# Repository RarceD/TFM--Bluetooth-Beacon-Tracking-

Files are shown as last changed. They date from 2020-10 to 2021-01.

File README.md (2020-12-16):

# Introduction #
BLE tracking system based on ESP32 uC and nrf52832 iBeacon. The main idea is to stablish a net of beacons which
comunicate with the ESP32 masters via Bluetooth Low Energy on Beacon Mode.

Every beacon wake up every 1200ms and send their uuid, mayor, minor, battery and rssi. The most important parameter is the rssi because with that we can calculate the distance between masters and I can positionate them on a map.

The visualize tool is made with Python and Pygame, all the masters send data to a free to use broker and the console is listenning incoming messages in order to calculate the distance and situate them on the static map.
## Hardware ##
### ESP32 master and  nrf52832 ###
I have develop a simple esp32 board that can be powered via 220@VAC and every minute it listen to the slaves and calculate the distance between beacons.
| Board Specifications  |  ESP32 WROVER |  nrf52832 |
| :---:|:---:| :---: |
| Flash | 448kB | 256 kB | 
| RAM | 520kB | 32 kB | 
| Consumption on sleep  | 10uA | 1.9 μA at 3 V | 

### Images beacon ###
In the following image we can see the pcb of the esp32 beacon device and the master esp32 pcb:

<p align="center">
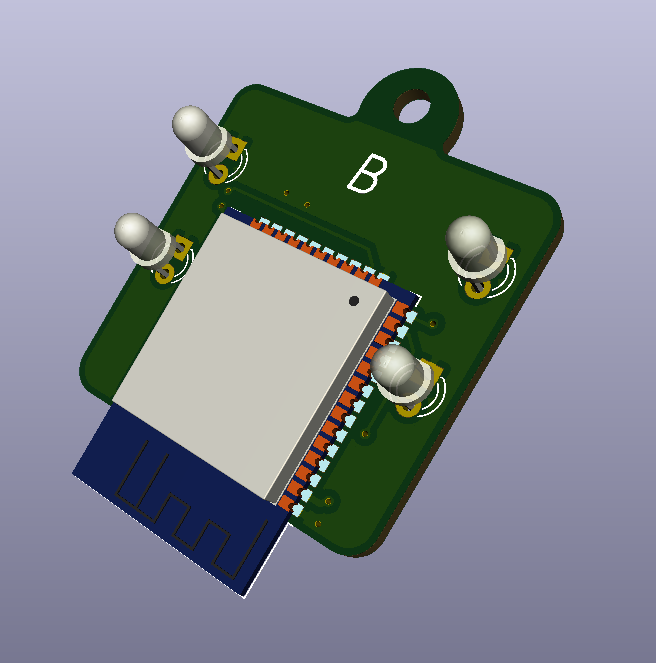
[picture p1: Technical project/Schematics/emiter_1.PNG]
    
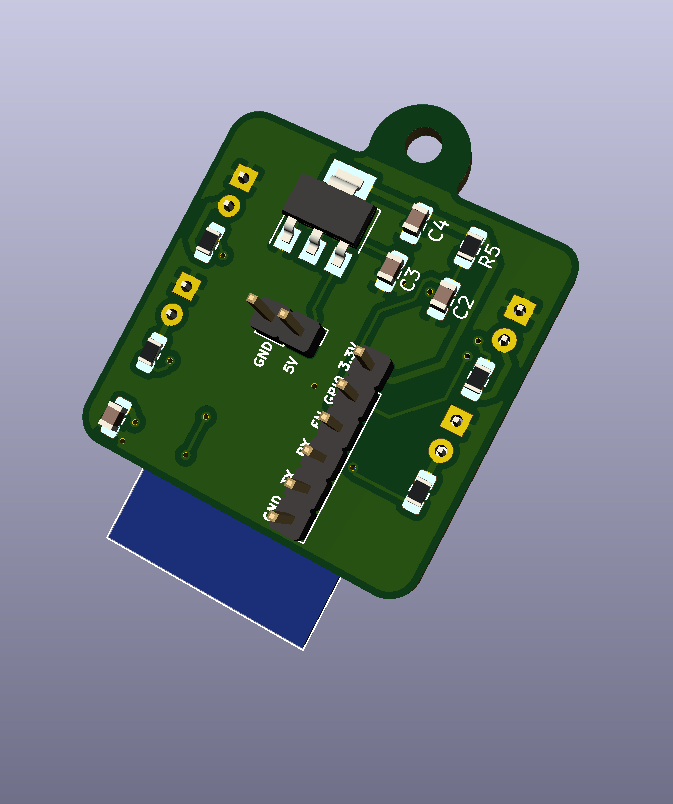
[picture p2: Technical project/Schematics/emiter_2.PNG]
    
</p>

The real boards:

<p align="center">
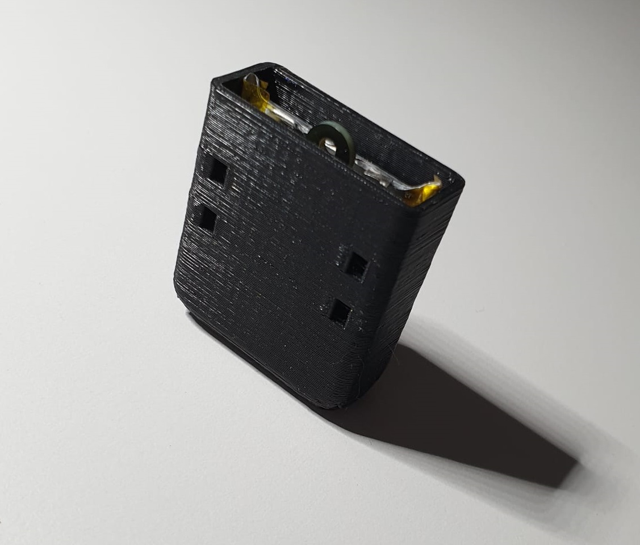
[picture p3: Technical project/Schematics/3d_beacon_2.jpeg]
    
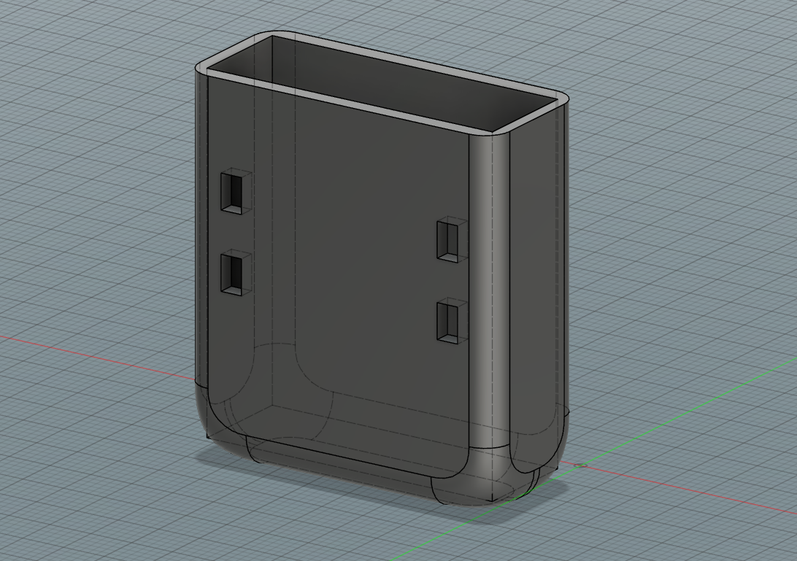
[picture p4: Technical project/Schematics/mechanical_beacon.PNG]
    
</p>

### Images master listener ###
Kicad files also included:

<p align="center">
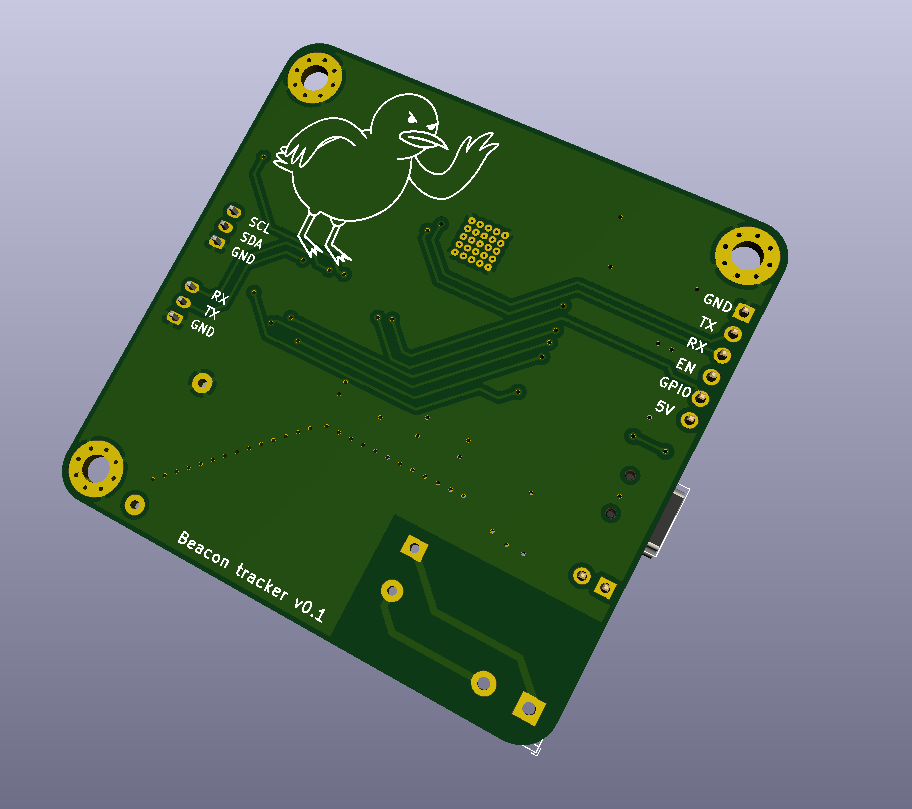
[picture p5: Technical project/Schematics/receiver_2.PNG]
    
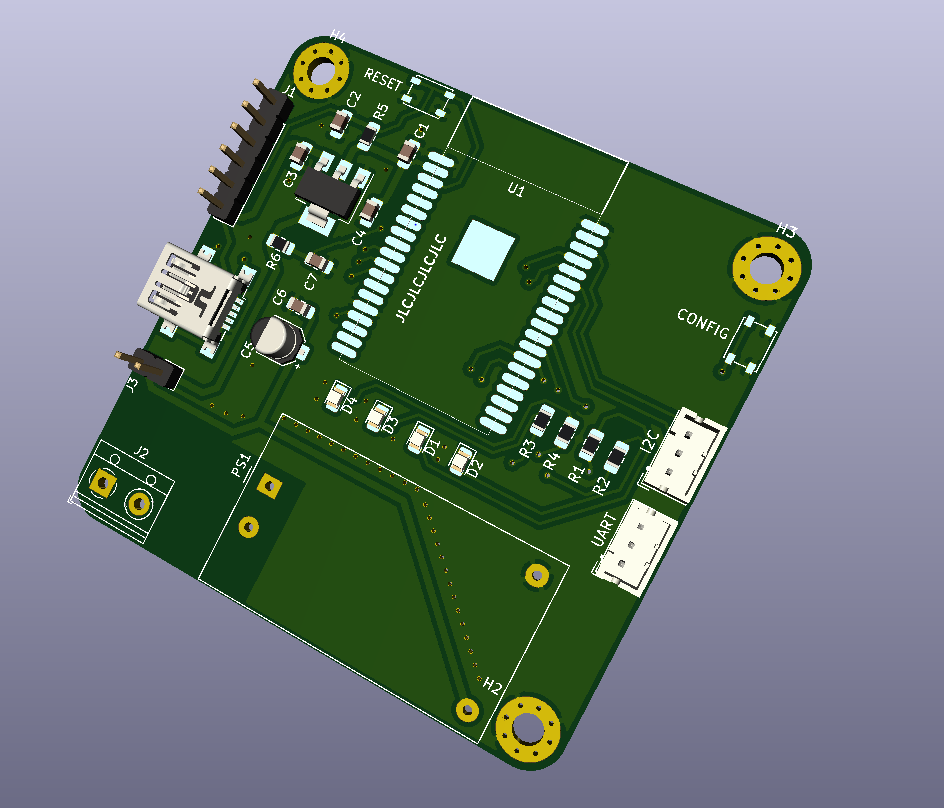
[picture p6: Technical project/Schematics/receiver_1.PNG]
    
</p>

The real boards:
<p align="center">
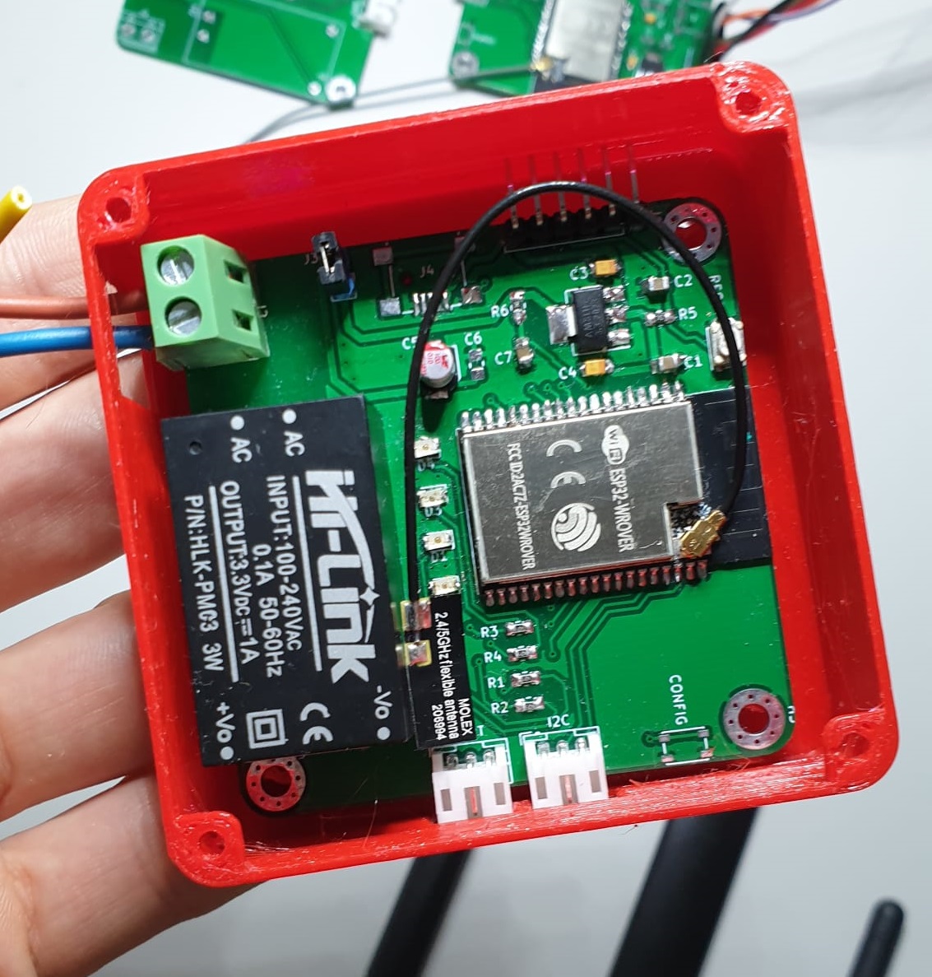
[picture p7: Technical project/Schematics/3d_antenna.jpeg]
    
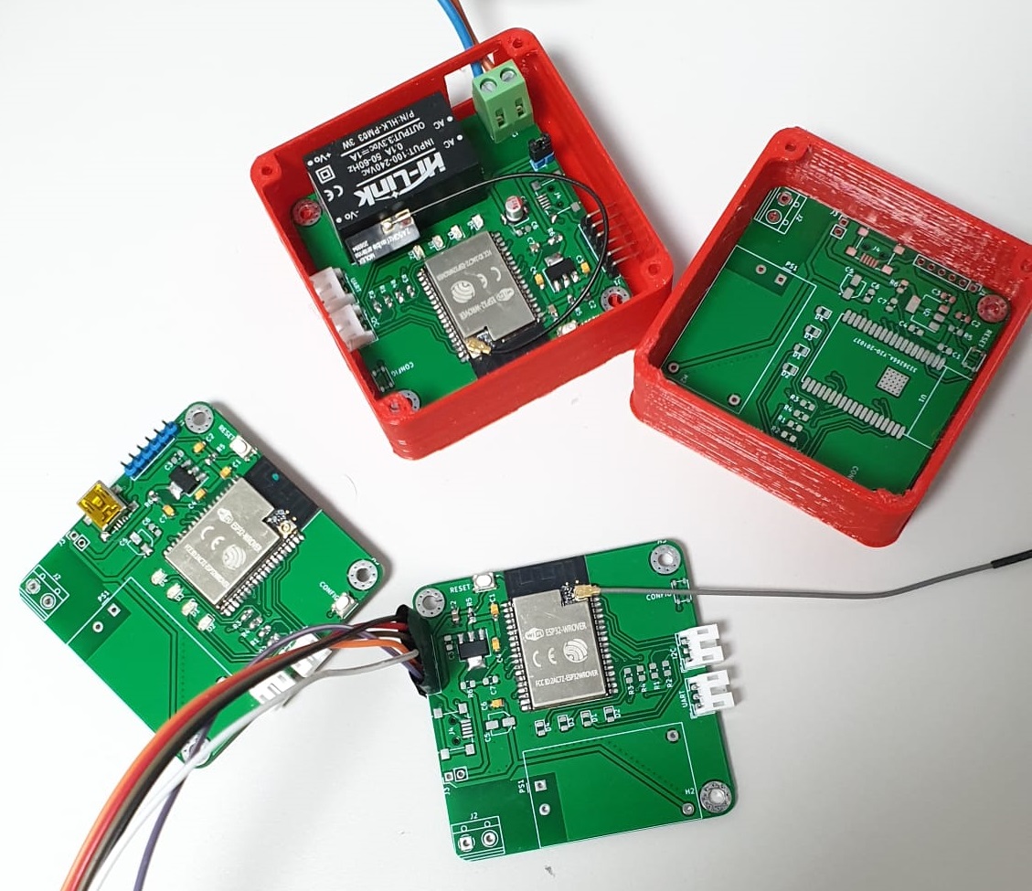
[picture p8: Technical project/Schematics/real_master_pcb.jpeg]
    
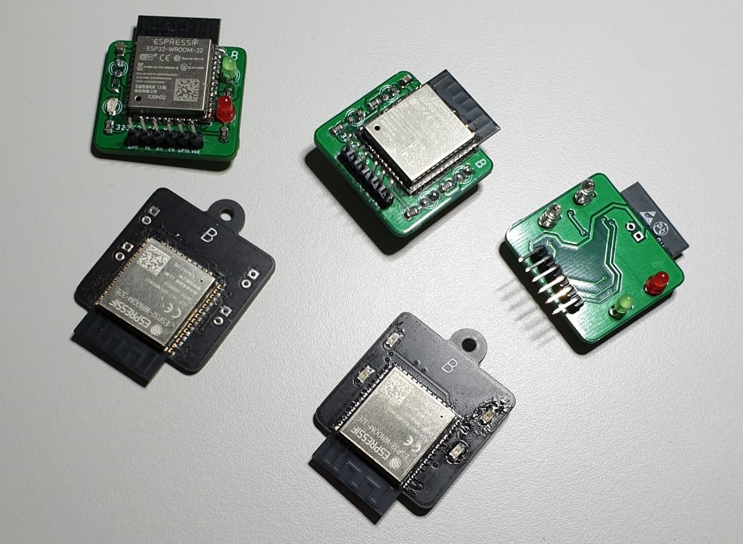
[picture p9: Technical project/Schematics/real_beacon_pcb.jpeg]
    
</p>

## Software ##
### Trilateration ###
If two elements on a net are listened by two masters the algorithm will calculate the middle distance of both of them acording to the strengh of the signal received. Appling trilateration we can obtein the position between three masters and only one beacon sending data. I don't cosider more than 3 masters detected the same beacon.

<p align="center">
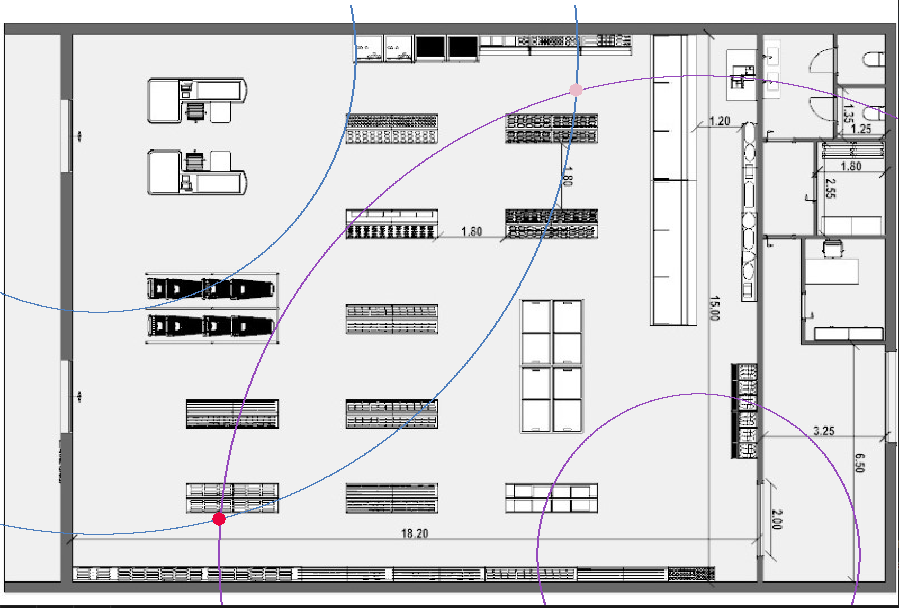
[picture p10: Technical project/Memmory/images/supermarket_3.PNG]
    
</p>

## 3D Printing ##
The electronics need a case in order not to be touch by no people, thats why I have design a simple model in Freecad:

<p align="center">
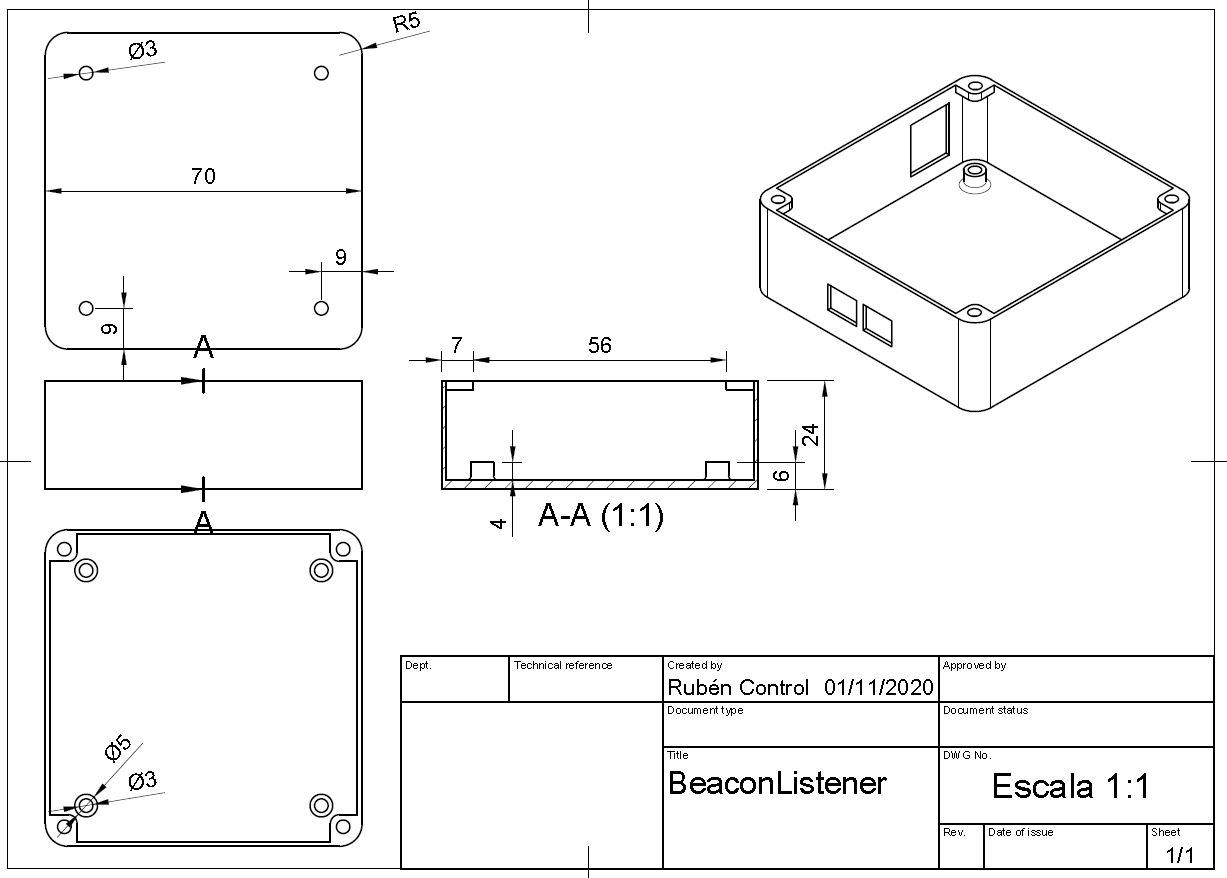
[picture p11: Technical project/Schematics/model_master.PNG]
    
</p>

## Visualizer ##
For making the fastest prototype of the visualization tool I have program a pygame console that is connected to mqtt and always listening to the master messages.
I'm using free mqtt broker: 
```python 
 broker_address = "broker.mqttdashboard.com"
```
It has fall out just one time in more than 3 months, it seems right.

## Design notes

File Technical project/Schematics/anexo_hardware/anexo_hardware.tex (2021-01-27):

\documentclass[paper=a4, fontsize=11pt,twoside]{scrartcl}	% KOMA

\usepackage[a4paper,pdftex]{geometry}	% A4paper margins
\setlength{\oddsidemargin}{5mm}			% Remove 'twosided' indentation
\setlength{\evensidemargin}{5mm}

% \usepackage[english]{babel}
\usepackage[protrusion=true,expansion=true]{microtype}	
\usepackage{amsmath,amsfonts,amsthm,amssymb}
\usepackage{graphicx}
\usepackage[spanish]{babel}
\usepackage[hidelinks]{hyperref}
\usepackage{graphicx}
\usepackage{xcolor}
\usepackage{fancyhdr}
\usepackage{hyperref}
\newcommand{\HRule}[1]{\rule{\linewidth}{#1}} 	% Horizontal rule
\usepackage{float}

\makeatletter							% Title
\def\printtitle{%						
    {\centering \@title\par}}
\makeatother									

\makeatletter							% Author
\def\printauthor{%					
    {\centering \large \@author}}				
\makeatother							

\title{	\normalsize \textsc{ANEXO 1: DISEÑO DE HARDWARE} 	% Subtitle
		 	\\[2.0cm]								% 2cm spacing
			\HRule{0.5pt} \\						% Upper rule
			\LARGE \textbf{\uppercase{Sistemas de posicionamiento de objetos mediante la tecnología Bluetooth Low Energy, modo Beacon}}	% Title
			\HRule{2pt} \\ [0.5cm]		% Lower rule + 0.5cm spacing
			\normalsize \today			% Todays date
		}
\author{
		Rubén Arce Domingo\\	
		Máster en automatización y robótica\\	
        industrial\\
        akimbo170@gmail.com \\
        % \texttt{akimbo170@gmail.com} \\
}
\begin{document}
\thispagestyle{empty}		% Remove page numbering on this page
\printtitle					% Print the title data as defined above
  	\vfill
\printauthor				% Print the author data as defined above
\newpage

% \title{Anexo desarrollo de hardware}

% \author{Rubén Arce}
% \date{\today}
% \maketitle
\cleardoublepage
\tableofcontents
\listoffigures
\cleardoublepage
\pagestyle{fancy}
\fancyfoot[R]{Rubén Arce}
\fancyfoot[L]{BLE Tracking - 2021}

\section{Introducción}
    Los diseños eléctricos y el trazado de las pistas del circuito se han llevado a cabo con Kicad en 
    su versión 5.1.6. Se ha empleado este programa debido a que, en primer lugar es de software libre y
    completamente gratuito y, en segundo lugar, debido a que puede funcionar en Linux. Además de que es capaz de llevar a cabo 
    cualquier diseño profesional sin problema de licencias o versiones incompatibles.

    Por otro lado, todas las PCBs se han fabricado en dos capas con un espesor estándar de 1,6mm y con acabado superficial
    HASH plomo estaño en los primeros prototipos. En la versión final se empleará el acabado ENIG, o de oro 
    electrolítico, para mejorar las especificaciones y durabilidad de la misma.

    Por último mencionar que se han empleado tanto componentes SMD como through hole y se ha priorizado el precio en la selección de los mismos.
\section{Emisor Beacon}
    \subsection{Aspectos a considerar}
        Las premisas para seleccionar el mejor microcontrolador han sido las siguientes: 
        \begin{enumerate}
            \item Bajo consumo.
            \item Tamaño reducido.
            \item Bluetooth y posibilidad de wifi en caso de eliminar el dispositivo emisor.
            \item Precio muy competitivo.
        \end{enumerate}
    \subsection{Circuito eléctrico}
        \subsubsection{Microcontrolador} 
            En el caso del microcontrolador, se ha optado por un ESP32 de la empresa Espressif (\url{https://www.espressif.com/})
            debido en gran medida a que dispone de wifi y bluetooth, así como de unas excelentes herramientas
            de desarrollo de software. 
        \subsubsection{Alimentación} 
            Para llevar a cabo la alimentación del microcontrolador y, teniendo en cuenta que se han de garantizar los 3,3V en la entrada
            del micro, se ha optado por una batería de Ion-Litio de 1400mAh que además tiene un tamaño reducido. El rango de tensión de la
            tarjeta va de 12V a 3,6V en el caso de que se opte por otro método de alimentación.
    \subsection{PCB de control}
        \paragraph{}
        Una vez tenidas en cuenta estas especificaciones, en el esquema eléctrico se ha llevado a cabo el ruteo de la tarjeta.
        Vemos que se ha elaborado el trazado de pistas con planos de masa para prevenir interferencias electromagnéticas
        y conseguir que no afecte demasiado a la electrónica. En las diguras 1 y 2 podemos ver imágenes de los renderizados y circuitos 
        eléctricos.
        \begin{center}
            \begin{figure}[H]
                \centering
                
                
                \caption{Renderizado de PCB del Beacon.}
                \label{fig:mesh8}
            \end{figure}    
        \end{center}
        \begin{center}
            \begin{figure}[H]
                \centering
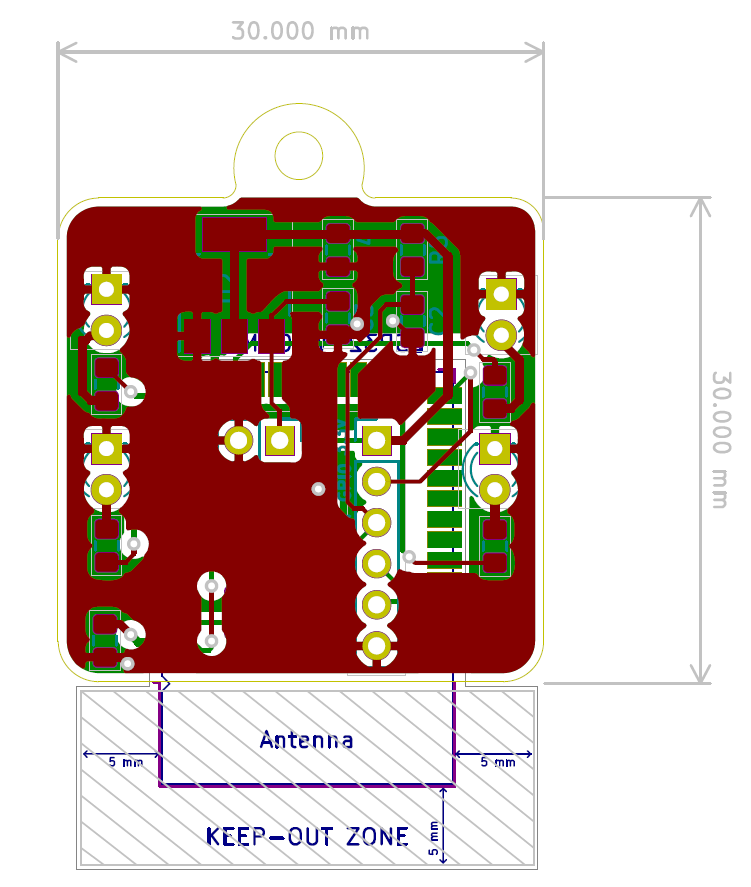
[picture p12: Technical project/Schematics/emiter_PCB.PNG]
                
                \caption{PCB del Beacon obtenida con Kicad.}
                \label{fig:mesh9}
            \end{figure}    
        \end{center}
        Se ha dejado la zona de la antena despejada para mejor la ganancia de la misma y en consecuencia el alcance, en el caso 
        del Beacon se usarán las antenas que integra el microcontrolador.
    \subsection{Imágenes reales}
        \paragraph{}
        Tras llevar a cabo la fabricación de las tarjetas prototipo podemos ver los resultados en la figura 3.
        \begin{center}
            \begin{figure}[ht]
                \centering
                
                \caption{PCB real fabricada y soldada}
                \label{fig:mesh3}
            \end{figure}    
        \end{center}       
\section{Receptor Beacon o gateway}
    \subsection{Aspectos a considerar}
        \begin{enumerate}
            \item Velocidad de procesamiento: El número máximo de equipos a localizar puede ser superior a 500, es por ello 
            por lo que quedan descartados los microcontrodores de 8 bits y cristales de menos de 16MHz.
            \item Wifi/bluetooth: Ha de escuchar a los Beacons y subir los datos a internet, es por ello por lo que se hace 
            indispesable que cuente con hardware que permita las dos acciones.
        \end{enumerate}

    \subsection{Circuito eléctrico}
        \subsubsection{Microcontrolador} 
            Teniendo en cuenta estas condiciones previas y contando con procesadores ESP32 del diseño anterior, se ha optado por compartir 
            el procesador para ambos equipos. Con esto conseguimos que el software y librerías sean compatibles al 100\% y se ahorre tiempo
            de desarrollo.
        \subsubsection{Alimentación} 
            En este caso puesto que la tarjeta se encontrará estática en un lugar cercano a un enchufe se brindan las siguientes opciones
            de alimentación:
            \begin{enumerate}
                \item 220 VAC.
                \item 12 VDC.
                \item 5 VDC, en el caso de que se disponga de un ordenador cerca se podría conectar por USB.
            \end{enumerate}
            En la figura 4 podemos ver el circuito responsable, mediante un jumper. Se facilita el cambio de alimentación para las distintas necesidades 
            de los clientes.
            \begin{center}
                \begin{figure}[h]
                    \centering
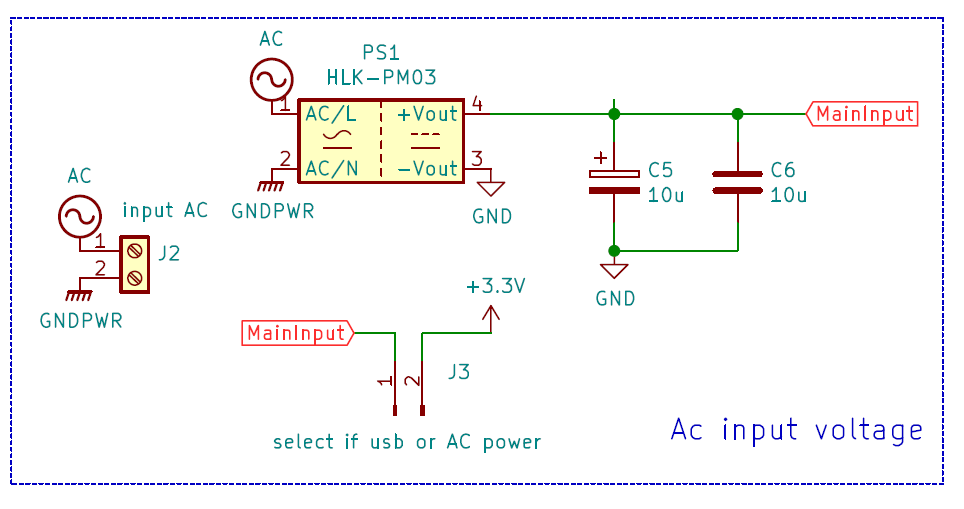
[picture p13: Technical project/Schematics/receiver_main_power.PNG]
                    
                    \caption{Fuentes de alimentación de la PCB master.}
                    \label{fig:mesh4}
                \end{figure}    
            \end{center}    
    \subsection{PCB de control}
        Se ha optado por llevar a cabo el trazado de pistas de alimentación por la cara top y las de señal por la bottom, vemos que hay dos 
        conectores en los extremos de la tarjeta, uno con una UART para comunicarse con otros sistemas de la planta y otro conector para sensores
        i2c, pensado para la lectura de humedad y temperatura, así como para el envío de estos datos a la web de control. En la figura 5 se aprecia 
        con mayor detalle la PCB del master en un renderizado obtenido con Kicad.

        En el apartado de planos se puede ver con mayor detalle el esquema eléctrico y dimensiones de la tarjeta. 
        \begin{center}
            \begin{figure}[ht]
                \centering
                
                
                \caption{Renderizado de PCB del master o gateway.}
                \label{fig:mesh5}
            \end{figure}    
        \end{center}
        \begin{center}
            \begin{figure}[ht]
                \centering
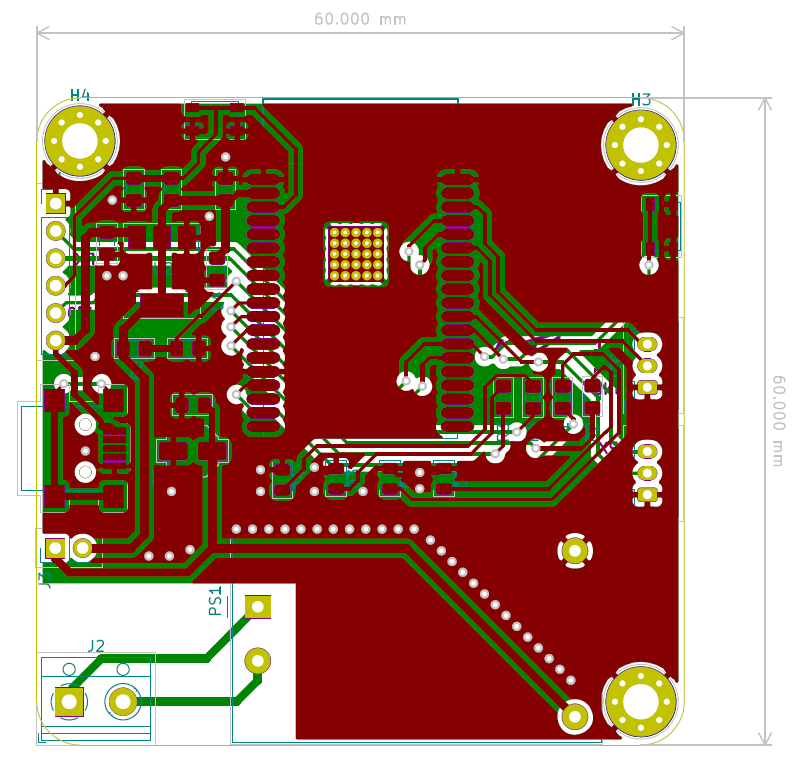
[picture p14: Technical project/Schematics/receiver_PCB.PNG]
                
                \caption{Renderizado de PCB del master o gateway.}
                \label{fig:mesh6}
            \end{figure}    
        \end{center}
    \subsection{Imágenes reales}
        Por último y tras fabricar las tarjetas e imprimir las cajas que lo contienen se obtiene el resultado de las figuras 6 y 7.
        \begin{center}
            \begin{figure}[ht]
                \centering
                
                
                \caption{Imágenes reales de la PCB gateway.}
                \label{fig:mesh7}
            \end{figure}    
        \end{center}

    \subsection{Conclusiones}
        Una vez recibidas las PCBs se fueron ensamblando a mano sin mayor incidente que la confusión en la 
        posición de un led que, por supuesto, tras cargar el firmware en la tarjeta, no se iluminó.
        Solucionado el incidente, la versión 1 de las tarjetas fue, por suerte, la definitiva.
\end{document}

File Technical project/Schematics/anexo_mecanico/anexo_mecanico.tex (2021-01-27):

\documentclass[paper=a4, fontsize=11pt,twoside]{scrartcl}	
\usepackage[a4paper,pdftex]{geometry}	
\setlength{\oddsidemargin}{5mm}			
\setlength{\evensidemargin}{5mm}
\usepackage[protrusion=true,expansion=true]{microtype}	
\usepackage{amsmath,amsfonts,amsthm,amssymb}
\usepackage{graphicx}
\usepackage[spanish]{babel}
\usepackage[hidelinks]{hyperref}
\usepackage{hyperref}
\usepackage{graphicx}
\usepackage{xcolor}
\usepackage{fancyhdr}
\newcommand{\HRule}[1]{\rule{\linewidth}{#1}} 	% Horizontal rule
\usepackage{float}

\makeatletter							% Title
\def\printtitle{%						
    {\centering \@title\par}}
\makeatother									

\makeatletter							% Author
\def\printauthor{%					
    {\centering \large \@author}}				
\makeatother							

\title{	\normalsize \textsc{ANEXO 2: DISEÑO DE MECÁNICO} 	% Subtitle
		 	\\[2.0cm]								% 2cm spacing
			\HRule{0.5pt} \\						% Upper rule
			\LARGE \textbf{\uppercase{Sistemas de posicionamiento de objetos mediante la tecnología Bluetooth Low Energy, modo Beacon}}	% Title
			\HRule{2pt} \\ [0.5cm]		% Lower rule + 0.5cm spacing
			\normalsize \today			% Todays date
		}
\author{
		Rubén Arce Domingo\\	
		Máster en automatización y robótica\\	
		industrial\\
		akimbo170@gmail.com\\
        % \texttt{akimbo170@gmail.com} \\
}
\begin{document}
\thispagestyle{empty}		% Remove page numbering on this page
\printtitle					% Print the title data as defined above
  	\vfill
\printauthor				% Print the author data as defined above
\newpage
\cleardoublepage
\tableofcontents
\listoffigures
\cleardoublepage
\pagestyle{fancy}
\fancyfoot[R]{Rubén Arce}
\fancyfoot[L]{BLE Tracking - 2021}
\section{Introducción}
    Para llevar a cabo el diseño mecánico de estas piezas concretas se ha decidido emplear Freecad, un
    programa de software libre que permite hacer modelos sencillos de forma gratuita.
    Se ha empleado la versión 12.0, corriendo el mismo en una Raspberry pi 4 de 4Gb de RAM. Este es el único
    programa de diseño 3D que corre en Linux y además consume pocos recursos.
    \paragraph{}
    Los primeros prototipos se han llevado a cabo con una impresora 3D Anet A8 con el firmware de Marling
    2.0 y con material PLA de 1,75mm, la velocidad de impresión ha sido de 40 mm/s.
    \paragraph{}
    El programa slicer utilizado ha sido Cura en su versión v4.4. Para los prototipos se ha empleado un relleno del 5\% y una distancia
    entre capas de 0,3mm. Para la versión del cliente se ha optado por un relleno del 40\% y una distancia entre capas de 0,12mm.
\section{Emisor Beacon}
    \subsection{Aspectos a considerar en el diseño}
        Antes de afrontar el apartado de diseño se han reunido las condiciones indispensables para 
        conseguir un modelo acorde a las necesidades del cliente.
        \begin{enumerate}
            \item Estéticamente atractivo.
            \item Pequeñas dimensiones.
            \item Cómodo para llevar colgado del cuello.
            \item Facilidad para desmontar y recargar las baterías o pilas.
            \item Limitaciones en el tamaño de máximo 220x220x250 mm debido al volumen de impresión.
        \end{enumerate}
    \subsection{Planos y dimensiones}
        Una vez llevado a cabo el diseño se han obtenido los planos y se ha procedido a la impresión 3D de los mismos. En la figura 1 
        se pueden ver las dimensiones del Beacon.
        \begin{center}
            \begin{figure}[h]
                \centering
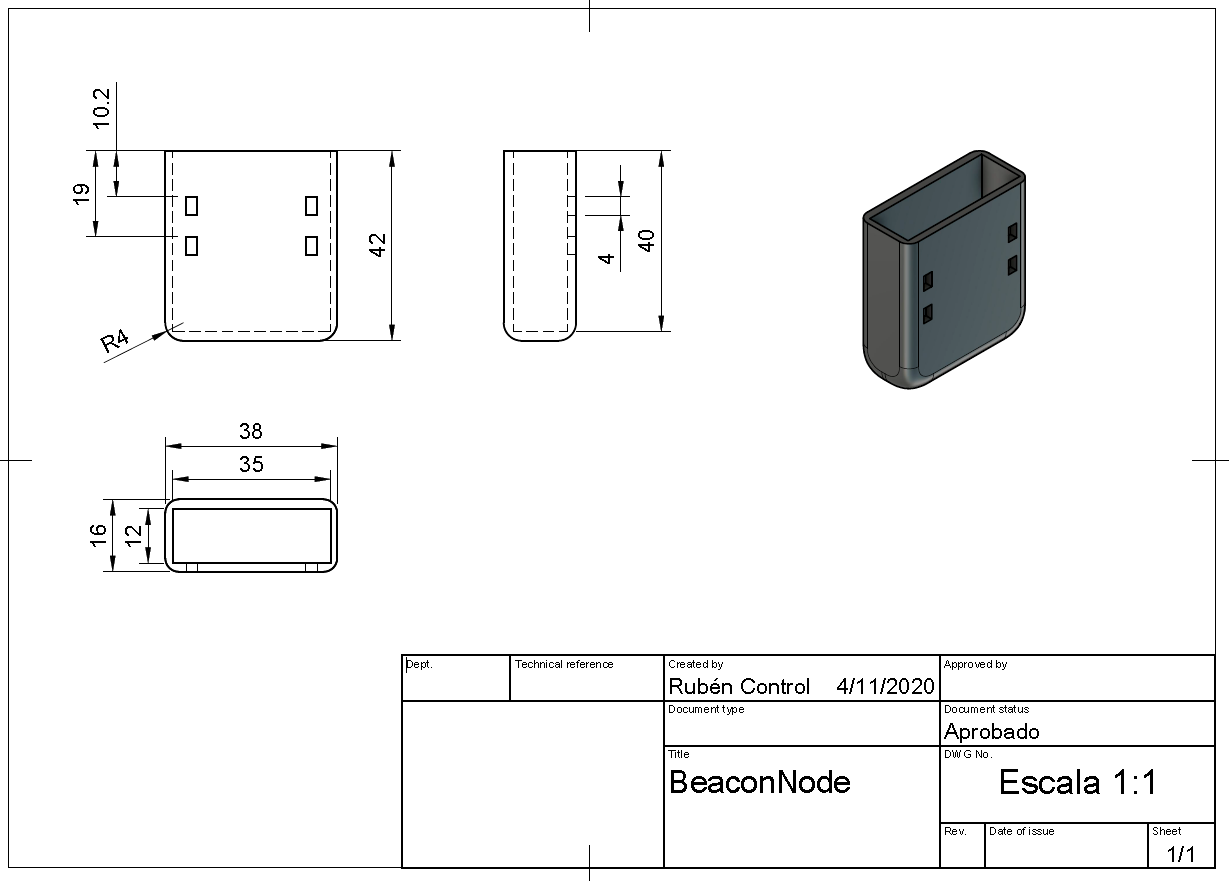
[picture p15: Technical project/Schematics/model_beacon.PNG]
                
                \caption{Plano y dimensiones del Beacon}
                \label{fig:mesh1}
            \end{figure}
        \end{center}
    \subsection{Imágenes de renderizado}
        Obtenemos el ensablaje desde el software CAD y en la figura 2 se muestra el renderizado del equipo.
        \begin{center}
            \begin{figure}[t]
                \centering
                
                \caption{Renderizado de la PCB}
                \label{fig:mesh1}
            \end{figure}
        \end{center}
    \subsection{Imágenes reales}
        Tras verificar el diseño en el ordenador se carga el filamento 3D y se procede a llevar a cabo la impresión, un par de horas más tarde
        se obtuvo la figura 3.
        \begin{center}
            \begin{figure}[H]
                \centering
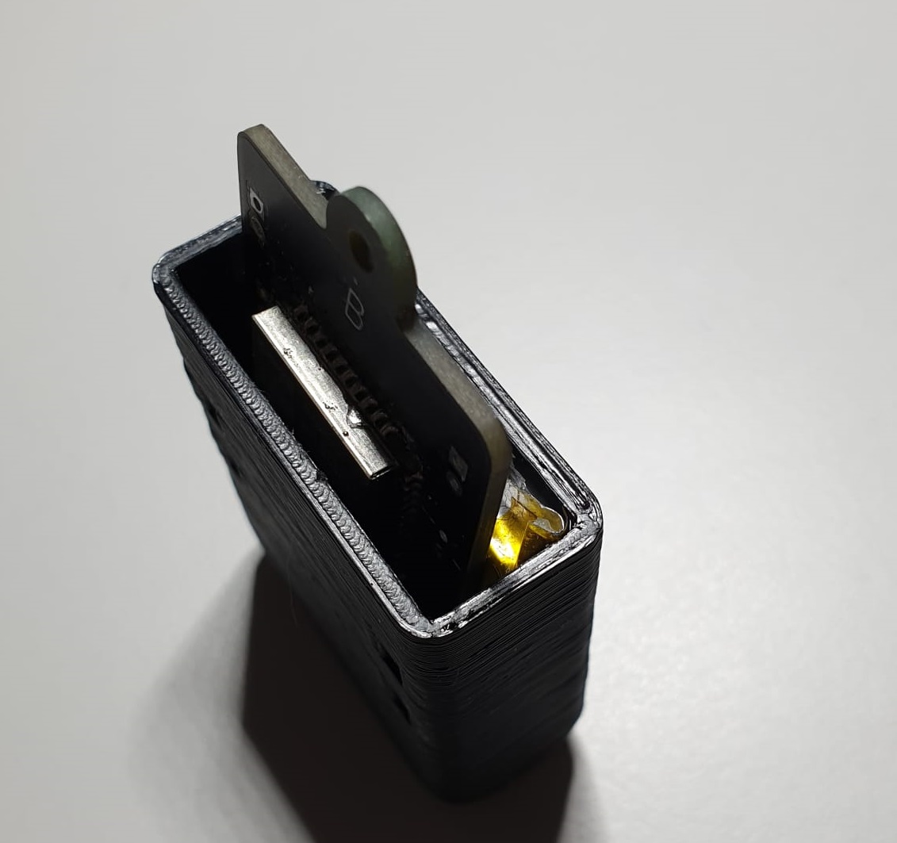
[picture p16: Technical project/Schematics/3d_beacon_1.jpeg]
                
                
                \caption{Imagen real del Beacon con batería.}
                \label{fig:mesh1}
            \end{figure}
        \end{center}

\section{Receptor Beacon o gateway}
    \subsection{Aspectos a considerar en el diseño}
        De nuevo se apuesta por reunir las especificaciones que ha de tener el contenedor de la electrónica:
        \begin{enumerate}
            \item Estéticamente atractivo, puesto que va a estar físicamente a la vista.
            \item Pequeñas dimensiones y discreto.
            \item Limitaciones en el tamaño de máximo 220x220x250 mm debido al volumen de impresión.
            \item Estructura sólida que garantize un buen agarre de la PCB en vertical.
        \end{enumerate}
        \paragraph{}
        Se ha de tener en cuenta que este equipo se encontrará en un lugar elevado atornillado o pegado a la pared, 
        es por ello por lo que se ha de hacer una caja robusta en la que no entre suciedad. 
    \subsection{Planos y dimensiones}
        \paragraph{}
        Partiendo de las dimensiones de la tarjeta, a continuación, en la figura 4, se
        muestran las medidas de la caja que lo alberga. 
        \begin{center}
            \begin{figure}[h]
                \centering
                
                \caption{Plano de la caja del emisor.}
                \label{fig:mesh1}
            \end{figure}
        \end{center}
        \paragraph{}
        \paragraph{}

    \subsection{Imágenes de renderizado}
        Como se puede observar en la figura 5 se presentan los renderizados:
        \begin{center}
            \begin{figure}[h]
                \centering
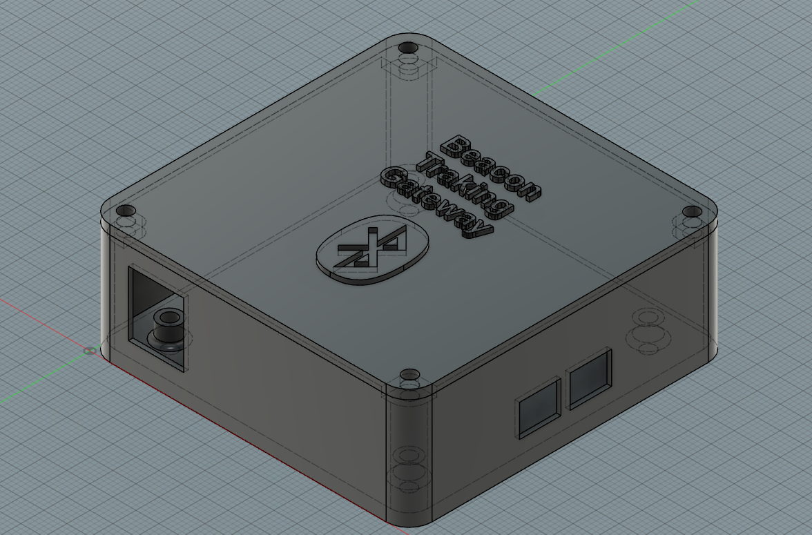
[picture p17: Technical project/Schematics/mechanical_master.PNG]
                
                \caption{Renderizado de la caja del emisor.}
                \label{fig:mesh1}
            \end{figure}
        \end{center}
        \paragraph{}

    \subsection{Imágenes reales}
        Una vez impresas las piezas y sin necesidad de lijar o ajustar algún apriete o tolerancia,
        el resultado es el que se expone en la figura 6.
        Introduciendo la electrónica dentro podemos ver el diseño completo en la figura 7.
        \begin{center}
            \begin{figure}[h]
                \centering
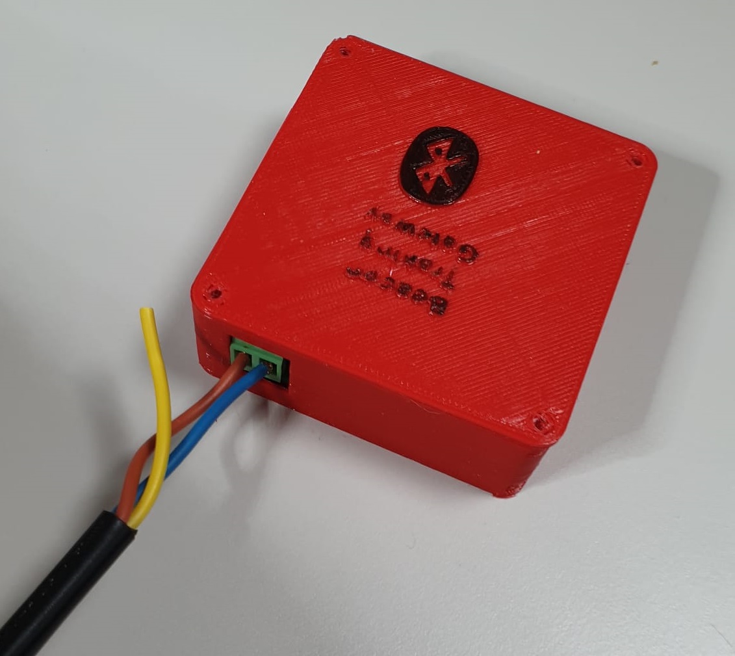
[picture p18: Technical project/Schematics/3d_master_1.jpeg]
                
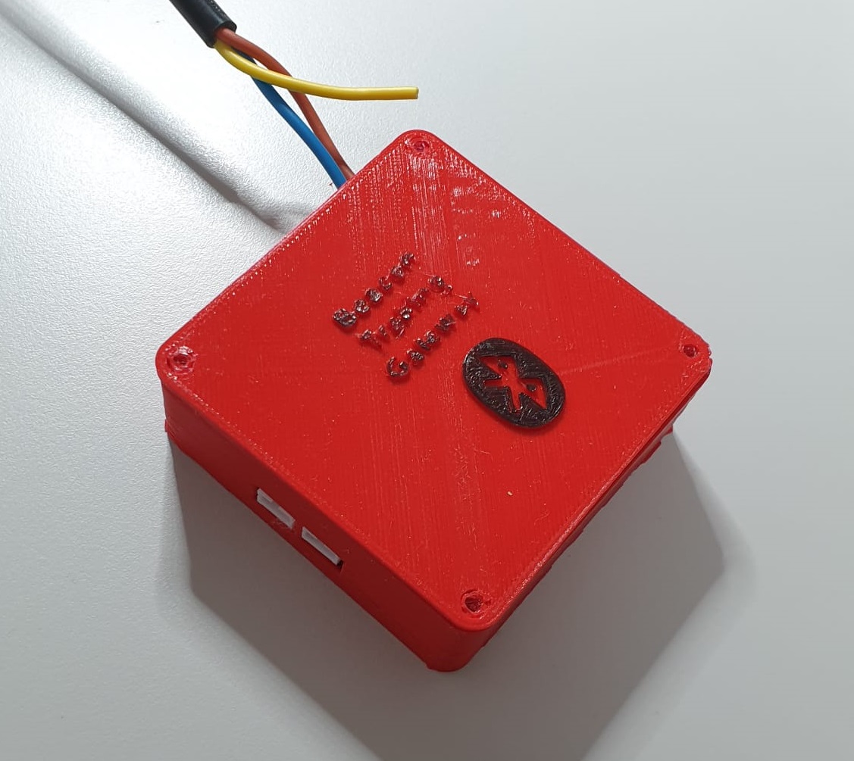
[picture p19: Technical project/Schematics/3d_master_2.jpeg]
                
                \caption{Caja real del receptor con dimensiones.}
                \label{fig:mesh1}
            \end{figure}
        \end{center}
        \paragraph{}
        \begin{center}
            \begin{figure}[h]
                \centering
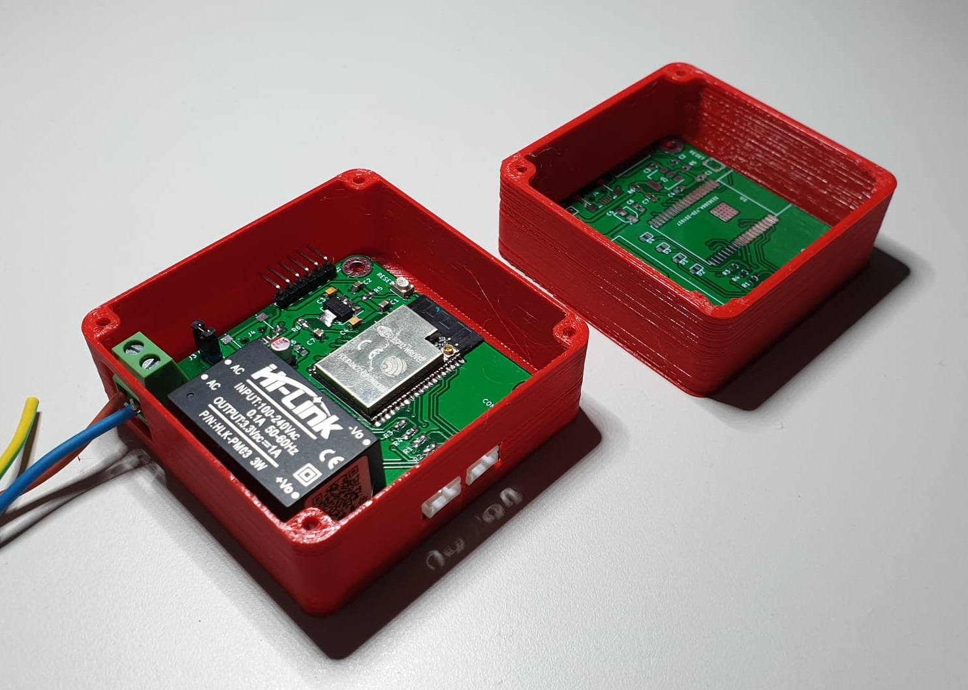
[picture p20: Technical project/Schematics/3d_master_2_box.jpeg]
                
                
                \caption{Caja real del receptor con electrónica dentro.}
                \label{fig:mesh1}
            \end{figure}    
        \end{center}
\section{Conclusiones}
    Tras desarrollar los primeros prototipos se procedió a llevar a cabo una prueba real con los mismos 
    en un entorno industrial para comprobar si era necesaria una versión 2.0 de los mismos, los resultados
    dejaron claro que este primer diseño era el acertado.

    Exceptuando una caída accidental, todos los diseños sobrevivieron a la prueba. Sin embargo, no se
    han podido tomar imágenes dentro de la planta, debido a las medidas de seguridad y a la ausencia
    de permisos por parte de la administración de la empresa.

    Igualmente los equipos de las fotos anteriores fueron los empleados y se aseguraron a unas estanterías con cinta de doble
    cara, con lo que se pudo hacer una una verificación del funcionamiento el firmware y una mejora del mismo.

\end{document}

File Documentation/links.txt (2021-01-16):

Características del esp32:
https://www.espressif.com/sites/default/files/documentation/esp32_technical_reference_manual_en.pdf

https://www.espressif.com/sites/default/files/documentation/esp32_hardware_design_guidelines_en.pdf
Ejemplos de código del esp-software development kit}
https://github.com/espressif/esp-idf

Web oficial del estándar Bluetooth
https://www.bluetooth.com/

https://accent-systems.com/es/producto/ibks-105/}{ ACCENT - Ejemplo de una empresa que tiene un equipo
similar al desarrollado}

https://www.boe.es/diario_boe/txt.php?id=BOE-A-2002-694}{BOE - Orden CTE/23/2002, de 11 de enero, por la que se establecen condiciones para la presentación de determinados estudios y certificaciones por operadores de servicios de radiocomunicaciones.}

https://www.boe.es/buscar/act.php?id=BOE-A-2014-4950}{BOE - Ley 9/2014, de 9 de mayo, General de Telecomunicaciones.}

http://www.sharelatex.com}{Documentación sobre el editor de texto Latex empleado}

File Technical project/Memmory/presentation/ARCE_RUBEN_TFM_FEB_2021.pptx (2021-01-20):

## Sistemas de posicionamiento de objetos mediante la tecnología Bluetooth Low Energy, modo Beacon

Master en automatización industrial y robótica
Febrero 2021
Trabajo Fin de Master

Autor: Rubén Arce Domingo

## ÍNDICE:

Rubén Arce - 2021

1. Descripción del proyecto
2. Problemática a abordar
3. Posibles soluciones
4. Introducción a tecnología Bluetooth low energy - BLE
5. Beacon Mode
6. Diseño de hardware: PCBs
7. Diseño de producto: Impresión 3d
8. Diseño de Firmware: Algoritmos de posicionamiento.
9. Acondicionamiento y ubicación de equipos
10. Software de visualización
11. Viabilidad Económica

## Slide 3

1. Descripción del proyecto

Rubén Arce - 2021

PRECIO
SENCILLEZ
FIABILIDAD

Objetivo:
- Diseñar un sistema capaz de posicionar un objeto o persona en un espacio interior cerrado.
- Herramienta de visualización intuitiva y que ofrezca información de todos los equipos instalados.
- Detección de fallos en los equipos así como lejanía de los mismos en tiempo real.
- Fácil instalación para un usuario no técnico.
- Precio competitivo.

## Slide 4

2. Problemática a abordar

1. Marketing: Estudios de mercado y de necesidad de los clientes. Elaboración de un "heat map", o mapa de las zonas con más afluencia de gente.
2. Sanidad: Monitorización de pacientes en planta.
3. Seguridad: Únicamente los empleados con autorización y proximidad podrán llevar a cabo acciones.

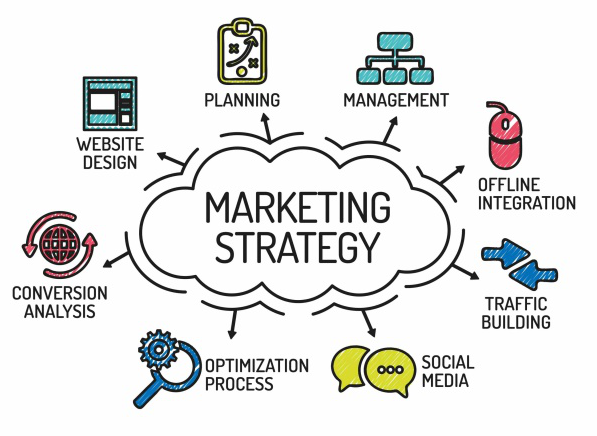
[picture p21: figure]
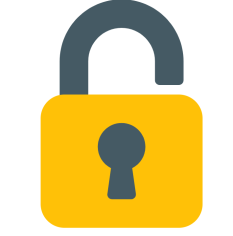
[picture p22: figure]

1. Vandalismo: Conociendo la localización de los equipos dentro de un local cerrado, en el momento en el que se deja de situar un elemento en el mapa, se puede dar la voz de alarma ante un robo.
2. Propaganda y nueva forma de publicidad: Activar acciones en función de la localización en determinados puntos de interés permite llevar a otro nivel las ideas de los publicistas.

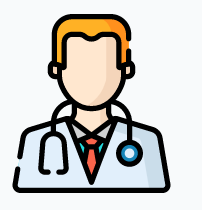
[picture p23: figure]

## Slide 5

3. Posibles soluciones

2.1 Opciones de sistemas de posicionamiento:
- GPS
- Wifi
- Bluetooth
Comparativa:

Tecnología | Coste | Complejidad | Distancia | Consumo Energético
GPS | Elevado | Baja | Ilimitada | Muy Alto
Wifi | Medio | Medio | 50m | Alto
Bluetooth | Bajo | Media | 100m | Muy bajo

Posicionamiento
Subida de datos

Rubén Arce - 2021

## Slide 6

3. Posibles soluciones

2.1 Opciones de sistemas de posicionamiento:
- MQTT
- HTTP Post
- ESP Now
Comparativa:

Tecnología | Coste | Complejidad | Velocidad de datos
MQTT | No | Baja | Elevada
HTTP POST | Medio | Baja | Baja
ESP NOW | No | Media | Alta

Posicionamiento
Subida de datos

Rubén Arce - 2021

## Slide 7

4. Introducción a la tecnología BLE

«Bluetooth is a wireless technology standard used for exchanging data between fixed and mobile devices over short distances using UHF radio waves in the industrial, scientific and medical radio bands, from 2.402 GHz to 2.480 GHz, and building personal area networks (PANs) » Bluetooth Special Interest Group

R_(t^0) =R_O ·(1+ α· ∆t^0 )

- Materiales superconductores:
  - TIPO 1: Paso brusco al estado de superconductor, temperaturas del orden de -265ºC
  - TIPO 2: Paso gradual desde el estado normal al estado de superconductor. Por encima de los -200ºC.

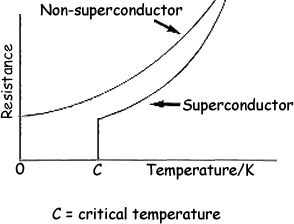
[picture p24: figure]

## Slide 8

5. Beacon Mode

Superconducting Magnetic Energy Storage o SMES

¿Como se estabiliza la microgrid?:
Ante subidas de tension originadas por la conexión o desconexión de cargas permite almacenar sobretensiones y cederlas frente a caídas en la red .

Funcionamiento:
- La corriente por la bobina se mantiene constante de forma indefinida.
- Cargas y descargas en milisegundos.
- Permite absorber o ceder energía de la microgrid.

Partes:
- Bobina superconductora
- Electrónica de potencia
- Sistema de refrigeración

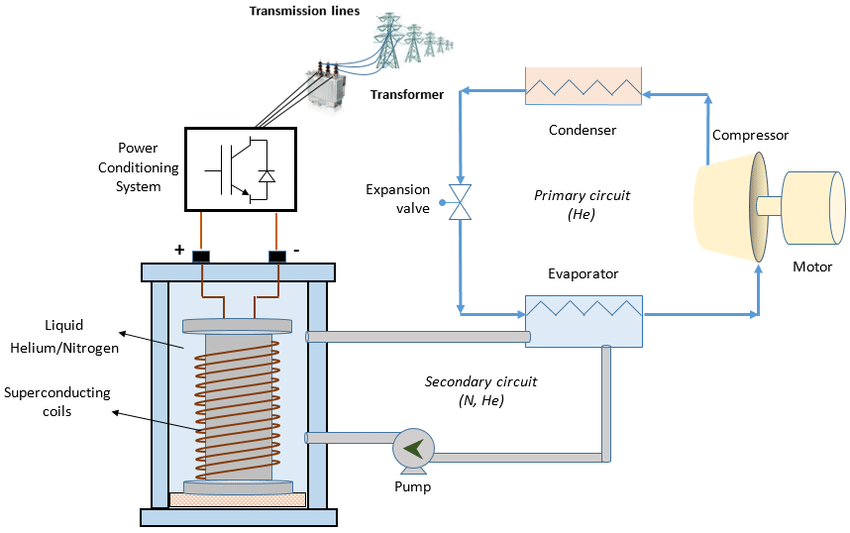
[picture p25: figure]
Imagen relacionada

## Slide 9

6. Diseño de hardware: PCBs

Se han tenido en cuenta materiales, forma y dimensiones

Propiedad de diseño | Alternativas: | Opción elegida: | Motivo de elección:
MATERIALES | NbTi YBCO MgB2 | Cerámica NbTi | Tipo I de material superconductor. Mejor respuesta ante ensayos
FORMA | Toroidal Solenoidal Multi-solenoidal | Solenoidal | Alta densidad de campo magnético No genera campos perpendiculares por lo que menor corrosión del recipiente.

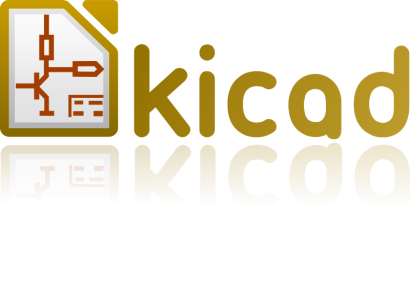
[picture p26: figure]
Resultado de imagen de kicad logo
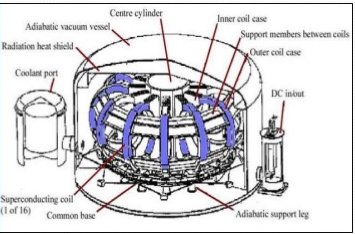
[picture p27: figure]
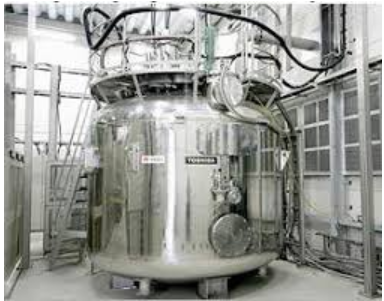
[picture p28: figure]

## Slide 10

7. Diseño de producto: Impresión 3d

Convertidor | Alternativas: | Opción elegida:
RECTIFICADOR (CA/CC) | Fuente de tensión (VSC) Fuente de corriente (VSC) | Menor rizado e inyección de armónicos. Menores perdidas de conmutación Menor número de componentes.
CHOPPER (CC/CC) | IGBT’s SCR’s | Pérdidas en conducción y conmutación menores.

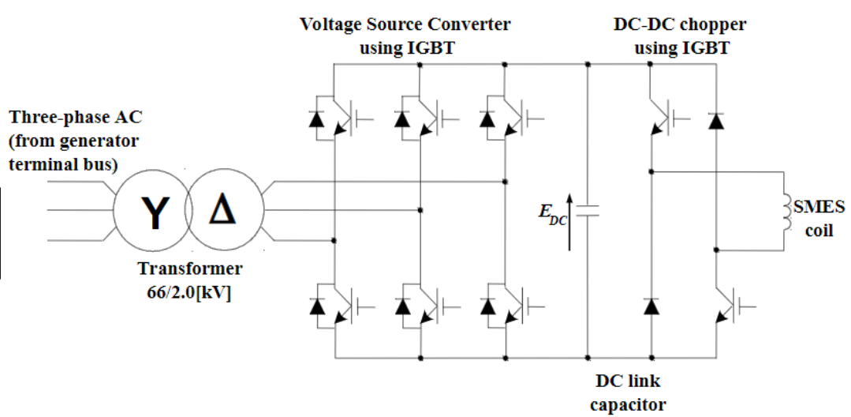
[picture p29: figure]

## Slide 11

8. Diseño de Firmware:
Algoritmos de posicionamiento.

Convertidor | Alternativas: | Motivo de elección:
RECTIFICADOR (CA/CC) | Control Vectorial Control P&Q Control sobre fase y magnitud | Control independiente de potencia activa y reactiva. Velocidad de respuesta ante cambios alta. Eficiencia ante cargas dinámicas.
CHOPPER (CC/CC) | Control Fuzzy Logic Control PWM | Dificultad de implementación media Precisión en la respuesta elevada Control adaptativo

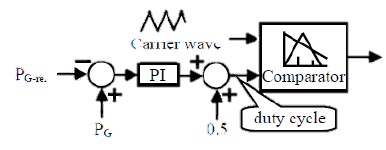
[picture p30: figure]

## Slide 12

9. Acondicionamiento y ubicación de equipos

- Medida de Tensiones y corrientes de la Microgrid.
- Medida tensión y corriente por la bobina SMES

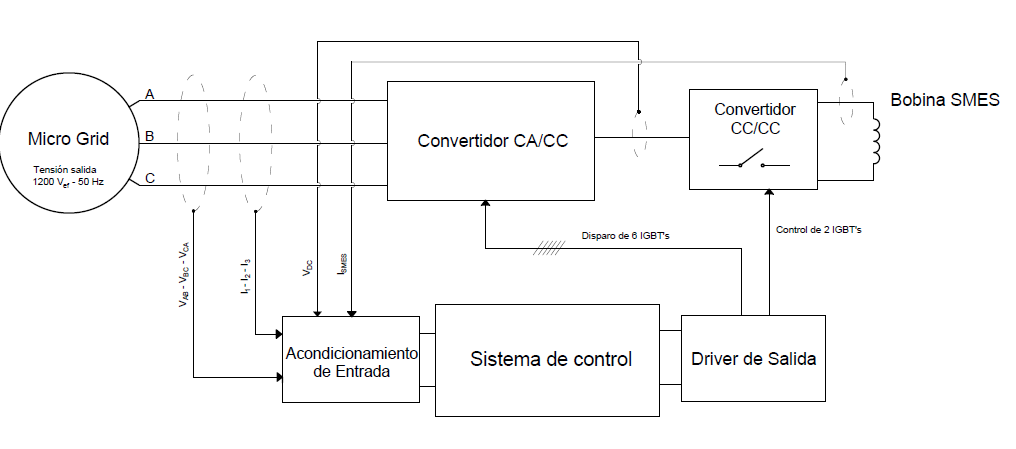
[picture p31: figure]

- Disparo de 6 IGBT’s del rectificador.
- Disparo de 2 IGBT’s del convertidor CC/CC

ENTRADAS

- IN:
V e I microgrid
V salida rectificador
I bobina

- OUT:
Disparo de 8 IGBT’s

SALIDAS

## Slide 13

9. Software de visualización

Drivers de salida:
- Circuito que integra aislamiento galvánico. IGBT’s distintas masas.
- Selección de componentes.
- Se ha llevado a cabo el dimensionamiento de radiadores y protecciones.
- No se han empleado filtros en la etapa de instrumentación puesto que perderíamos el carácter transitorio de las perturbaciones.
- Diseño de fuentes de alimentación.

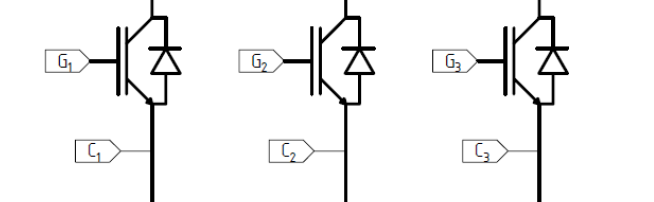
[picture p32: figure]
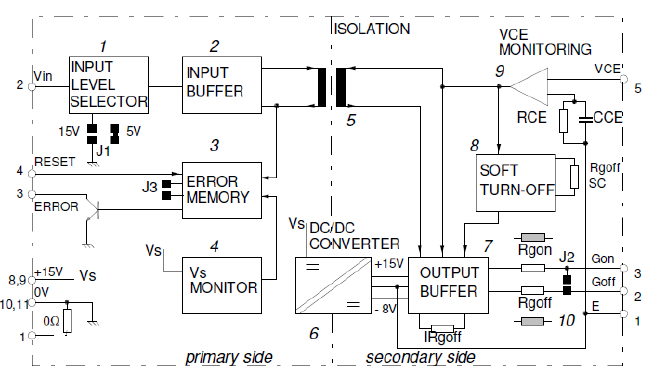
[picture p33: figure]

Masa de Control

Masa de Potencia

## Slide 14

10. Simulaciones con PSIM

- Comportamiento ante subida y bajada de tensión:

Modos de funcionamiento:
- Carga de la bobina
- Stand-by
- Descarga de la bobina

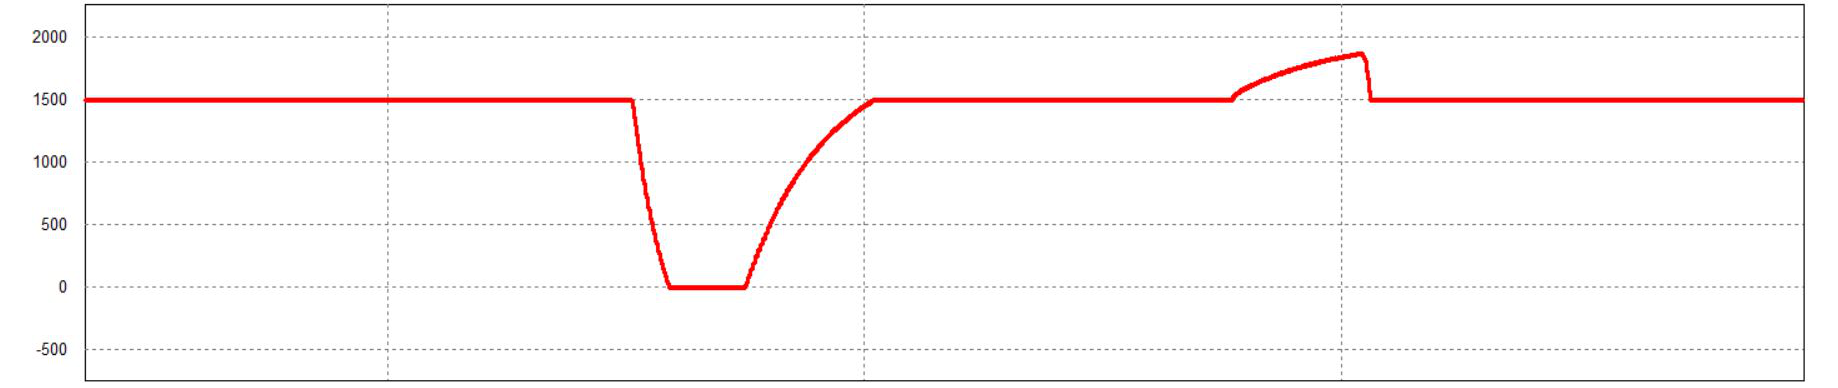
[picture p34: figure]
Imagen que contiene texto, mapa Descripción generada con confianza muy alta

- CORRIENTE EN LA BOBINA:

Descarga de corriente de la bobina en la microgrid

Carga de corriente de la la microgrid en la bobina

- TENSIÓN MICROGRID:

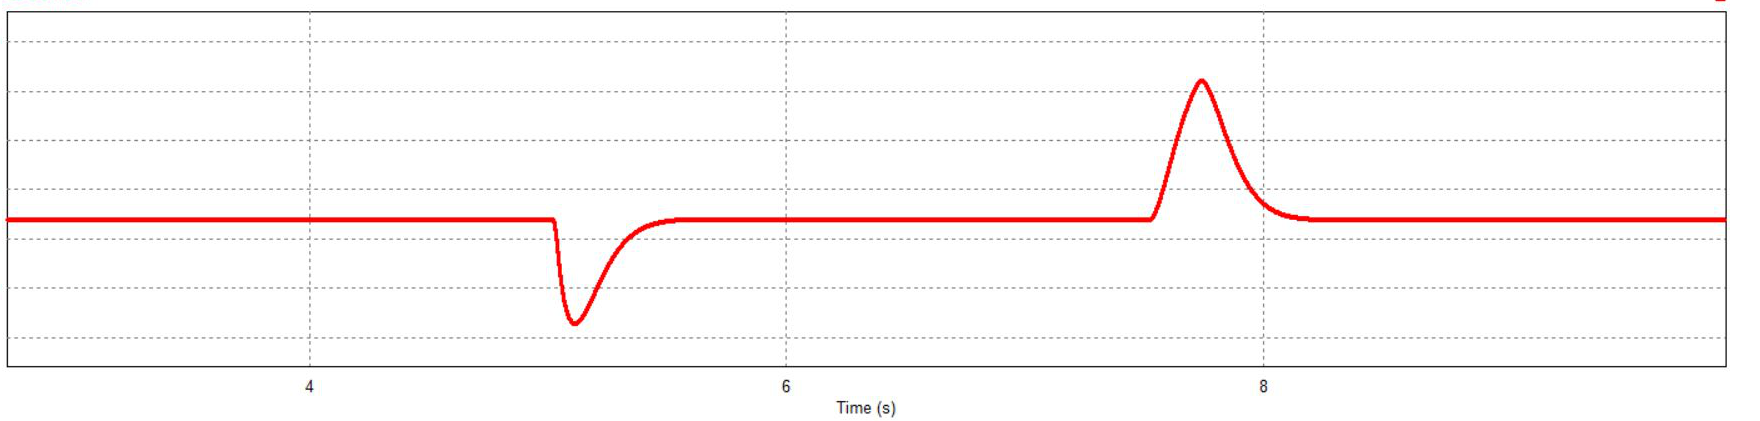
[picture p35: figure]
Imagen que contiene texto, mapa Descripción generada con confianza muy alta

Ante caída de tensión

Ante subida de tensión

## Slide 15

10. Simulaciones con PSIM

- En el modo stand-by la bobina se desconecta de la Microgrid:

- CORRIENTES POR EL SISTEMA SMES:

Imagen que contiene captura de pantalla Descripción generada con confianza alta

Desconexión de la microgrid

- CORRIENTE EN LA BOBINA:

- El simulador PSIM no permite llevar a cabo modelos de superconductividad:

La corriente debiera permanecer constante

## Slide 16

10. Simulaciones con PSIM

- Vemos como es el efecto ante pequeñas perturbaciones

- TENSIÓN DE MICROGRID SIN SISTEMA SMES:


- TENSIÓN DE MICROGRID CON SISTEMA SMES:


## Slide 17

7. Estudio de Compatibilidad Electromagnética

7.1 Estudio de los tipos de perturbación por medio de transmisión:

- Conducidas
  - Debidas a conexión de un elemento no lineal a la red.
- Radiadas
  - Debidas a campos magnéticos de la bobina.
  - Conmutación de alta frecuencia, 5 kHz, poca influencia.
  - Bobina se encuentra apantallada

Se ha llevado a cabo un desarrollo de Fourier para comprobar el la inyección de armónicos en la red.


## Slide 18

7. Estudio de Compatibilidad Electromagnética

Se ha llevado a cabo un desarrollo de Fourier para comprobar el la inyección de armónicos en la red.

- FFT de la CORRIENTE INYECTADA EN LA RED:

Imagen que contiene mapa, texto Descripción generada con confianza muy alta

Corriente Fundamental (50Hz)

1º Armónico (150Hz)

2º Armónico (300Hz)

Cumple con el Informe Técnico de la Comisión Electrotécnica Internacional 6100.

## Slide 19

10. Viabilidad Económica

10.1 Análisis DAFO

- Coste elevado
- Dificultades técnicas
- Volumen y peso del dispositivo.

Análisis Interno

- Apuesta por las energías renovables.
- Lugar de consumo próximo al de generación.
- Carácter Modular: Facilidad de reparaciones o sustituciones.


- Rechazo inicial de la tecnología
- Costes de refrigeración elevados
- Creciente aumento de la competencia.

- Apuesta por la superconductividad.
- Gran rendimiento
- Infinidad de cargas y descargas
- Tecnología innovadora (I+D).

Análisis Externo

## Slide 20

10. Viabilidad Económica

10.2 Presupuesto y pliego de condiciones

- Llevado a cabo un anejo de justificación de precios.
- Se han conformado presupuesto ejecución material y por contrata.
- Finalmente, en el documento 4: Presupuesto se recoge el presupuesto total que asciende a:

PRESUPUESTO TOTAL
Presupuesto de ejecución por contrata | 443.093,10 €
Impuesto sobre el valor añadido – I.V.A. (21%) | 93.049,55 €
Total presupuesto total | 536.142,65 €

- Por último se ha recogido toda la normativa que afecta al proyecto y se ha expuesto y clasificado en campos dentro del documento 3: Pliego de condiciones

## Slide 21

10. Viabilidad Económica

10.3 Flujos de Caja VAN y TIR

- Análisis de las necesidades
- Vida Tecnológica
- Estudio de rentabilidad


Cálculo del valor actual neto:
Cálculo de la tasa interna de rentabilidad:
Plazo de retorno de la inversión:

TIR=9,02 %

VAN=163.050,18 €

PR =4 meses

## Gracias por su atención

Rubén Arce Domingo
Master en automatización y robótica

Febrero 2021

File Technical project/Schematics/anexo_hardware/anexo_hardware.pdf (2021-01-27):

ANEXO 1: DISENO DE HARDWARE ˜

## SISTEMAS DE POSICIONAMIENTO DE OBJETOS MEDIANTE LA TECNOLOGÍA

## BLUETOOTH LOW ENERGY, MODO BEACON

27 de enero de 2021

Rubén Arce Domingo
Máster en automatización y robótica industrial
akimbo170@gmail.com

## Índice

1 Introducción | 5
2 Emisor Beacon | 5
2.1 Aspectos a considerar | | 5
2.2 Circuito eléctrico | | 5
2.2.1 | Microcontrolador | | 5
2.2.2 | Alimentación | | 5
2.3 PCB de control | | 6
2.4 Imágenes reales | | 7
3 Receptor Beacon o gateway | 7
3.1 Aspectos a considerar | | 7
3.2 Circuito eléctrico | | 7
3.2.1 | Microcontrolador | | 7
3.2.2 | Alimentación | | 8
3.3 PCB de control | | 8
3.4 Imágenes reales | | 9
3.5 Conclusiones | 10

## Índice de figuras

1 | Renderizado de PCB del Beacon | | 6
2 | PCB del Beacon obtenida con Kicad | | 6
3 | PCB real fabricada y soldada | | 7
4 | Fuentes de alimentación de la PCB master | | 8
5 | Renderizado de PCB del master o gateway | | 9
6 | Renderizado de PCB del master o gateway | | 9
7 | Imágenes reales de la PCB gateway | 10

3

2 EMISOR BEACON

## 1. Introducción

Los diseños eléctricos y el trazado de las pistas del circuito se han llevado a cabo con Kicad en su versión 5.1.6. Se ha empleado este programa debido a que, en primer lugar es de software libre y completamente gratuito y, en segundo lugar, debido a que puede funcionar en Linux. Además de que es capaz de llevar a cabo cualquier diseño profesional sin problema de licencias o versiones incompatibles.
Por otro lado, todas las PCBs se han fabricado en dos capas con un espesor estándar de 1,6mm y con acabado superficial HASH plomo estaño en los primeros prototipos. En la versión final se empleará el acabado ENIG, o de oro electrolítico, para mejorar las especificaciones y durabilidad de la misma.
Por último mencionar que se han empleado tanto componentes SMD como through hole y se ha priorizado el precio en la selección de los mismos.

## 2. Emisor Beacon

### 2.1. Aspectos a considerar

Las premisas para seleccionar el mejor microcontrolador han sido las siguientes:

1. Bajo consumo.
2. Tamaño reducido.
3. Bluetooth y posibilidad de wifi en caso de eliminar el dispositivo emisor.
4. Precio muy competitivo.

### 2.2. Circuito eléctrico

### 2.2.1. Microcontrolador

En el caso del microcontrolador, se ha optado por un ESP32 de la empresa Espressif (https://www.espressif.com/) debido en gran medida a que dispone de wifi y bluetooth, así como de unas excelentes herramientas de desarrollo de software.

### 2.2.2. Alimentación

Para llevar a cabo la alimentación del microcontrolador y, teniendo en cuenta que se han de garantizar los 3,3V en la entrada del micro, se ha optado por una batería de Ion-Litio de 1400mAh que además tiene un tamaño reducido. El rango de tensión de la tarjeta va de 12V a 3,6V en el caso de que se opte por otro método de alimentación.

BLE Tracking - 2021 | 5 | Rubén Arce

2.3 PCB de control | 2 EMISOR BEACON

### 2.3. PCB de control

Una vez tenidas en cuenta estas especificaciones, en el esquema eléctrico se ha llevado a cabo el ruteo de la tarjeta. Vemos que se ha elaborado el trazado de pistas con planos de masa para prevenir interferencias electromagnéticas y conseguir que no afecte demasiado a la electrónica. En las diguras 1 y 2 podemos ver imágenes de los renderizados y circuitos eléctricos.


Figura 1: Renderizado de PCB del Beacon.


Figura 2: PCB del Beacon obtenida con Kicad.

BLE Tracking - 2021 | 6 | Rubén Arce

3 RECEPTOR BEACON O GATEWAY | 2.4 Imágenes reales

Se ha dejado la zona de la antena despejada para mejor la ganancia de la misma y en consecuencia el alcance, en el caso del Beacon se usarán las antenas que integra el microcontrolador.

### 2.4. Imágenes reales

Tras llevar a cabo la fabricación de las tarjetas prototipo podemos ver los resultados en la figura 3.


Figura 3: PCB real fabricada y soldada

## 3. Receptor Beacon o gateway

### 3.1. Aspectos a considerar

1. Velocidad de procesamiento: El número máximo de equipos a localizar puede ser superior a 500, es por ello por lo que quedan descartados los microcontrodores de 8 bits y cristales de menos de 16MHz.
2. Wifi/bluetooth: Ha de escuchar a los Beacons y subir los datos a internet, es por ello por lo que se hace indispesable que cuente con hardware que permita las dos acciones.

### 3.2. Circuito eléctrico

### 3.2.1. Microcontrolador

Teniendo en cuenta estas condiciones previas y contando con procesadores ESP32 del diseño anterior, se ha optado por compartir el procesador para ambos equipos. Con esto

BLE Tracking - 2021 | 7 | Rubén Arce

3.3 PCB de control | 3 RECEPTOR BEACON O GATEWAY

conseguimos que el software y librerías sean compatibles al 100 % y se ahorre tiempo de desarrollo.

### 3.2.2. Alimentación

En este caso puesto que la tarjeta se encontrará estática en un lugar cercano a un enchufe se brindan las siguientes opciones de alimentación:

1. 220 VAC.
2. 12 VDC.
3. 5 VDC, en el caso de que se disponga de un ordenador cerca se podría conectar por USB.

En la figura 4 podemos ver el circuito responsable, mediante un jumper. Se facilita el cambio de alimentación para las distintas necesidades de los clientes.


Figura 4: Fuentes de alimentación de la PCB master.

### 3.3. PCB de control

Se ha optado por llevar a cabo el trazado de pistas de alimentación por la cara top y las de señal por la bottom, vemos que hay dos conectores en los extremos de la tarjeta, uno con una UART para comunicarse con otros sistemas de la planta y otro conector para sensores i2c, pensado para la lectura de humedad y temperatura, así como para el envío de estos datos a la web de control. En la figura 5 se aprecia con mayor detalle la PCB del master en un renderizado obtenido con Kicad.
En el apartado de planos se puede ver con mayor detalle el esquema eléctrico y dimensiones de la tarjeta.
BLE Tracking - 2021 | 8 | Rubén Arce

3 RECEPTOR BEACON O GATEWAY | 3.4 Imágenes reales


Figura 5: Renderizado de PCB del master o gateway.


Figura 6: Renderizado de PCB del master o gateway.

### 3.4. Imágenes reales

Por último y tras fabricar las tarjetas e imprimir las cajas que lo contienen se obtiene el resultado de las figuras 6 y 7.

BLE Tracking - 2021 | 9 | Rubén Arce

3.5 Conclusiones | 3 RECEPTOR BEACON O GATEWAY


Figura 7: Imágenes reales de la PCB gateway.

### 3.5. Conclusiones

Una vez recibidas las PCBs se fueron ensamblando a mano sin mayor incidente que la confusión en la posición de un led que, por supuesto, tras cargar el firmware en la tarjeta, no se iluminó. Solucionado el incidente, la versión 1 de las tarjetas fue, por suerte, la definitiva.

BLE Tracking - 2021 | 10 | Rubén Arce

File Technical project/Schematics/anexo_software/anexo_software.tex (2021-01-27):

\documentclass[paper=a4, fontsize=11pt,twoside]{scrartcl}	
\usepackage[a4paper,pdftex]{geometry}	
\setlength{\oddsidemargin}{5mm}			
\setlength{\evensidemargin}{5mm}
\usepackage[protrusion=true,expansion=true]{microtype}	
\usepackage{amsmath,amsfonts,amsthm,amssymb}
\usepackage{graphicx}
\usepackage[spanish]{babel}
\usepackage[hidelinks]{hyperref}
\usepackage{hyperref}
\usepackage[hidelinks]{hyperref}
\usepackage{graphicx}
\usepackage{xcolor}
\usepackage{fancyhdr}
\usepackage{float}

\newcommand{\HRule}[1]{\rule{\linewidth}{#1}} 	% Horizontal rule
\makeatletter							% Title
\def\printtitle{%						
    {\centering \@title\par}}
\makeatother									
\makeatletter							% Author
\def\printauthor{%					
    {\centering \large \@author}}				
\makeatother							
\title{	\normalsize \textsc{ANEXO 3: DISEÑO DE SOFTWARE} 	% Subtitle
		 	\\[2.0cm]								% 2cm spacing
			\HRule{0.5pt} \\						% Upper rule
			\LARGE \textbf{\uppercase{Sistemas de posicionamiento de objetos mediante la tecnología Bluetooth Low Energy, modo Beacon}}	% Title
			\HRule{2pt} \\ [0.5cm]		% Lower rule + 0.5cm spacing
			\normalsize \today			% Todays date
		}
\author{
		Rubén Arce Domingo\\	
		Máster en automatización y robótica\\	
		industrial\\
		akimbo170@gmail.com\\
        % \texttt{akimbo170@gmail.com} \\
}

\begin{document}
\thispagestyle{empty}		% Remove page numbering on this page
\printtitle					% Print the title data as defined above
  	\vfill
\printauthor				% Print the author data as defined above
\newpage
\cleardoublepage
\tableofcontents
\listoffigures
\cleardoublepage
\pagestyle{fancy}
\fancyfoot[R]{Rubén Arce}
\fancyfoot[L]{BLE Tracking - 2021}
\section{Introducción}
    Este proyecto engloba programación de tres sistemas que emplean protocolos y tecnologías muy diferenciadas para llevar a cabo 
    la transmisión de información, empleando el lenguaje de programación C para el firmware de los 
    microcontroladores y Python para ralizar los cálculos de distancia y visualización de los Beacons.
    \paragraph{}
    Se han ejecutado pruebas en interiores y exteriores, en una casa, en un supermercado y en un lugar con un número elevado 
    de dispositivos BLE, mostrando a continuando el procedimiento y los resultados.
\section{Firmware}
    \subsection{Emisor BLE o Beacon}
        La ventaja de los Beacons es que se ha llevado a cabo el paradigma de plug and play, es decir, tan solo hay que conectar la batería y comienza 
        a funcionar sin problemas. La única posibilidad de configuración podría ser el tiempo de envío de datos.
        
        Teniendo en cuenta que estamos en fases de pruebas no se ha adoptado un perfil demasiado conservador en lo que a batería se refiere. 
        Sin embargo en la versión real para cliente se le dará la posibilidad de configurar a su gusto la frecuencia de envío de datos con las consecuencias 
        que esto conlleva en la autonomía.
    \subsection{Receptor gateway o master}
        \subsubsection{Configuración inicial}
            El equipo que escucha a los Beacons ha de hacer un barrido cada X tiempo, obtener el Rssi y por último enviar a través de MQTT los datos 
            para que el sistema de visualización sea capaz de posicionarlos dentro de un mapa.
            Para que todo esto funcione es necesario que alguien configure su Wifi al que han de conectarse para poder transmitir los datos.

            Esta configuración inicial ha de ser sencilla y, sobretodo, ha de poder cambiarse en el caso de que la contraseña se modifique o de que se desplacen 
            los equipos a otro lugar.
            
            Para ello se ha programado lo siguiente:
            \begin{enumerate}
                \item Según sale de fábrica el master intenta conectarse, con números aleatorios, al Wifi que tenga guardado en la memoria.
                \item Cuando fracase en el intento, generará un punto de acceso, es decir, se crea un Wifi al que el usuario ha de conectarse.
                \item Una vez conectado a este Wifi sin internet ha de meterse en la página web alojada en el 192.168.4.1 donde introducirá los credenciales 
                del Wifi real al que ha de conectarse.
                \item Tras recibir los datos proporcionados por el cliente, el equipo se conectará a internet y estará listo para usarse y escuchar Beacons.
                \item En la memoria flash se guardan los datos para que cada vez que se apage no sea necesario repetir el proceso.
            \end{enumerate}
            En todo momento si se quisiera volver a condiciones de fábrica se puede pulsar el botón a la vez que se enciende el dispositivo y se reseteará 
            la memoria previamente configurada y volverá a generarse el punto de acceso Wifi para repetir el proceso.
            
            En la figura 1 se puede ver cómo es el interfaz web que se ha llevado a cabo para la configuración del Wifi.
            \begin{center}
                \begin{figure}[!h]
                    \centering
                    
                    \caption{Captura de página web generada por el dispositivo}
                    \label{fig:mesh12}
                \end{figure}
            \end{center}
        \subsubsection{Funcionamiento}
            Una vez llevada a cabo esta configuración inicial y habiendo conectado el master al terminal a través del puerto serie,
            podemos ver cómo se lleva a cabo el barrido de los Beacons y el procesamiento de los mismos.

            El envío de información a través de MQTT se lleva a cabo en el acto consiguiendo una frecuencia elevada de datos que alimentan a nuestra herramienta 
            de visualización de una forma dinámica. En la figura 2 se puede ver como en el primer barrido se encuentran 8 Beacons y en el segundo solo 7.
            \begin{center}
                \begin{figure}[]
                    \centering
                    
                    
                    \caption{Escaneo y procesamiento de dispositivos Beacons}
                    \label{fig:mesh13}
                \end{figure}
            \end{center}
\section{Herramientas de visualización}
    \subsection{Tecnologías}
        Para generar las pantallas y animaciones se ha empleado Python con su librería "Pygame". En lo que respecta a los cálculos 
        y gráficas se ha empleado Matplotlib y "NumPy" para hacer operaciones de una forma rápida.  
    \subsection{Procedimiento}
        Se han llevado a cabo cinco simulaciones, en todas ellas la metodología ha sido la siguiente:
        \begin{enumerate}
            \item Escucha de los datos.
            \item Parseo de los mismos, así como almacenamiento en estructuras de datos que permitan luego fácil utilización.
            \item Filtraje, cálculos de posicionamiento y ajustes.
            \item Visualización y escalado de los resultados.
        \end{enumerate}
    \subsection{Simulaciones}
        \subsubsection{Prueba de concepto}
            Para comprobar si la tecnología era capaz de llevar a cabo el posicionamiento de un equipo en un mapa, se ha establecido un sencillo
            escenario en el que había tres equipos que escuchaban y cuatro Beacons. En la siguiente imagen se puede apreciar el sencillo escenario.

            La figura representa lo coloridos Beacons próximos entre sí, mostrando como sí que es posible situarlos con relativa precisión.
            Asimismo, se puede observar que los masters tienen los nombres de A1, A2 y A3, respectivamente.
            \begin{center}
                \begin{figure}[]
                    \centering
                    
                    \caption{Prueba piloto, carretera}
                    \label{fig:mesh14}
                \end{figure}
            \end{center}
        \subsubsection{Estabilidad del sistema}
            Tras esta primera prueba se optó por ver hasta que punto la tecnología es precisa, para lo cual se trazaron gráficas comparativas
            con los datos obtenidos a través de los equipos. En primer lugar, se dejaron durante un par de horas encendidos los equipos para ver las 
            fluctuaciones.

            Como podemos ver en la figura 4 las diferencias entre equipos estáticos son acusadas, es por ello por lo que queda demostrada la necesidad de
            desarrollar un filtro que anule este ruido radioeléctrico.
            \begin{center}
                \begin{figure}[]
                    \centering
                    
                    \caption{Toma de datos durante dos horas}
                    \label{fig:mesh15}
                \end{figure}
            \end{center}
        \subsubsection{Posicionamiento real}
            El paso siguiente fue comprobar si tras filtrar las señales era realmente capaz de discernir si un Beacon se encontraba en una habitación
            o en otra tan solo atendiendo a su Rssi. Para ello se ha llevado a cabo una simulación que permite dibujar las dimensiones y color de las 
            habitaciones así como la posición de los masters que escuchan a estos Beacons. En la figura 5 se puede ver una captura del archivo de configuración 
            con el que se pretende que cualquiera pueda dibujarse su propia casa.
            \begin{center}
                \begin{figure}[]
                    \centering
                    
                    \caption{Archivo de configuración de diseño de casa}
                    \label{fig:mesh16}
                \end{figure}
            \end{center}
            Una vez creada nuestra casa ya solo queda colocar realmente los equipos en lugares elevados y poco accesibles y ejecutar el script.
            Los equipos estuvieron durante una semana encendidos, escuchando Beacons y los resultados fueros los esperados. En la figura 6 se puede 
            visualizar el diseño de la casa en la que se llevó a cabo la prueba.
            \paragraph{}
            El caso más curioso de todos es que se dejaron Beacons estáticos encima de armarios y la posición no móvil de los mismos 
            se mantuvo en la simulación en todo momento. En la imagen 7 se muestra como fueron percibidos por los masters.
            \paragraph{}
            Al movernos dentro de la casa los masters de las habitaciones contiguas nos percibían con menor Rssi, es por
            ello por lo que no nos visualizaba dentro de esa estancia. En la figura 8 se puede ver como las cuatro personas se 
            encontraban en el salón de la casa en ese momento.
            \begin{center}
                \begin{figure}[]
                    \centering
                    
                    \caption{Ejemplo de tres personas dentro de una misma habitación}
                    \label{fig:mesh17}
                \end{figure}
            \end{center}          
            \begin{center}
                \begin{figure}[]
                    \centering
                    
                    \caption{Beacons estáticos durante la simulación}
                    \label{fig:mesh19}
                \end{figure}
            \end{center} 
            \begin{center}
                \begin{figure}[]
                    \centering
                    
                    \caption{Beacons en movimiento}
                    \label{fig:mesh18}
                \end{figure}
            \end{center}   
        \subsubsection{Prueba en supermercado}
        Una vez testada la tecnología se llevó a cabo una prueba real en un supermercado. Para ejecutal el ejemplo
        se instalaron únicamente dos masters y seis Beacons en carros en movimiento.
        
        Como suele ocurrir, la prueba real no se asemejaba tanto a las pruebas anteriores y podemos comprobar como 
        el algoritmo se complica más en ausencia de numerosos masters escuchando Beacons. En este caso como solo se disponían
        de dos, los cálculos no siempre eran tan precisos y el filtro implementado en el caso de un desplazamiento rápido de un 
        equipo de punta a punta del supermercado no era el más óptimo.
        
        Podemos ver como los puntos amarillos son los carros de la compra percibidos por ambos Beacons y los rojos son aquellos
        que solo son escuchados por un master, de tal modo que el punto en el que se encuentran es menos preciso a menos número de 
        masters escuchando. Igualmente se puede llegar a ver en que lugar hay más concentración de gente.
        \begin{center}
            \begin{figure}[!ht]
                \centering
                
                \caption{Beacons en movimiento dentro de supermercado captura 1}
                
                \caption{Beacons en movimiento dentro de supermercado captura 2}
                
                \caption{Beacons en supermercado percibidos solo por un master}
                \label{fig:mesh10}
            \end{figure}
        \end{center}   

    \subsection{Conclusiones}
        Se puede concluir que la tecnología de posicionamiento de objetos o personas en interiores es suficientemente precisa como para 
        situarlos de una forma acertada dentro de una habitación.
        
        Se han de tener en cuenta las limitaciones físicas que esto conlleva puesto
        que los equipos presentan fluctuaciones en su percepción de rssi, así como de la influencia de medio en el que se coloquen.

        Aún con todo esto estamos ante un sistema perfectamente válido para la aplicación que tenemos entre manos, siempre y cuando no se requiera de una
        exactitud o precisión elevada. 

        El mayor punto a favor de este equipo es su relación calidad precio, por un pequeño y bajo coste se puede colocar un dispositivos emisor y posicionarlo 
        sin miedo a que se pierda puesto que un sustituto sería asequible.

\end{document}

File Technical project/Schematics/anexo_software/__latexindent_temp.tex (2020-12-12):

\documentclass[a4paper ,12pt, onecolumn]{article}
\usepackage[utf8]{inputenc}
\usepackage[spanish]{babel}
\usepackage[hidelinks]{hyperref}
\usepackage{graphicx}
\usepackage{xcolor}
\usepackage{fancyhdr}

\begin{document}
\pagestyle{fancy}
\fancyfoot[R]{Rubén Arce}
\fancyfoot[L]{BLE Tracking - 2020}
\title{Anexo de software - TFM Beacons Tracking}
\author{Rubén Arce}
\date{\today}
\maketitle
\cleardoublepage
\tableofcontents
\listoffigures
\cleardoublepage
\section{Introducción}
    Este proyecto engloba programación de 3 sistemas muy diferentes para que transmitan información entre ellos 
    sin problemas de comunicación. Para lo cual se ha empleado el lenguaje de programación C para el firmware de los 
    microcontroladores y Python para poder llevar a cabo los cálculos de distancia y visualización de los beacons.
    \paragraph{}
    Se han llevado a cabo pruebas en interiores y exteriores, en una casa, en un supermercado y en un lugar con un número elevado de dispositivos BLE y
    a continuación se muetra el procedimiento y resultados.
\section{Firmware}
    \subsection{Emisor BLE o beacon}
    \subsection{Receptor gateway o master}
        \subsection {Funcionamiento}
       
\section{Herramientas de visualización}
    \subsection{Tecnologías}
        Para generar las pantallas y animaciones he empleado Python con su librería "Pygame", en lo que respecta a los cálculos 
        y gráficas se ha empleado Matplotlib y para hacer operaciones de una forma rápida "NumPy".    
    \subsection{Procedimiento}
        Se han llevado a cabo TODO simulaciones, en todas ellas la metodología ha sido la siguiente:
        \begin{enumerate}
            \item Escucha de los datos
            \item Parseo de los mismos así como almacenamiento en estructuras de datos que permitan luego fácil utilización.
            \item Filtraje, cálculos de posicionamiento y ajustes.
            \item Visualización y escalado de los resultados.
        \end{enumerate}
    \subsection{Simulaciones}
        \subsubsection{Prueba de concepto}
            Para comprobar si la tecnología era capaz de llevar a cabo el posicionamiento de un equipo en un mapa de estableció un sencillo
            escenario en el que había tres equipos que escuchaban y 4 beacons. En la siguiente imagen se puede apreciar el sencillo escenario.

            En la imagen podemos ver los coloridos beacons próximos entre si y como si que es posible situarlos con relativa preción. En la imagen 
            vemos que los masters tienen los normbres A1, A2 y A3 respectivamente.
            \begin{center}
                \begin{figure}[]
                    \centering
                    
                    \caption{Prueba piloto, carretera}
                    \label{fig:mesh11}
                \end{figure}
            \end{center}
        \subsubsection{Estabilidad del sistema}
            Tras esta primera prueba se optó por ver hasta que punto la tecnología es precisa, para lo cual se trazaron gráficas comparativas
            con los datos obtenidos a través de los equipos. En primer lugar se dejó durante un par de horas encendidos los equipos para ver las 
            fluctuaciones.
            \begin{center}
                \begin{figure}[]
                    \centering
                    
                    \caption{Toma de datos durante 2 horas}
                    \label{fig:mesh11}
                \end{figure}
            \end{center}
            Como podemos ver en la imagen las diferencias entre equipos estáticos son acusadas, es por ello por lo que queda demostrada la necesidad de
            desarrollar un filtro que anule este ruido radioeléctrico.
        \subsubsection{Posicionamiento real}
            El paso siguiente fue comprobar si tras filtrar las señales era realmente capaz de discernir si un Beacon se encontraba en una habitación
            o en otra tan solo atendiendo a su rssi, para lo cual se ha llevado a cabo una simulación que permite dibujar las dimensiones de las 
            habitaciones, la posición de los beacons e incluso el color de las mismas. 
            \begin{center}
                \begin{figure}[]
                    \centering
                    
                    \caption{Archivo de configuración de diseño de casa}
                    \label{fig:mesh11}
                \end{figure}
            \end{center}
            Una vez creada nuestra casa ya solo queda colocar realmente los equipos en lugares elevados y poco acesibles y ejecutar el script.
            Los equipos estuvieron durante una semana encendidos escuchando beacons y los resultados fueros los esperados.
            \begin{center}
                \begin{figure}[]
                    \centering
                    
                    \caption{Ejemplo de 3 personas dentro de una misma habitación}
                    \label{fig:mesh11}
                \end{figure}
            \end{center}          
            El caso más curioso de todos es que se dejaron beacons estáticos encima de armarios y la posición no móvil de los mismos 
            se mantuvo en la simulación en todo momento.
            \begin{center}
                \begin{figure}[]
                    \centering
                    
                    \caption{Beacons estáticos durante la simulación}
                    \label{fig:mesh11}
                \end{figure}
            \end{center} 
            Al movernos dentro de la casa los masters de las habitaciones contiguas nos percibían con menor rssi, es por
            ello por lo que no nos visualizaba dentro de esa estancia.
            \begin{center}
                \begin{figure}[]
                    \centering
                    
                    \caption{Beacons en movimiento}
                    \label{fig:mesh11}
                \end{figure}
            \end{center}   
        \subsubsection{Prueba en supermercado}
            Una vez testada la tecnología se llevó a cabo una prueba real en un supermercado, para llevar a cabo la prueba
            se instalaron únicamente 2 masters y 6 beacons en carros en movimiento.
            Como suele pasar la prueba real no se parece tanto a las pruebas anteriores y podemos comprobar como 
            el algoritmo se complica más en asuncia de numerosos masters escuchando beacons, en este caso como solo se disponían
            de 2 los cálculos no siempre eran tan precisos y el filtro implementado en el caso de un desplazamiento rápido de un 
            equipo de punta a punta del supermercado no era el más óptimo.
            \begin{center}
                \begin{figure}[]
                    \centering
                    
                    \caption{Beacons en movimiento dentro de supermercado captura 1}
                    
                    \caption{Beacons en movimiento dentro de supermercado captura 2}
                    
                    \caption{Beacons en supermercado percibidos solo por un master}
                    \label{fig:mesh11}
                \end{figure}
            \end{center}   
            
            Podemos ver como los puntos amarillos son los carros de la compra percibidos por ambos beacons y los rojos son aquellos
            que solo son escuchados por un master, de tal modo que le punto en el que se encuentran es menos precio.

\end{document}

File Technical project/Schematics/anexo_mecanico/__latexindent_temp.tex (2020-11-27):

\documentclass[a4paper ,12pt, onecolumn]{article}
\usepackage[utf8]{inputenc}
\usepackage[spanish]{babel}
\usepackage[hidelinks]{hyperref}
\usepackage{graphicx}
\begin{document}
\title{Anexo diseño mecánico}

\author{Rubén Arce}
\date{\today}
\maketitle
\cleardoublepage
\tableofcontents
\listoffigures
\cleardoublepage

\section{Introducción}
Para llevar a cabo el diseño mecánico de estas piezas concretas se ha optado por emplear Freecad, un
programa de software libre que permite hacer modelos sencillos de forma gratuita.
Se ha empleado la versión 12 del mismo corriendo en una raspberry pi 4 de 4Gb de RAM, este es el único
programa que corre en linux de diseño 3D y además consume pocos recursos.
\paragraph{}
Los primeros prototipos se han llevado a cabo con una impresora 3D Anet A8 con el firmware de Marling
2.0 y como material PLA de 1,75mm y distancia entre capa de 0,2 mm.
\section{Emisor beacon}
    \subsection{Aspectos a considerar en el diseño}
        \begin{enumerate}
            \item Estéticamente atractivo
            \item Pequeñas dimensiones
            \item Cómodo para llevar colgado del cuello
            \item Facilidad para desmontar y recargar las baterías o pilas
            \item Limitaciones en el tamaño de máximo 220x220x250 mm debido al volumen de impresión.
        \end{enumerate}
    \subsection{Planos y dimensiones}
        Una vez llevado a cabo el siseño se han obtenido los planos y se ha llevado a cabo la impresión 3d de los mismos.
        
    \subsection{Imágenes renderizado}
    \begin{center}
        \begin{center}
            \begin{figure}[h]
                \centering
                
                \caption{Prototipo impreso con Anet A8 master v1}
                \label{fig:mesh1}
            \end{figure}
        \end{center}
        \begin{center}
            \begin{figure}[h]
                \centering
                
                \caption{Prototipo impreso con Anet A8 master v1}
                \label{fig:mesh1}
            \end{figure}
        \end{center}
    \end{center}
    \subsection{Imágenes reales}

        \begin{center}
            \begin{figure}[h]
                \centering
                
                \caption{Prototipo impreso con Anet A8 master v1}
                \label{fig:mesh1}
            \end{figure}
        \end{center}
        \begin{center}
            \begin{figure}[h]
                \centering
                
                \caption{Prototipo impreso con Anet A8 master v1}
                \label{fig:mesh1}
            \end{figure}
        \end{center}

\section{Receptor beacon o gateway}
    \subsection{Aspectos a considerar en el diseño}
        \begin{enumerate}
            \item Estéticamente atractivo, puesto que va a estar físicamente a la vista.
            \item Pequeñas dimensiones y discreto.
            \item Limitaciones en el tamaño de máximo 220x220x250 mm debido al volumen de impresión.
            \item Estructura sólida que garantize un buen agarre de la PCB en vertical.
        \end{enumerate}
    \subsection{Planos y dimensiones}
        Partiendo de las dimensiones de la tarjeta que se muestra a continuación:
        \begin{center}
            \begin{figure}[h]
                \centering
                
                \caption{Plano caja del emisor}
                \label{fig:mesh1}
            \end{figure}
        \end{center}

        Se ha prototipado el siguiente diseño:
    \subsection{Imágenes renderizado}

        Los renderizados 3D previos a la impresión:
        \begin{center}
            \begin{figure}[h]
                \centering
                
                \caption{Renderizado caja del emisor}
                \label{fig:mesh1}
            \end{figure}
        \end{center}
        \begin{center}
            \begin{figure}[h]
                \centering
                
                \caption{Plano caja del emisor}
                \label{fig:mesh1}
            \end{figure}
        \end{center}

    \subsection{Imágenes reales}
        Una vez impresas las piezas y sin necesidad de lijar o ajustar algún apriete o tolerancia:
    
        \begin{center}
            \begin{figure}[h]
                \centering
                
                \caption{Prototipo impreso con Anet A8 master v1}
                \label{fig:mesh1}
            \end{figure}
        \end{center}
        \begin{center}
            \begin{figure}[h]
               \centering
                
                \caption{Prototipo impreso con Anet A8 master v2}
                \label{fig:mesh1}
            \end{figure}
        \end{center}

\section{Conclusiones}
    Tras desarrollar los primeros prototipos se procedió a llevar a cabo una prueba real con los mismos 
    en un entorno industrial para comprobar si era necesaria una versión 2.0 de los mismos, los resultados
    dejaron claro que este primer diseño era el acertado.

    Execeptuando una caida accidental todos los diseños sobrevivieron a la prueba, las imágenes dentro de la planta
    no han sido posibles de llevar a cabo por seguridad y ausencia de permisos por parte de administración.

\end{document}

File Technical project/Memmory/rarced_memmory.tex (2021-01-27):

\documentclass[paper=a4, fontsize=11pt,twoside]{scrartcl}	% KOMA
\usepackage[a4paper,pdftex]{geometry}	% A4paper margins
\setlength{\oddsidemargin}{5mm}			% Remove 'twosided' indentation
\setlength{\evensidemargin}{5mm}
\usepackage[protrusion=true,expansion=true]{microtype}	
\usepackage{amsmath,amsfonts,amsthm,amssymb}
\usepackage{graphicx}
\usepackage[spanish]{babel}
\usepackage[hidelinks]{hyperref}
\usepackage{graphicx}
\usepackage{xcolor}
\usepackage{fancyhdr}
\usepackage{hyperref}
\usepackage[T1]{fontenc}
\usepackage{lmodern}
\newcommand{\HRule}[1]{\rule{\linewidth}{#1}} 	% Horizontal rule
\usepackage{float}

\graphicspath{ {./images/} }
\makeatletter							
\def\printtitle{%						
{\centering \@title\par}}
\makeatother									
\makeatletter							
\def\printauthor{%					
{\centering \large \@author}}				
\makeatother							
\title{	\normalsize \textsc{DOCUMENTO TÉCNICO} 	
		 	\\[2.0cm]								
             \HRule{0.5pt} \\						
             \LARGE \textbf{\uppercase{Sistemas de posicionamiento de objetos mediante la tecnología Bluetooth Low Energy, modo Beacon}}	
			\HRule{2pt} \\ [0.5cm]		
			\normalsize \today			
		}
\author{
    Rubén Arce Domingo\\	
		Máster en automatización y robótica\\	
        industrial\\
        akimbo170@gmail.com\\
}
\begin{document}
\thispagestyle{empty}		
\printtitle					
  	\vfill
\printauthor				
\newpage
\cleardoublepage
\tableofcontents
\listoffigures
\cleardoublepage
\pagestyle{fancy}
\fancyfoot[R]{Rubén Arce}
\fancyfoot[L]{BLE Tracking - 2021}
\section{Memoria descriptiva}
    \subsection{Antecedentes y objeto del proyecto}
        Este proyecto surge como respuesta a la necesidad de poder localizar un número elevado de equipos en 
        constante movimiento con exactitud en un espacio cerrado.
        \paragraph{}
       Los objetivos principales son los siguientes:
        \begin{enumerate}
            \item Estudiar las distintas alternativas para llevar a cabo el tracking de objetos de una forma
            sencilla y sin requerir de una gran inversión.
            \item Analizar las tecnologías existentes para la monitorización en interiores.
            \item Estudiar del parámetro Rssi como medida de la potencia de una señal y cálculo de la distancia entre equipos.
            \item Desarrollar un sistema de visualización a través de un mapa sobre el que situar los equipos en movimiento.
            \item Diseñar un hardware específico para la aplicación requerida.
            \item Programar tanto el equipo emisor como el receptor, así como del algoritmo de visualización.
            \item Comprobar el rendimiento del equipo y llevar a cabo pruebas de campo. 
        \end{enumerate}
        \paragraph{}
        Una vez fijado el alcance del proyecto se puede empezar a planificar el mismo y buscar la mejor solución 
        posible, por ello surgen los siguientes objetivos derivados de los primeros para poder sacar el producto 
        al mercado:
        \begin{enumerate}
            \item Fijar un precio muy competitivo.
            \item Desarrollar un producto estándar y de fácil aplicación.
            \item Facilitar una instalación sencilla por un usuario no técnico.
            \item Conseguir un mantenimiento escaso o nulo.
            \item Producto seguro y que esté preparado para superar los marcados UL
            (Underwriters Laboratories) y CE (Conformidad Europea) así como protecciones frente a electricidad estática.
        \end{enumerate}
    \subsection{Ámbito de aplicación}
        El tracking de objetos en espacios cerrados está incrementando su popularidad debido a que es una 
        arma de publicidad muy poderosa que demandan los grandes centros comerciales para llevar a cabo estudios de marketing
        y poder analizar el comportamiento de sus clientes.
        \paragraph{}
        El mayor nicho de mercado es aplicado a no tener que interactuar tocando los objetos, 
        esto, teniendo en cuenta los tiempos que corren, es una necesidad de numerosas empresas privadas, ayuntamientos 
        y empresas estatales.
        \paragraph{}
        A modo de resumen se engloban los principales ámbitos de aplicación de esta tecnología:
        \begin{enumerate}
            \item Marketing: Estudios de mercado y de necesidad de los clientes. Elaboración de un "heat map", o mapa 
            de las zonas con más afluencia de gente.
            \item Sanidad: Monitorización de pacientes en planta. 
            \item Seguridad: Únicamente los empleados con autorización y proximidad podrán llevar a cabo acciones,
            esto tiene sentido a la hora de no tener que dar a cada trabajador una llave que pueda replicarse.
            \item Vandalismo: Conociendo la localización de los equipos dentro de un local cerrado, en el momento 
            en el que se deja de situar un elemento en el mapa, se puede dar la voz de alarma ante un robo.
            \item Propaganda y nueva forma de publicidad: Activar acciones en función de la localización en determinados
            puntos de interés permite llevar a otro nivel las ideas de los publicistas.
        \end{enumerate}
        Vemos por tanto que hay numerosas aplicaciones y una alta demanda de este producto tecnológico, es por ello por lo que se 
        procede a explorar cual es la forma más adecuada para llevarlo a cabo e implementarlo.
    \subsection{Análisis de soluciones al tracking de objetos}
        Se plantean dos problemáticas, en primer lugar se busca llevar a cabo el seguimiento de elementos en movimiento, y por otro lado, 
        se ha de enviar esta información de alguna forma al sistema correspondiente para que lleve a cabo el análisis de los datos. Esta
        última acción es esencial en el proceso, es lo realmente interesante desde el punto de vista del cliente final de esta tecnología.
        En lo que respecta a la obtención de datos de posición relativa de objetos o personas se presentan las siguientes opciones:
        \subsubsection {Wifi}
            Llevar a cabo el tracking mediante la escucha de wifis es una posibilidad, para ello sería
            necesario que, inicialmente, se colocara un móvil en cada uno de los objetos a identificar. Esto es aceptable 
            en el caso de monitorización de personas pero inasumible para objetos.
            \paragraph{}
            El procedimiento consistiría en llevar a cabo un barrido de direcciones MACs que generan los móviles cuando tienen el wifi activado,
            es decir que este sistema no funcionaría en el caso de que una persona lleve puestos los datos del móvil únicamente.
            \paragraph{}
            Otra desventaja es el hecho de que al tener un equipo buscando wifis la información personal del propietario, es decir, localización,
            fecha, hora a la que se intentó conectar y dirección MAC que identifica y relaciona un móvil a una persona, queda expuesta.
            Se ha de tener en cuenta la política de privacidad vigente, la cual se incumpliría al emplear esta tecnología para llevar a cabo el tracking. 
            \begin{center}
                \begin{figure}[ht]
                    \centering
                    
                    \caption{Detección de personas aplicando redes wifi.}
                    \label{fig:mesh1}
                \end{figure}
            \end{center}
            La única solución al problema es que se ha de pedir permiso formal a la persona para poder llevar a cabo
            el tratamiento de sus datos, cosa que es dificil puesto que se desconoce quien va a llevar a cabo el uso del equipo.
            \paragraph{}
            El artículo 29 de privacidad de datos de la comunidad europea dice lo siguiente:
            “WiFi-tracking, depending on the circumstances and purposes of the data collection, such tracking under the GDPR is likely
            either to be subject to consent, or may only be performed if the personal data collected is anonymised”.
            Es por ello por lo que se tendrá en cuenta como opción aunque haya numerosos puntos en contra para implementar un sistema como este.
        \subsubsection {GPS}
            La tecnología por excelencia para llevar a cabo el seguimiento de objetos o personas es el GPS. La principal desventaja
            que presenta es el elevado consumo energético comparado con el wifi o el bluetooth.
            \paragraph{}
            Mantener un módulo GPS encendido y pretender llegar a una autonomía de años es a día de hoy
            imposible, es por ello por lo que existen dos opciones.
            O se emplea un teléfono móvil para llevarlo a cabo, cosa inviable si se intentan monitorizar objetos y no personas en
            movimiento, o el tiempo de refresco de los datos ha de ser muy lento, del orden de horas,
            cosa de nuevo inasumible para la aplicación que se presenta.
            \paragraph{}
            Por otro lado, se ha de tener en cuenta también el aumento de precio que supondría un módulo GPS sumado a la antena que lleva consigo de 
            dimensiones nada despreciables. 
            Consecuentemente, esta tecnología se tendrá en cuenta pero no es la más adecuada para la problemática presente.
        \subsubsection {Bluetooth Low Energy - Beacon}
            La tecnología Bluetooth es un estándar industrial aplicado a conexiones inalámbricas que permite transferir 
            grandes cantidades de información en distancias cortas a bajas velocidades. Puede ser enfocado a conexión
            punto a punto, o como es nuestro caso llevar a cabo una red de equipos que emiten en modo broadcast.
            \paragraph{}
            La potencia de emisión va desde los -20 dBm (0.01 mW) hasta los +20 dBm (100 mW). Cuanta mayor potencia de emisión, mayor consumo energético
            del dispositivo, pero también conseguiremos una mayor distancia de escaneo.
            \paragraph{}
            La forma de envío de datos que más encaja dentro de la tecnología BLE (Bluetooth Low Energy) es Beacon o baliza, un 
            dispositivo que transmite una señal de bluetooth cada cierto tiempo y es visible por cualquier otro equipo que escuche 
            en esa misma frecuencia. La principal ventaja es que no es necesario llevar a cabo la conexión al equipo que escucha.
            Existen varios tipos de beacons:
            \begin{enumerate}
                \item iBeacon: Fue la primera tecnología BLE Beacon desarrollada por Apple. Permite leer y emitir en modo 
                broadcast para cualquier dispositivo que disponga de Bluetooth low energy. Es un protocolo propietario, es 
                decir es un estándar cerrado. 
                Los iBeacons disponen de los siguientes identificadores:
                \begin{itemize}
                    \item UUID: Indentificador único del dispositivo, una cadena de carácteres de 16 bytes
                    que permite caracterizar a cada equipo.
                    \item Major: Número entero de 0 a 65535, se usa para identificar grupos, un ejemplo sería 
                    asignar un Major común para todos los beacons de una misma planta o habitación.
                    \item Minor: Es también un número entero de 0 a 65535 que se emplea para distinguir un Beacon
                    específico dentro de un grupo, entendiéndose como grupo aquellos beacons con mismo valor de Major.
                \end{itemize}
                \begin{center}
                    \begin{figure}[ht]
                        \centering
                        
                        \caption{Trama de bytes de cabecera de modo iBeacon (Apple).}
                        \label{fig:mesh2}
                    \end{figure}
                \end{center}
                \item Eddystone: Creado por Google, es un protocolo de código abierto. A diferencia del protocolo anterior este 
                permite transmitir:
                \begin{itemize}
                    \item URL: Un url propio de una web, de esta forma se evita la necesidad de tener que contar con una app instalada.
                    \item UID: Similar al UUID del iBeacon, este parámetro identifica al Beacon y permite llevar acciones individuales.
                    \item TML: Permite enviar información relativa al Beacon, como por ejemplo, el porcentaje de batería o valores de sensores.
                \end{itemize}
                \begin{center}
                    \begin{figure}[ht]
                        \centering
                        
                        \caption{Modo Beacon Edison (Google) }
                        \label{fig:mesh3}
                    \end{figure}
                \end{center}
                \item AltBeacon: Es un protocolo de código abierto que surge como resultado de las incompatibilidades de las dos 
                tecnologías anteriores, la ventaja principal es que permite más flexibilidad de modificaciones así como compatibilidad 
                entre sistemas operativos.
    \subsection{Análisis de opciones de subida de datos}
        Una vez exploradas las opciones de posicionamiento de los equipos se llevará a cabo el estudio de posibilidades de subida de estos datos
        a la nube, es por ello por lo que se contemplarán varias opciones:
        \subsubsection {MQTT}
            MQTT (Message Queing Telemetry Transport) es un protocolo estándar aplicado principalmente al IoT (Internet of Things). Está basado en publicación y 
            suscripción con un servicio de mensajería push. Los mensajes se publican en topics, sobre los cuales los distintos 
            dispositivos se encuentran escuchando.
            La base de la comunicación es el Broker, encargado de dar soporte a todos los topics, los clientes inician una 
            conexión TCP/IP con él que se mantiene abierta constantemente hasta que el cliente la finalice. Se emplean los puertos
            1883 o 8883 con seguridad TLS.
            Cada mensaje tiene un QoS (Quality of service), es el mecanismo de calidad del servicio, o lo que es lo mismo es la forma de
            gestionar la robustez de los mensajes entre clientes y ante los fallos de conectividad.
            \begin{itemize}
                \item QoS 0: Envío una única vez
                \item QoS 1: Mensaje enviado hasta que se garantiza que se entrega.
                \item QoS 2: Garantizado que cada mensaje se entrega al suscriptor por una única vez.
            \end{itemize}
            Esta es una opción para conseguir que los equipos que escuchan a los beacons envíen a un mismo
            topic la información obtenida por bluetooth. Será el sistema de visualiación el que esté escuchando también en 
            el mismo topic.
        \subsubsection {HTTP Post}
            A través del protocolo de transferencia de hipertexto se puede llevar a cabo una petición post, la cual consiste en que
            un servidor acepte los datos recibidos por el microcontrolador.
            La ventaja es que con el HTTP post solo se mantiene la conexión abierta al hacer la conexión, luego se desconecta hasta 
            la siguiente vez en la que se vuelvan a publicar datos. 
            \paragraph{}
            Otra ventaja es que mediante peticiones se pueden transferir datos a distintos servidores.
            Por el contrario, con MQTT solo se puede enviar información a aquellos servidores que estén suscritos al mismo tópic que el dispositivo.
            \paragraph{}
            El principal inconveniente es que está demostrado que en una red 3G, una petición post es del orden de 93 veces
            más lenta que un mensaje MQTT, con el consiguiente consumo energético que esto conlleva. Otro inconveniente es el hecho 
            de que se requiera de un servidor con una API o endpoint que esté constantemente escuchando a los distintos posts.
        \subsubsection {ESP Now}
            Se plantea la opción de que no todos los equipos que escuchan a los beacons dispongan de conexión a internet, es por ello
            por lo que se baraja la posibilidad de llevar a cabo una red de elementos que escuchan y que envían a un único concentrador encargado de enviar
            esta información a internet por cualquier otro método.
            Es decir, se contempla la opción de establecer una red de elementos que escuchan, para lo cual se emplea 
            un protocolo de comunicación rápido denominado ESP-NOW, que tiene las siguientes características:
            \begin{itemize}
                \item Encriptación de las comunicaciones.
                \item Hasta 250 Bytes de payload o mensaje a enviar.
                \item Rapidez de comunicación entre microcontroladores.
            \end{itemize}
            \paragraph{}
            La idea sería la siguiente:
            \begin{enumerate}
                \item El equipo que lleva a cabo el barrido y búsqueda de beacons escanea e intenta conectarse a 
                internet por wifi.
                \item Si lo consigue publica los datos, en el caso de que falle enviará por ESP NOW la información
                que no puede subir a internet a otro equipo en su misma red que si que pueda.
                \item Este segundo hará lo mismo hasta que finalmente alcance con uno que sí que pueda subir estos datos.
            \end{enumerate}
            \begin{center}
                \begin{figure}[ht]
                    \centering
                    
                    \caption{Diagrama explicativo de una red de ESP32.}
                    \label{fig:mesh4}
                \end{figure}
            \end{center}
        \end{enumerate}
    \subsection{Resultados finales}
        Una vez analizadas las dos problemáticas y las distintas soluciones a cada una de ellas, se ha confeccionado la siguiente tabla 
        en la que se puede ver una comparativa entre cada una de ellas.

        Por un lado está la forma en la que poder medir las distancias de los equipos con respecto a los equipos que escuchan,
        se contemplan las siguientes opciones:
        \begin{center}
            \addcontentsline{lot}{table}{Comparativa de opciones de posicionamiento}
            \begin{tabular}{|c | c| c| c| c |} 
            \hline
            Tecnología  & Coste  & Complejidad & Distancia & Consumo energético \\ [0.5ex] 
            \hline
            GPS& Elevado& Baja & Ilimitada& Muy alto\\
            Wifi& Medio& Media & ~ 100 m & Alto\\ 
            Bluetooth& Bajo& Media & ~ 100 m & Muy bajo\\ 
            \hline
            \end{tabular}
        \end{center}   
        El claro ganador en este caso es el Bluetooth, debido, principalmente, al precio que supondría llevar a cabo una red de estas 
        características, así como el bajo consumo energético que hace que el mantenimiento de los equipos sea casi inexistente.
        \paragraph{}
        Recordemos que una de las premisas iniciales era que los equipos requieran poco cuidado por parte del cliente, 
        lo que se consigue empleando esta tecnología en la que solo es necesario cambiar una pila una vez al año.
        \paragraph{}
        En lo que respecta a la comunicación de estos datos de distancia entre equipos a internet, se ha reunido de nuevo en la 
        siguiente tabla un resumen con las opciones y los puntos a favor y en contra de cada una de las tecnologías.
        \begin{center}
            \addcontentsline{lot}{table}{Comparativa de opciones de subida de datos a Internet}
            \begin{tabular}{||c | c| c| c||} 
            \hline
            Tecnología  & Velocidad de datos & Coste & Complejidad \\ [0.5ex] 
            \hline
            MQTT& Elevada  & No & Baja\\
            HTTP POST& Baja & Medio & Baja\\ 
            ESP NOW& Media & No & Alta\\ 
            \hline
            \end{tabular}
        \end{center}   
        La elección en este caso está mucho más ajustada, en el caso de que se pueda conectar a todos los equipos que 
        escuchan a internet el ganador será la opción de MQTT, puesto que es la forma más fácil de llevar a cabo el envío de datos.

        Si que no llegara la señal wifi a todos los puntos en los que se decida llevar a cabo el tracking de objetos 
        surge un problema puesto que perderemos esos datos. La solución es hacer que este equipo, que no tiene conexión a internet,
        envíe los datos por ESP NOW a otro que si que sea capaz de subir tanto su información como la de su compañero al broker por MQTT.

        Puesto que se pretende llevar a cabo un sistema válido para toda la casuística de instalaciones, se han contemplado ambas opciones
        y la implementación real llevará a cabo los dos métodos.
        
        Es decir, que la única opción desechada ha sido la conexión directa con un servidor mediante HTTP debido a que, en primer
        lugar sería necesario programar un servicio que escuchará en este endpoint y luego sería necesario hostearlo 
        para que disponga de una IP pública estática y sea accesible desde cualquier parte del mundo.
    \subsection{Planificación}
        \paragraph{}
        Para sintetizar el proceso de desarrollo del proyecto técnico se empleará un diagrama GANTT. En la
        figura 5 podemos ver la evolución del desarrollo del mismo así como la duración exacta de cada etapa. 
        \begin{center}
            \begin{figure}[H]
                \centering
                
                \caption{Diagrama de GANTT del proyecto.}
                \label{fig:mesh18}
            \end{figure}
        \end{center} 
\section{Memoria justificativa}
    \subsection{Cálculos justificativos de la instalación}
        En este apartado se llevará a cabo el estudio de la viabilidad del proyecto desde el punto de vista
        técnico, para lo cual se contemplará un estudio del Rssi como forma de medir distancia, un análisis 
        de la previsión energética de los equipos, un análisis del las frecuencias y ganancias de las antenas 
        empleadas.
    \subsection{Cálculo de distancia por Rssi}
        \subsubsection{Rssi}
            \paragraph{}
            El Rssi (Received signal strength indicator) es un indicador de la energía o potencia recibida en un mensaje de radio. 
            Está asociado con la atenuación de la señal, cuanto más pequeña es su valor menor atenuación. Este valor está 
            presente no solo en Bluetooth sino también en el Wifi (2,4 GHz) o en las bandas de radio industriales, científicas y médicas,
            las denominadas ISM (desde 433MHz a 458.5MHz y desde 860MHz a 960MHz)
            \paragraph{}
            De las muestras obtenidas en pruebas de campo con bluetooth se puede concluir que es posible llegar a estimar la distancia
            a partir de los valores de Rssi con un error que disminuye cuanto más alejados se encuentren los elementos a medir. 
            \paragraph{}
            Los rangos del Rssi se obtienen bien por aproximaciones teóricas o bien por experimentación. Esto es debido a que 
            es fuertemente alterado por las condiciones del medio en el que se encuentre. Asimismo es importante mencionar que
            este parámetro es medido a través de un hardware que rara vez tiene un comportamiento idéntico, eso explica las fluctuaciones 
            también.
            \paragraph{}
            Los modelos de cálculo del Rssi se basan en la pérdida de señal en el espacio, como sabemos la potencia de la señal
            disminuye con el cuadrado de la distancia. Esta ecuación de Friis para la transmisión libre en el espacio es 
            una fórmula teórica, existen aproximaciones obtenidas por métodos empíricos:
            \begin{equation}
                P_L(d) [dB] = P_L(d_0) [dB] + 10n * \log_{10} \frac{d_i}{d_0} 
            \end{equation}
            \paragraph{}
            Siendo PL (d0) la pérdida de propagación a 1 metro y n una constante que depende del medio, será igual
            a 2 si se encuentra en el espacio libre sin obstáculos ni reflexiones o dispersiones de señal.
            \paragraph{}
            Para calcular este parámetro n se ha de aplicar la siguiente fórmula, como podemos ver para llevar a cabo el 
            cálculo se han de tomar valores empíricos de potencias:
            \begin{equation}
                n = \frac{ P_L(d_i) - P_L(d_0) }{10n*\log_{}\frac{d_i}{d_0}}
            \end{equation}
            \paragraph{}
            Por lo tanto, y una vez obtenidos los valores de potencia a distintas distancias, podemos obtener la ganancia
            de la señal recibida:
            \begin{equation}
                Rssi [dBm] = -10n*\log_{10} d+ A[dBm]
            \end{equation}
            \paragraph{}
            Disponiendo ya del valor de la constante de pérdidas, d, calculado con la ecuación (2) y los valores
            de Rssi medidos desde la antena receptora a 1 metro de distancia, (3), podemos obtener:
            \begin{equation}
                d= 10^\frac{-(Rssi - A)}{10n}
            \end{equation}
            Llevados a cabo los cálculos por parte del equipo que escucha a los distintos beacons, podemos calcular la distancia 
            real a cada uno de ellos. En el caso de que se solapen y dos receptores escuchen el mismo Beacon será necesario
            llevar a cabo el proceso de trilateración expuesto a continuación.
            Para comprobar la fluctuación del parámetro del Rssi se ha llevado a cabo la toma de este parámetro a lo largo de un 
            periodo de tiempo largo y los resultados a 2 metros y a 3 metros se encuentran respectivamente en la figura 6. 
 
            Podemos ver que hay pequeñas flucuaciones y es por ello por lo que será necesario implementar un sencillo filtro para
            evitar el ruido electromagnético que hemos visto anteriormente.
            
            Se ha llevado a cabo la prueba de incrementar el número de iBeacons y situarlos a la misma distancia del 
            equipo que escucha, los resultados se muestran en la figura 7.
            
            Análogamente las diferencias son notables, esto demuestra la necesidad de implementar
            un filtro que no falsee las medidas y cree distancias incoherentes puntuales entre los equipos.
            
            El filtro más habitual para este tipo de aplicaciones es el denominado Kalman Filter:
            \begin{equation}
                Rssi_{suavizado} = \alpha * Rssi_{n} + (1-\alpha) * Rssi_{(n-1)}
            \end{equation}
            Otra opción que experimentalmente ha dado buenos resultados es la de selecionar los 20 valores anteriores,
            obtener la media y si se separa más de un 40\% el valor nuevo lo rechazo. Con esto consigo eliminar las 
            fluctuaciones indesadas que se podían apreciar en la figura 6.
            \begin{center}
                \begin{figure}[ht]
                    \centering
                    
                    
                    \caption{Prueba de campo, medición Rssi de Beacons a 2 y 3 metros.}
                    \label{fig:mesh5}
                \end{figure}
            \end{center}
            \begin{center}
                \begin{figure}[ht]
                    \centering
                    
                    \caption{Variaciones de Rssi entre beacons a distancias iguales.}
                    \label{fig:mesh6}
                \end{figure}
            \end{center}

        \subsubsection{Trilateración y posicionamiento}
            Una vez obtenidas las distancias a los distintos equipos de receptores es necesario llevar a cabo el
            posicionamiento exacto de los mismos, para ello se emplea la trilateración:
            \begin{center}
                \begin{figure}[H]
                    \centering
                    
                    \caption{Trilataración con tres equipos escuchando al mismo Beacon.}
                    \label{fig:mesh7}
                \end{figure}
            \end{center}
                Hemos de resolver las siguientes ecuaciones básicas sobre la distancia entre recta y un punto en 
                una circunferencia, en la figura 8 podemos verlo gráficamente.
                \begin{equation}
                    d_{A1}= \sqrt[]{(x-x_A)^2+(y-y_A)^2}
                \end{equation}
                \begin{equation}
                d_{B1}= \sqrt[]{(x-x_B)^2+(y-y_B)^2}
                \end{equation}
                \begin{equation}
                    d_{C1}= \sqrt[]{(x-x_C)^2+(y-y_C)^2}
                \end{equation}
                Llevando a cabo la simplificación obtenemos un sistema de ecuaciones que permite calcular la distancia
                relativa a cada uno de los equipos que escuchan. En el anexo de software se muestran los resultados con mayor 
                detalle. En la figura 9 podemos ver un adelanto del posicionamiento de carros de la compra en un supermercado.
                \begin{center}
                    \begin{figure}[h]
                        \centering
                        
                        \caption{Posicionamiento de los beacons en carros de supermercado.}
                        \label{fig:mesh7}
                    \end{figure}
                \end{center}
                \paragraph{}
                % \url{https://journals.sagepub.com/doi/full/10.1155/2014/371350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,%2DPL(d).}
    \subsection{Cálculo de consumos energéticos}
            El procesador empleado, tanto para el equipo emisor como para el receptor, disponen de los siguientes modos de funcionamiento:
            \begin{itemize}
                \item  Active Mode: 160-260mA. Los dos cores del procesador encendidos, así como el procesador ULP,
                RTC, Wifi, Bluetooth, Radio, Peripherals.
                \item  Sleep mode: 3-20mA. Activos los dos cores, el coprocesaror ULP coprocessor y el RTC, inactivos el 
                Wifi, Bluetooth, Radio y periféricos.
                \item  Light sleep mode: La CPU está pausada apagando los pulsos de su reloj interno, sin embargo, el RTC
                y el coprocesador ULP se mantienen activos. Esto supone un consumo menor que en los anteriores modos de funcionamiento,
                se puede llegar a los 0.8mA.
                \item Deep sleep mode: tanto la CPU como gran parte de la RAM, así como todos los periféricos se mantienen 
                apagados. Las únicas parte no apagadas son los RTC de los periféricos y de la CPU (incluyendo el ULP) y su
                memoria interna. El chip consume en torno a los 0.15 mA si se mantiene encendido el ULP y  10µA si no.
                En el modo deep sleep todo se encuentra apagado, por ello los datos de la memoria del rtc se pierden
                puesto que se encuentra en reinicio el uC.
                \item Hibernation mode: A diferencia del modo deep sleep el oscilador de 8MHz y el ULP se encuentran apagados,
                no es posible almacenar nada de información. Tan solo el RTC funcinando con el reloj de baja velocidad puede funcionar.
                En este modo de funcionamiento el micro consume sobre los 2.5µA.
            \end{itemize}
            \begin{center}
            \addcontentsline{lot}{table}{Consumos energéticos ESP32.}
                \begin{tabular}{||c || c ||} 
                \hline
                Modo del ESP32  & Consumo energético  \\ [0.5ex] 
                \hline
                Wi-Fi Tx a 13dBm~21dBm & 160~260mA  \\ 
                Wi-Fi/BT Tx  a packet 0dBm	 & 120mA  \\
                Wi-Fi/BT Rx and listening & 80~90mA  \\
                Sleep mode &  3-20mA   \\
                Light sleep mode &0,8mA  \\
                Deep sleep mode &   0,15 mA - 10µA  \\
                Hibernation mode & 2,5µA  \\
                \hline
                \end{tabular}
            \end{center}
            A la hora de llevar a cabo la decisión sobre cómo llevar a cabo el protocolo de comunicación se ha de tener en cuenta 
            el consumo de los equipos, en especial en lo que respecta a los beacons.
            \paragraph{}
            Es por ello por lo que se ha optado por dormir al equipo durante 58 segundos, despertarlo,
            enviar su trama bluetooth y luego dormirlo hasta la siguiente vez que despierte.
            Con esto conseguimos un consumo que varía en función de la frecuencia de envío. En las siguiente tablas
            se puede ver un análisis en función del tiempo y en consecuencia la duración media de las baterías.
            Se ha puesto como ejemplo una frecuencia de envío de 10 minutos.
            \begin{center}
                \addcontentsline{lot}{table}{Frecuencia de envío frente a consumo medio.}
                \begin{tabular}{||c || c ||} 
                \hline
                Frecuencia de envío  & Consumo energético  \\ [0.5ex] 
                \hline
                1 min &  2,415 mA \\
                5 min &  0,495 mA \\ 
                10 min &  0,255 mA \\ 
                15 min &  0,175 mA \\ 
                30 min &  0,095 mA \\ 
                \hline
                \end{tabular}
            \end{center}
            \begin{center}
                \addcontentsline{lot}{table}{Frecuencia de envío frente a consumo medio.}
                \begin{tabular}{|c | c| c| c |} 
                \hline
                    Tipo de batería & Capacidad  & Autonomía(días) & Autonomía(días)   \\ [0.5ex] 
                    & (mAh) &  f=10 min &  f=5 min   \\ [0.5ex] 
                \hline
                \hline
                    Pila CRC 2032 &  240 mAh  & 39   & 20 \\ 
                    Pila AA       &  2500 mAh & 409  & 210 \\ 
                    Batería Li-Ion&  1600 mAh & 261  & 135 \\ 
                \hline
                \end{tabular}
            \end{center}
            Podemos ver por lo tanto como con una pila AA se podría llegar a conseguir sin problemas una autonomía de casi un 
            año, es por esta razón y por el tamaño reducido por lo el que se va a optar por esta solución.
            
    \subsection{Cálculo de ganancia de antenas}
            Una antena convierte la enegía electrica del transmisor en energía electromagnética y viceversa, las antenas pueden ser 
            para recibir, para transmitir o ambas. La localización de la antena, las dimensiones y el diseño pueden afectar drásticamente
            en el funcionamiento óptimo de la red de beacons. 
            Las antenas típicas en aplicaciones de radiofrecuencia con bluetooth son de -10dBm a 10dBm.

            El denominado path loss o atenuación de la señal de radio es la reducción de la densidad de potencia de una onda durante la 
            propagación en el espacio. Este parámetro es esencial a la hora de poder establecer una red de bluetooth de estas dimensiones.
            Las dimensiones de la antena se pueden llegar a obtener mediante:
            \begin{equation}
                f(Hz)=\frac{v(m/s)}{\lambda(m)}
            \end{equation}
            \begin{equation}
                \lambda_0(m)=\frac{v_0(m/s)}{f(Hz)} = \frac{2,998*10^8}{2,4*10^9} = 12,49 cm
            \end{equation}
            Para la aplicación que tenemos existen dos tipos de antenas:
            \begin{itemize}
                \item  Antenas monopolo $\lambda$/4: Menor tamaño pero menor eficiencia. 
                \item  Antenas dipolo $\lambda$ /2: Mayor tamaño pero mejores resultados.
            \end{itemize}
            Teniendo en cuenta que esta antena estará en una caja más grande y a la vista el tamaño no será un limitante.
            A modo de ejemplo en la figura 10 se muestra como es internamente cada una de las antenas.
            \begin{center}
                \begin{figure}[h]
                    \centering
                    
                    
                    \caption{Diferencia entre antena de media o cuarto de $\lambda$.}
                    \label{fig:mesh8}
                \end{figure}
            \end{center}
            Además se ha de tener en cuenta que las antenas atienden a su diagrama de radiación, es decir, al
            espectro tridimensional de emisión. Según la forma de radiación podemos distinguir.
            \begin{itemize}
                \item  Antenas isotrópica: Emite con la misma densidad en todas las direcciones.
                \item  Antenas omnidireccionales: Emite en torno a un solo plano isotrópico.
                \item  Antena directiva: Concentra la energía radiada en tan solo una dirección del espacio.
            \end{itemize}
            En la figura 11 podemos ver los lóbulos de emisión y recepción de radiofrecuencia de las distintas antenas.
            \begin{center}
                \begin{figure}[h]
                    \centering
                    
                    \caption{Tipos de antena en función del espectro de emisión.}
                    \label{fig:mesh10}
                \end{figure}
            \end{center}
            Dentro del mundo de las antenas existen numerosos modelos y opciones que se enumeran a continuación:
            \begin{enumerate}
                \item Antenas de cable: son las más sencillas de todas y como su propio nombre indica es un simple cable soldado a la PCB de una dimensión determinada, la cual se corresponde con la de una antena monopolo $\lambda$/4. El cable aporta el mayor rendimiento y rango de radiofrecuencia debido a sus dimensiones y a su caracter flexible, moldeable y orientable sin importar  la posición de la tarjeta.
                \item Antena PCB: es una pista en el propio circuito impreso que puede tener numerosas formas, a diferencia de la de cable esta solo se encuentra en el espacio 2D. Tiene menos eficiciencia que las anteriores y requiere más espacio pero son incluso más baratas.
                \item Antena de chip: este tipo de antena es una tarjeta o módulo que ocupa menos espacio que cualquiera de las anteriores y tiene un rendimiento intermedio entre ambas otras dos opciones.
            \end{enumerate}
            Por otro lado, se han llevado pruebas de campo con distintos modelos y distintas posiciones dentro de la caja, a continuación se muestran las 
            antenas con las que se han llevado a cabo las pruebas reales en la figura 12. 
            \begin{center}
                \begin{figure}[ht]
                    \centering
                    
                    \caption{Tipos de antena durante las pruebas de campo.}
                    \label{fig:mesh11}
                \end{figure}
            \end{center}
            Las conclusiones obtenidas son que las antenas pcb de $\lambda$ /2 obtienen más uniformidad en las medidas a igual distancia,
            mientras que las antenas de cable ofrecen mayor rango pero son menos discretas. En definitiva, la antena es algo esencial y más 
            allá del modelo elegido prioriza más el hecho de que todos los equipos de la red dispongan de exactamente el mismo diseño.
\section{Planos}
    \subsection{Planos mecánicos}
        Los planos catalogados como mecánicos hacen referencia a la estructura de plástico
        que sostiene y protege a la electrónica de las condiciones ambientales y de contacto directo con las 
        personas.
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

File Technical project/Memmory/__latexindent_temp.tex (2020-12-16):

\documentclass[a4paper ,12pt, onecolumn]{article}
\usepackage[utf8]{inputenc}
\usepackage[spanish]{babel}
\usepackage[hidelinks]{hyperref}
\usepackage{graphicx}
\usepackage{xcolor}
\usepackage{fancyhdr}

\graphicspath{ {./images/} }
\begin{document}
\pagestyle{fancy}
\fancyfoot[R]{Rubén Arce}
\fancyfoot[L]{BLE Tracking - 2020}
\title{Sistemas de posicionamiento de objetos mediante tecnología Bluetooth Low Energy Beacon }
\author{Rubén Arce}
\date{\today}
\maketitle
\cleardoublepage
\tableofcontents
\listoffigures
\listoftables
\cleardoublepage
\section{Memoria descriptiva}
    \subsection{Antecedentes y objeto del proyecto}
        Este proyecto surge como respuesta a la necesidad de poder localizar un número elevado de equipos en 
        constante movimiento con exactitud en un espacio cerrado.
        \paragraph{}
        Se pretende conseguir los siguientes objetivos:
        \begin{enumerate}
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

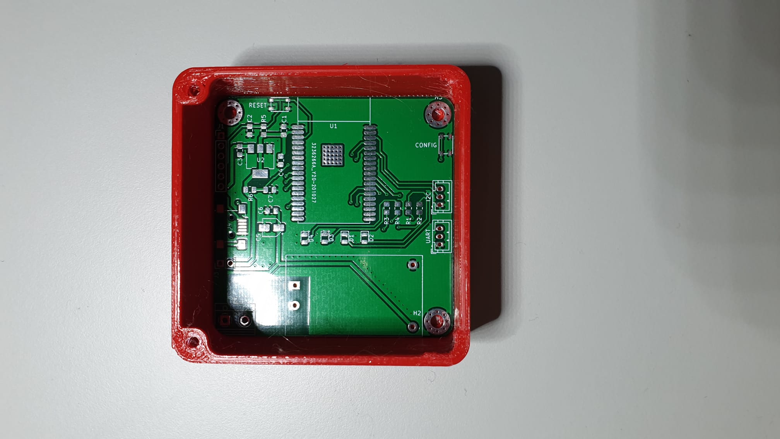
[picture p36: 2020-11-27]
Technical project/Schematics/3d_master_prototype.jpeg

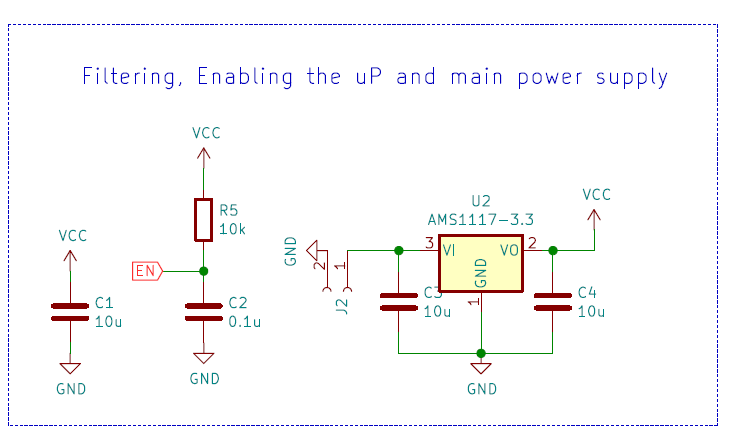
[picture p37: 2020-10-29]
Technical project/Schematics/emiter_main_power.PNG

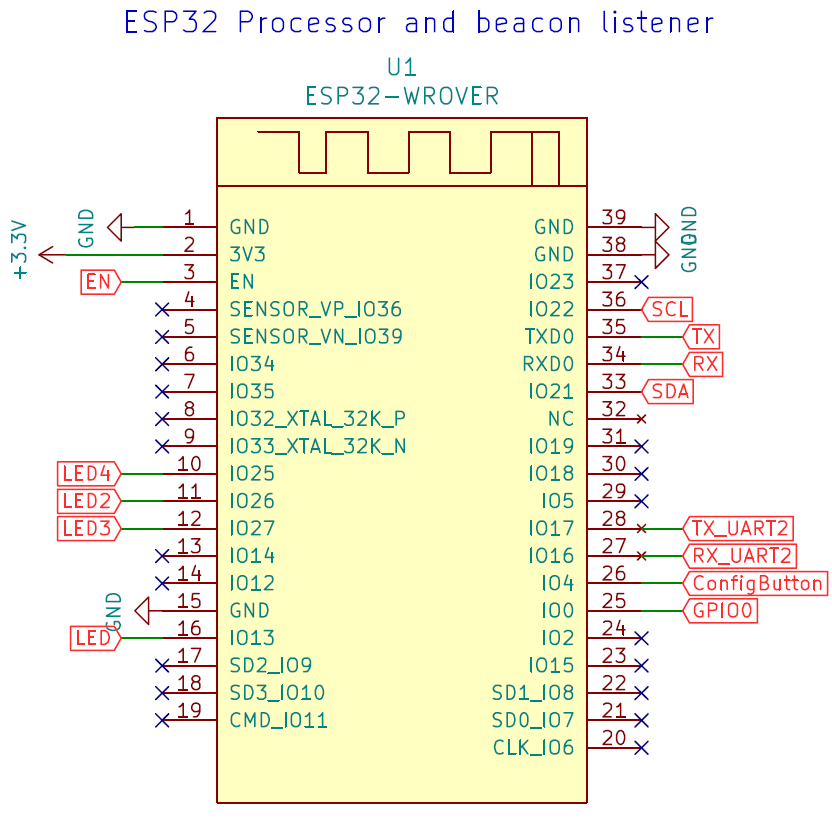
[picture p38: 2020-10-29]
Technical project/Schematics/receiver_uC.PNG

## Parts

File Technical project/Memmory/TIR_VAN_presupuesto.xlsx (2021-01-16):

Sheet: Hoja1
Coste PCB emisor |  |  |  | Flujo de caja:
Componente | Cantidad | Precio |  |  | PERIODO 0 | PERIODO 1 | PERIODO 2 | PERIODO 3
Resistencia metálica SMD 0805 1k 10 | 1 | 0.009 € | 0.009 € | Inversión Inicial/gastos | 1200.00 € | 4523.60 € | 4523.60 € | 4523.60 € | VAN | 4237.47 € | VALOR ACTUAL NETO
Resistencia metálica SMD 0805 10k 10 | 1 | 0.009 € | 0.009 € | Flujo de caja | -1200.00 € | 1776.40 € | 3476.40 € | 476.40 € | TIR | 163.6329853% | TASA INTERNA DE RETORNO
Condensador cerámico SMD 0805 0,1uF | 1 | 0.005 € | 0.005 €
Condensador cerámico SMD 0805 10uF | 1 | 0.016 € | 0.016 € | COK (coste de oportunidad) | 3%
Regulador tensión LDO AMS1117-3.3V | 1 | 0.098 € | 0.098 €
Microcontrolador ESP32 | 1 | 2.310 € | 2.310 €
Led SMD 0805 verde | 1 | 0.013 € | 0.013 €
Led SMD 0805 rojo | 1 | 0.013 € | 0.013 €
Led SMD 0805 naranja | 1 | 0.015 € | 0.015 € | Gastos Mensuales |  |  | Coste Equipos Instalación media
Batería de Ion Litio | 1 | 1.520 € | 1.520 € | Cuota autónomos | 283.30 € |  | Hardware | 140.00 €
 |  |  |  | Electricidad | 29.00 € |  | Software | 0.00 €
 |  |  |  | Gasolina, otros… | 53.00 €
TOTAL |  | 4.008 €
 |  |  |  | Durante el primer año tarifa de autónomos es de 60 €
 |  |  |  | Durante el segundo año tarifa de autónomos es del 50% de cuota
 |  |  |  | A continuación el 30% de la cuota hasta los dos siguientes años
Coste PCB emisor
Componente | Cantidad | Precio
Resistencia metálica SMD 0805 1k 10 | 1 | 0.009 € | 0.009 €
Resistencia metálica SMD 0805 10k 10 | 1 | 0.009 € | 0.009 €
Condensador cerámico SMD 0805 0,1uF | 1 | 0.005 € | 0.005 €
Condensador cerámico SMD 0805 10uF | 1 | 0.016 € | 0.016 €
Regulador tensión LDO AMS1117-3.3V | 1 | 0.098 € | 0.098 €
Microcontrolador ESP32-WROOM-32D | 1 | 2.840 € | 2.840 €
Led SMD 0805 verde | 1 | 0.013 € | 0.013 €
Led SMD 0805 rojo | 1 | 0.013 € | 0.013 €
Led SMD 0805 naranja | 1 | 0.015 € | 0.015 €
Pinheader conector para programación | 1 | 0.113 € | 0.113 €
UART-TTL herramienta de dasarrollo | 1 | 1.540 € | 1.540 €
Power Module AC-DC HI-LINK 3.3V | 1 | 2.830 € | 2.830 €
Screw terminal P=5.08mm | 1 | 0.097 € | 0.097 €
USB - Mini B Female USB 2 5 SMD USB Connectors | 1 | 0.108 € | 0.108 €
JST Connector P=2mm | 2 | 0.039 € | 0.078 €
Jumper connector | 1 | 0.017 € | 0.017 €
TOTAL: |  | 7.802 €

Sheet: Hoja2
DIAGRAMA DE GANTT
ACTIVIDAD | TIEMPO DE OPERACIÓN
 | SEPT |  |  |  | OCT |  |  |  | NOV |  |  |  | DIC |  |  |  | ENERO
 | 38 | 39 | 40 | 41 | 42 | 43 | 44 | 45 | 46 | 47 | 48 | 49 | 50 | 51 | 52 | 53 | 1 | 2 | 3 | 4
Fase 1: Analisis de la situación.
Fase 2: Definición de la problemática.
Fase 3: Búsqueda de soluciones y alcance del proyecto.
Fase 4: Desarrollo de hardware acorde a especificaciones.
Fase 5: Programación del receptor de los datos.
Fase 6: Programación del hardware.
Fase 7: Pruebas de campo.
Fase 8: Depuración tanto de programación como de bug en hardware.
Fase 9: Evolución del equipo en instalación.
Fase 10: Evaluación de producto y producción masiva.

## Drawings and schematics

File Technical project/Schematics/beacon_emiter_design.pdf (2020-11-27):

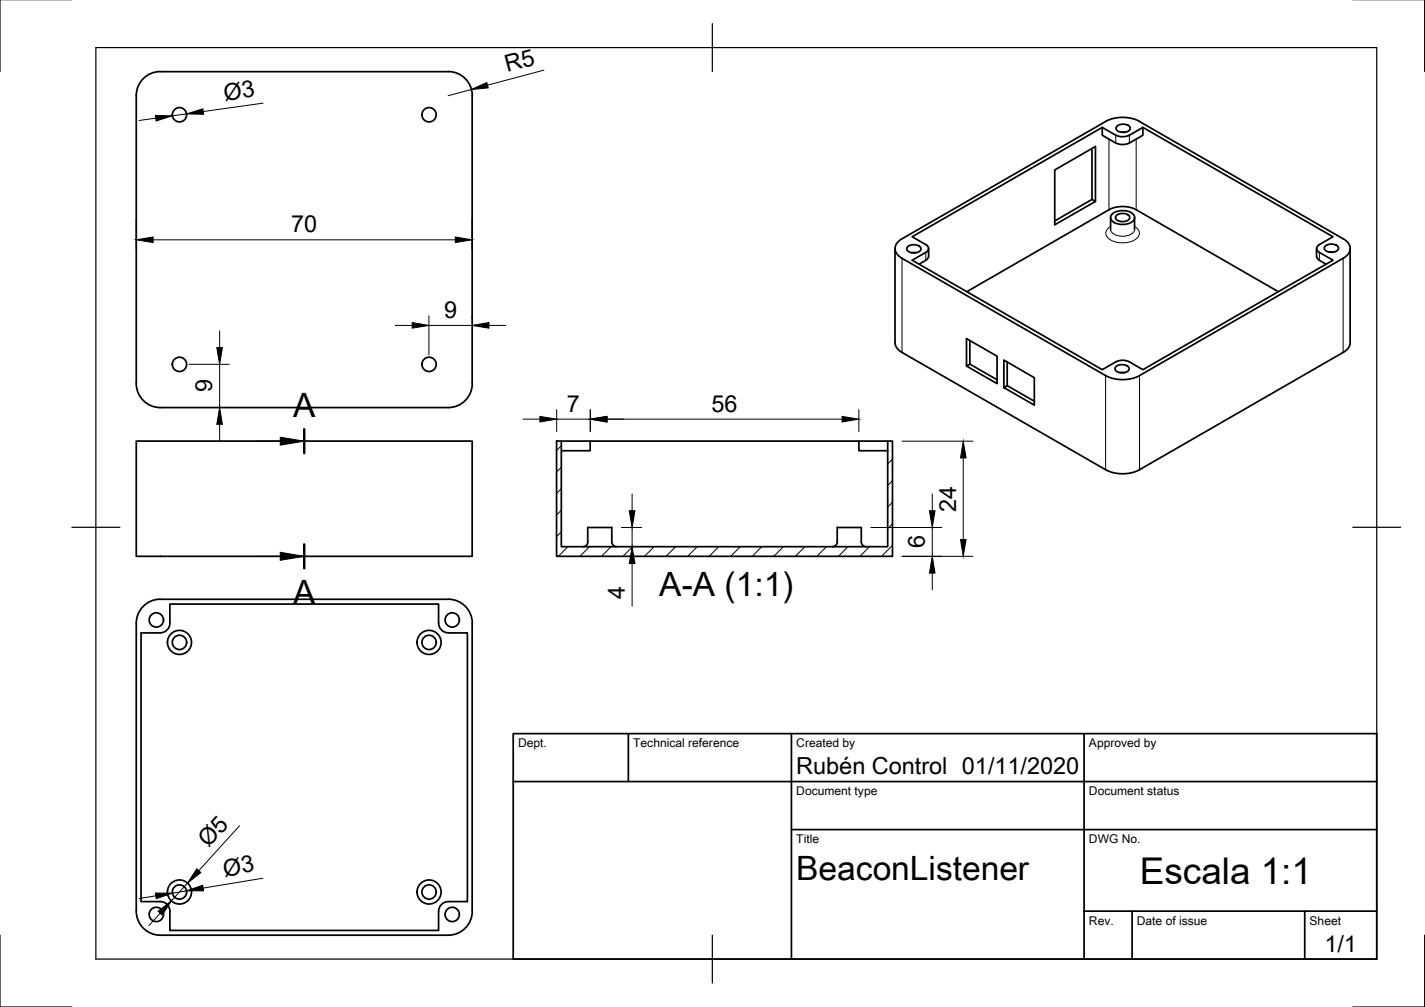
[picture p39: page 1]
Ø3 Escala 1:1

Dept. | Technical reference | Created by Rubén Control 01/11/2020 | Approved by

Document type | Document status

Title BeaconListener | DWG No.

Rev. | Date of issue | Sheet 1/1

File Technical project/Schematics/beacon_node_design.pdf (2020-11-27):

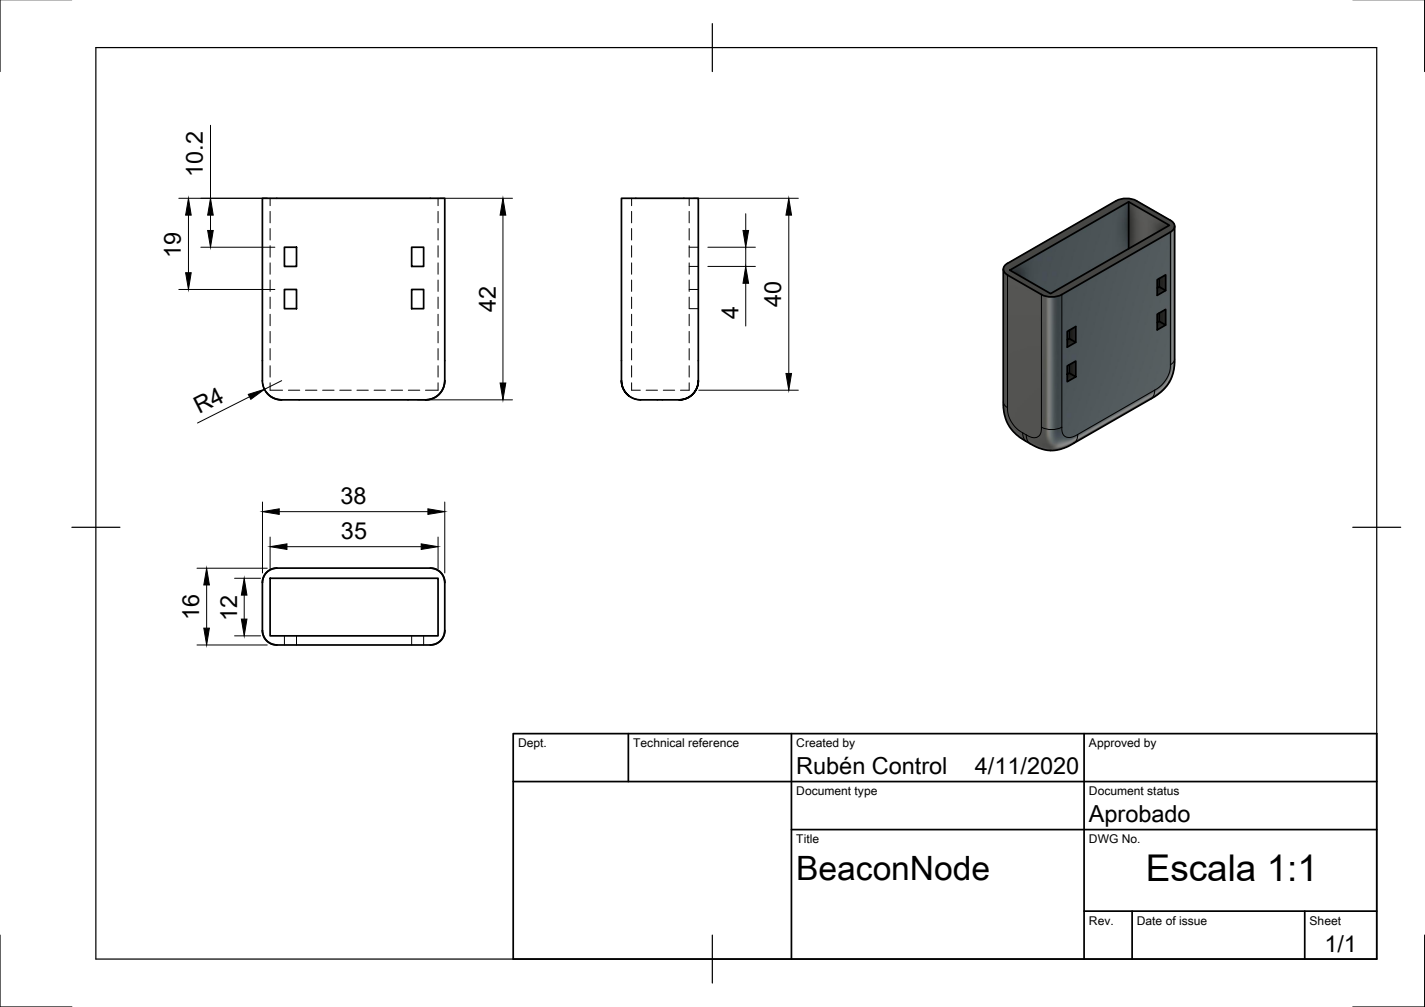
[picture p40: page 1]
Rubén Control 16

Dept. | Technical reference | Created by 4/11/2020 | Approved by

Document type | Document status Aprobado

Title BeaconNode | DWG No. Escala 1:1

Rev. | Date of issue | Sheet 1/1

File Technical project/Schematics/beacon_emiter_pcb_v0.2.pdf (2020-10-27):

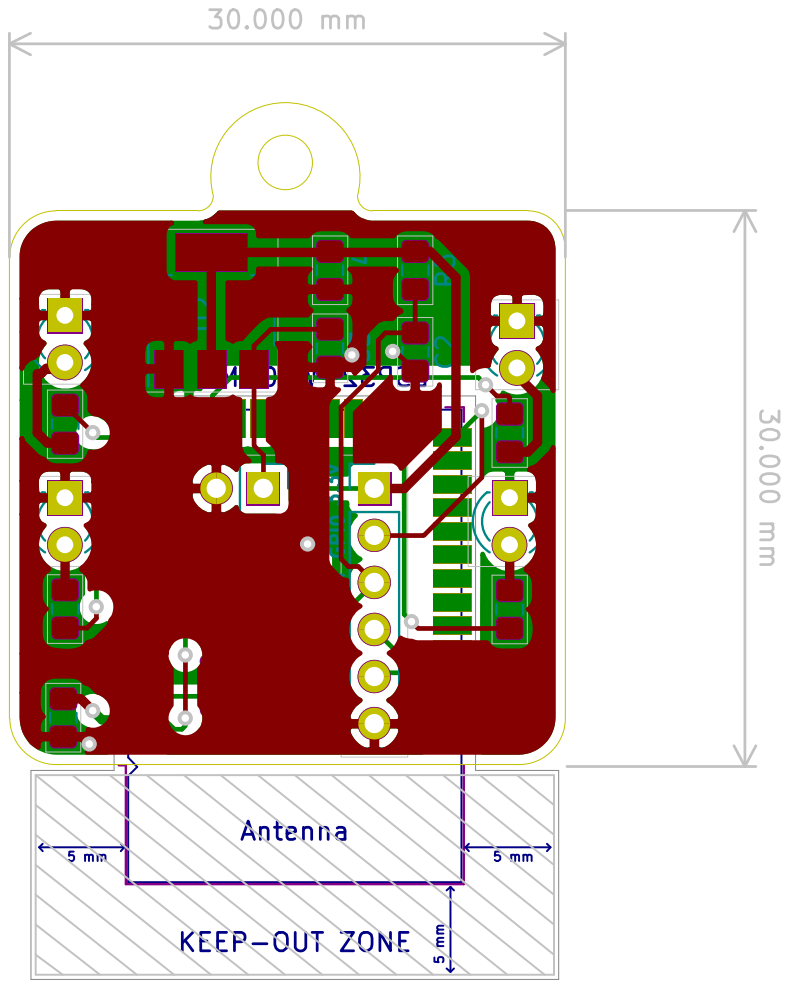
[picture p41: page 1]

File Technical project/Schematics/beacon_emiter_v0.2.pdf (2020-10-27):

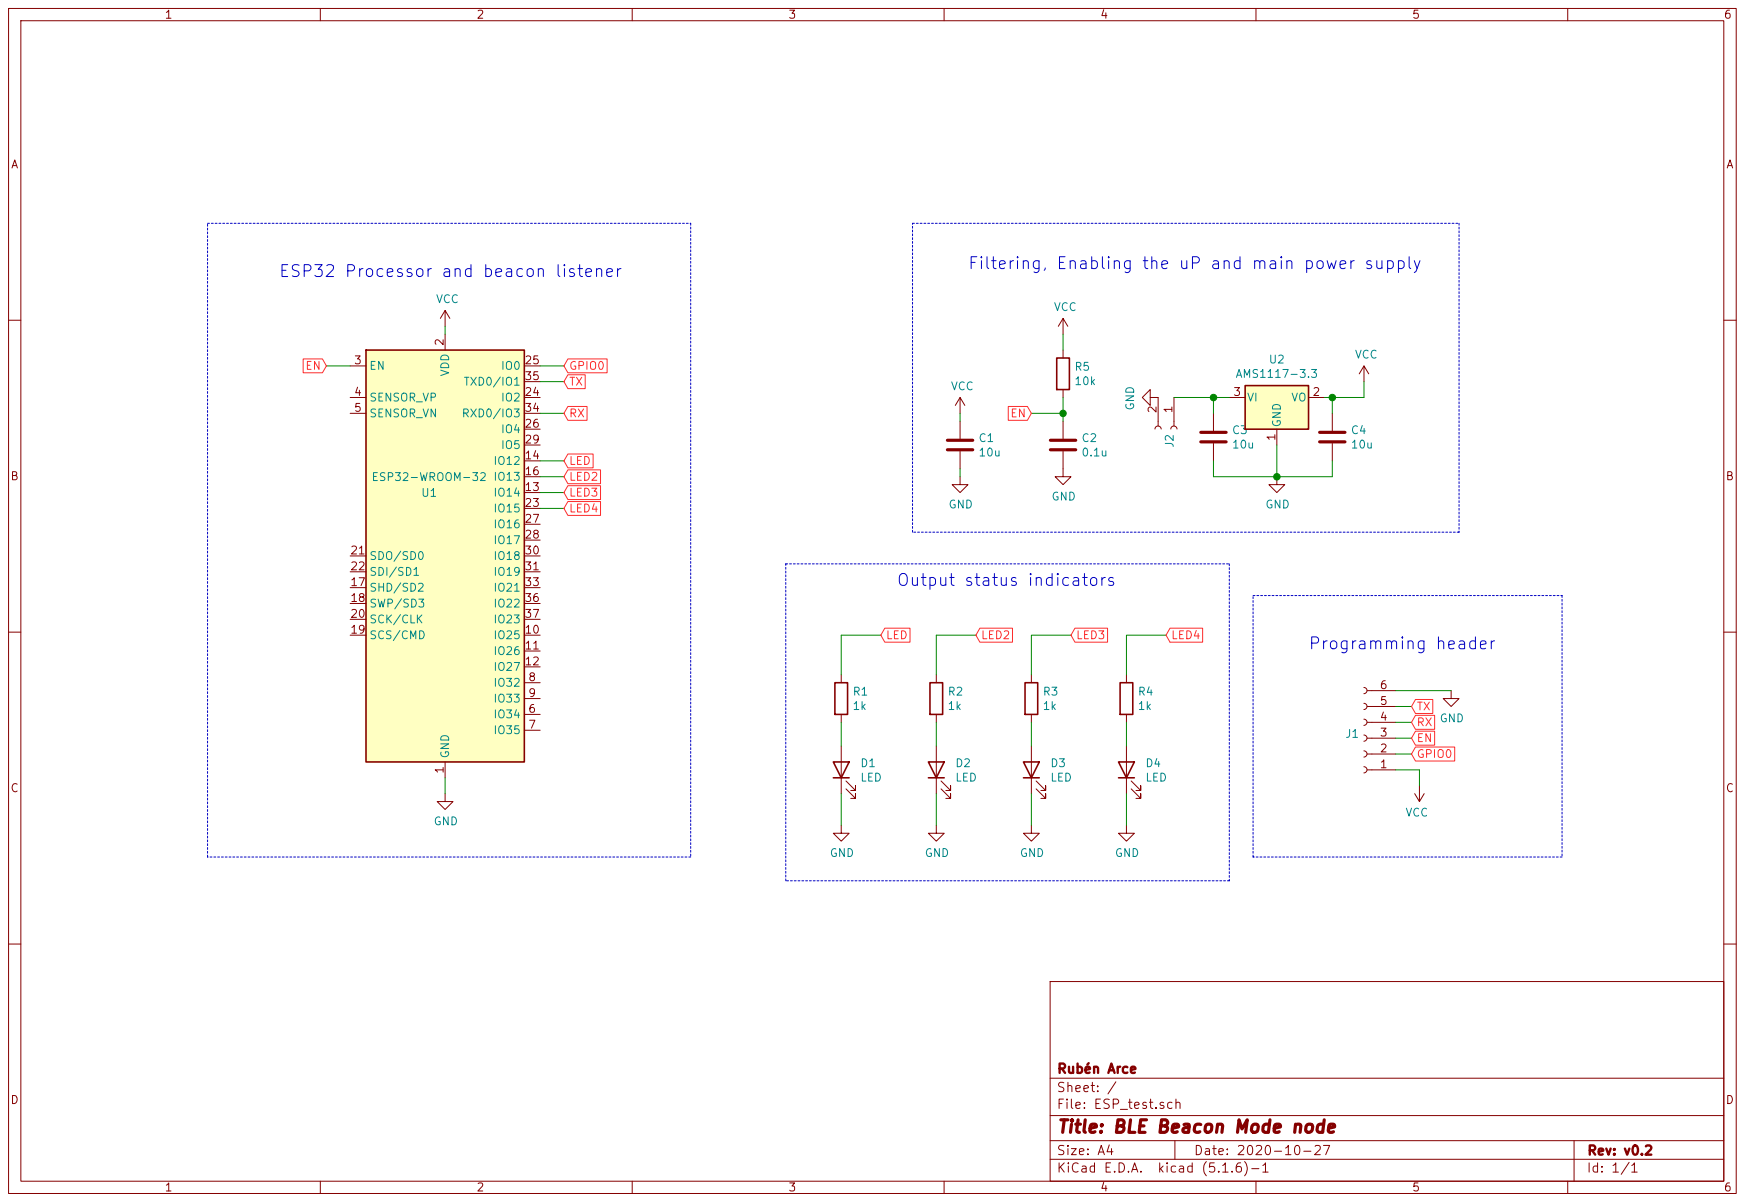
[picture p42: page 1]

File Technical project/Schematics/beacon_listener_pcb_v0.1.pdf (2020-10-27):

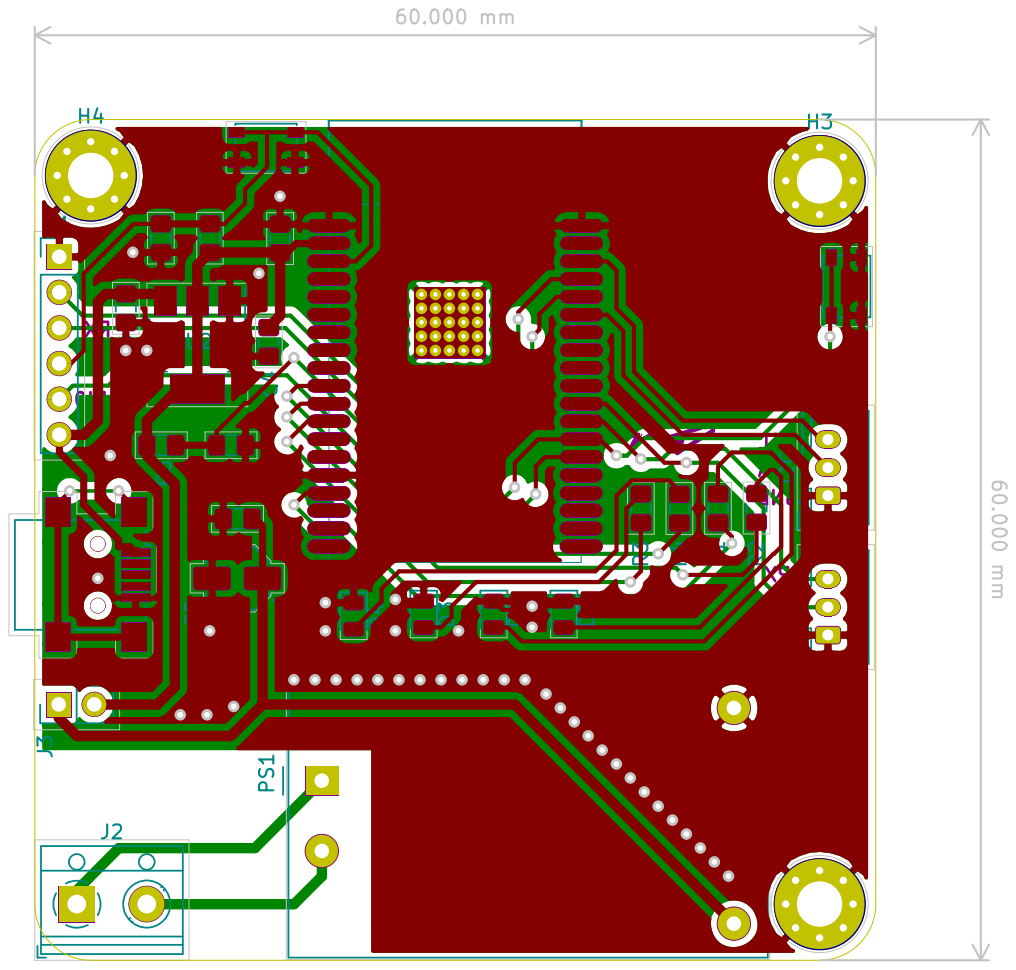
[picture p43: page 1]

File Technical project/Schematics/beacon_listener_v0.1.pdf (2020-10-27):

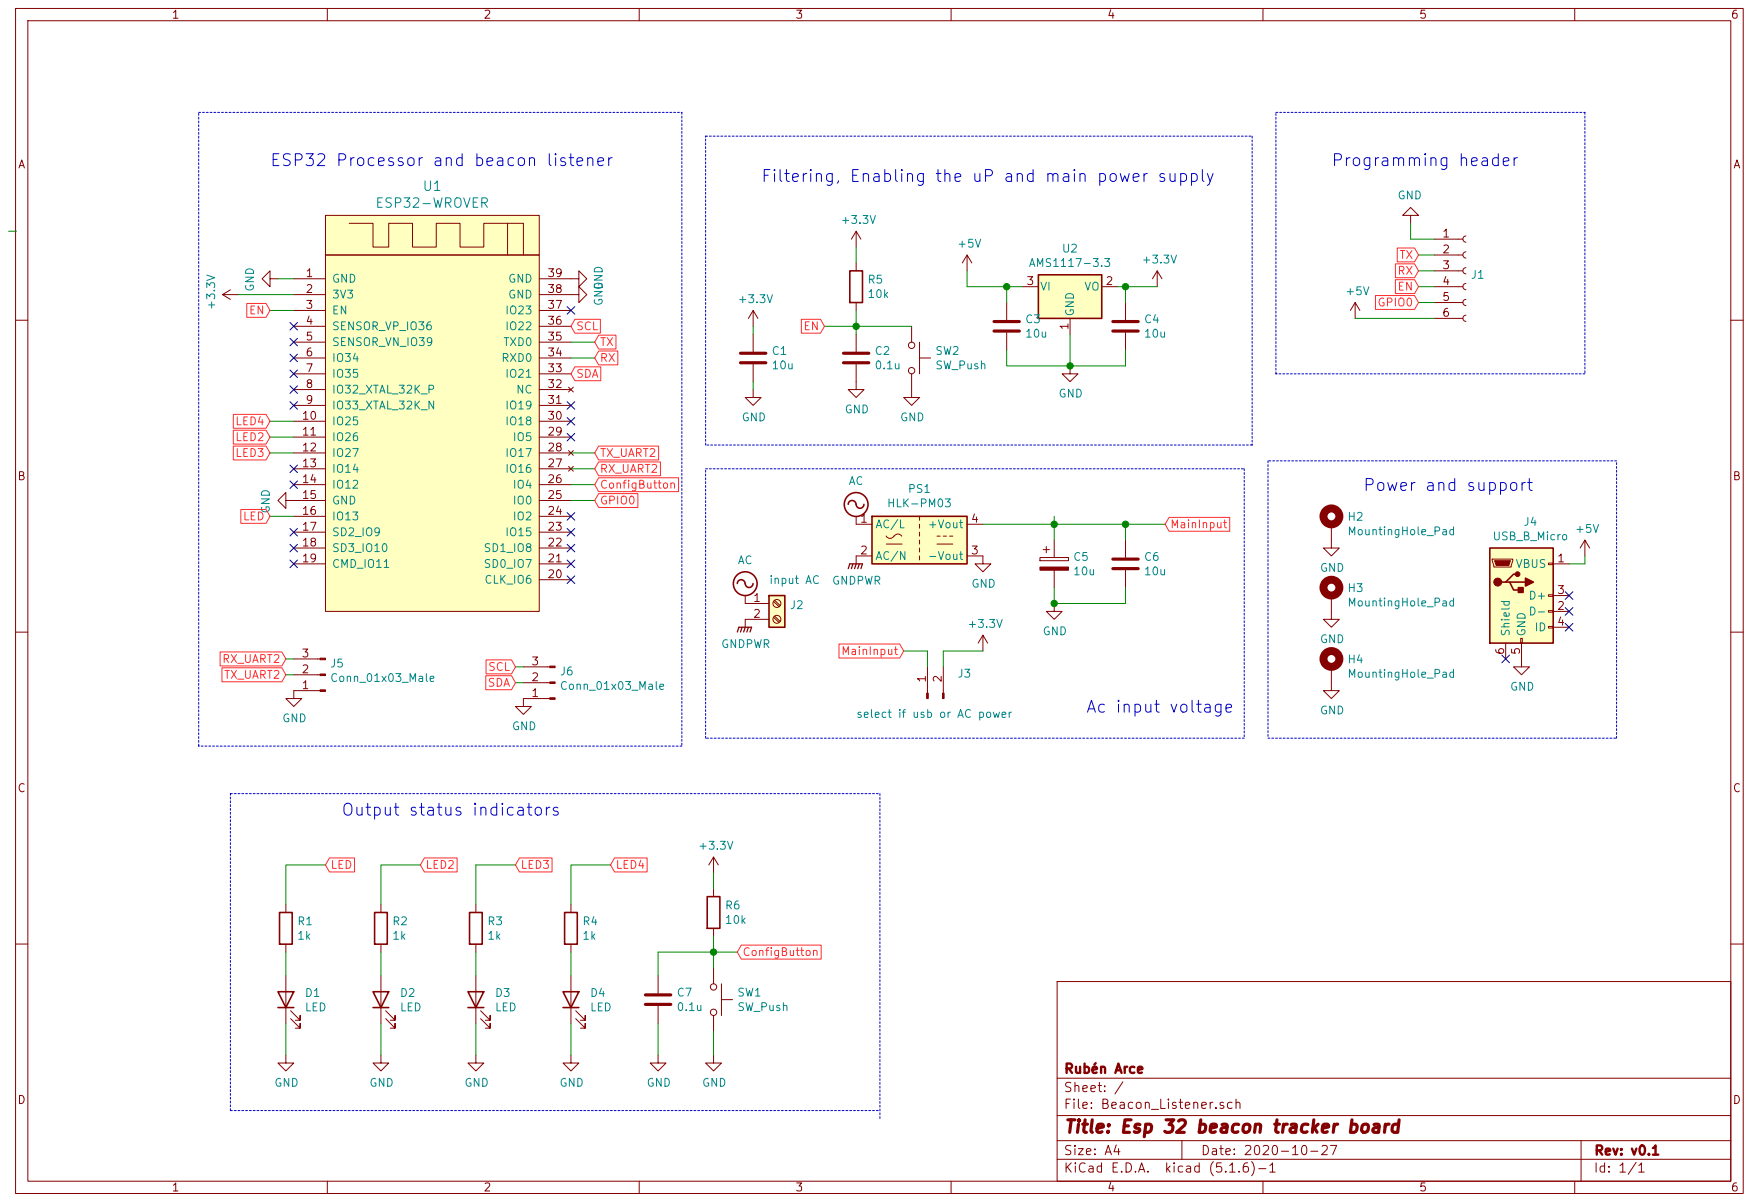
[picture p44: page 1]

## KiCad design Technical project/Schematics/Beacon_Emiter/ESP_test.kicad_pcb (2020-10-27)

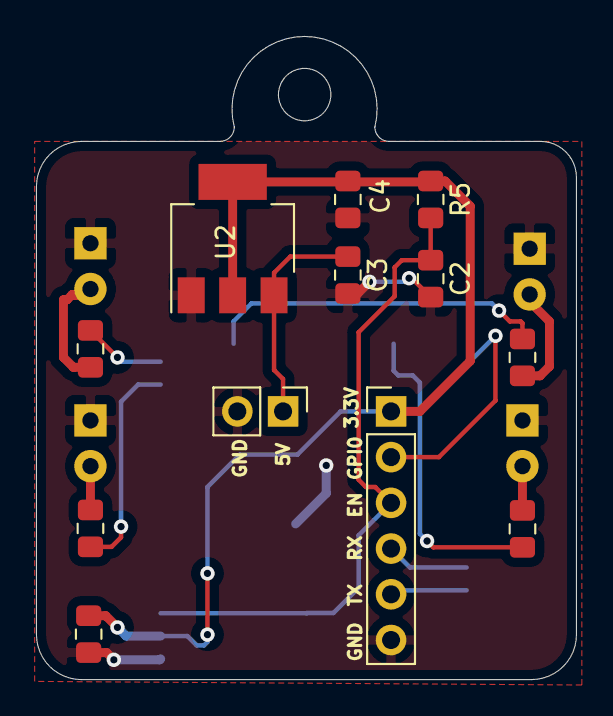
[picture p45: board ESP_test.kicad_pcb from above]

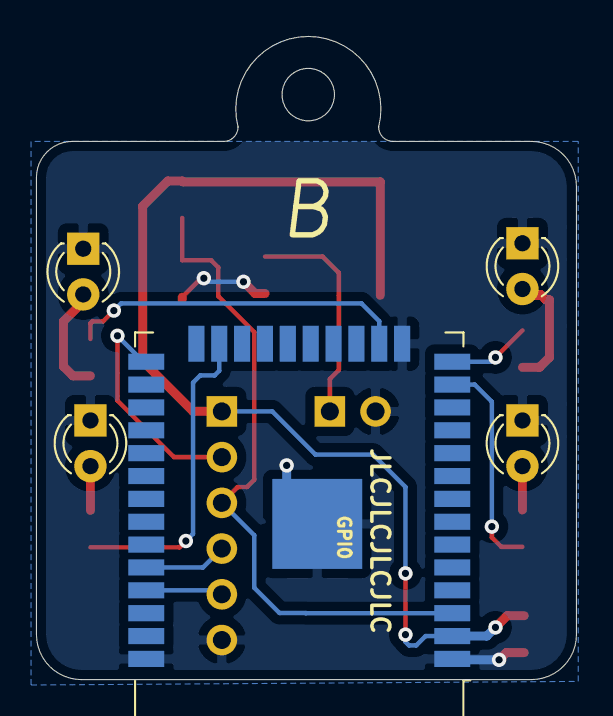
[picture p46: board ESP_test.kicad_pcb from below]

Board: 2 copper layers, 30.0 x 35.7 mm, 17 parts (5 on the bottom side), 15 nets.

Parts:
C1: C; C_0805_2012Metric_Pad1.15x1.40mm_HandSolder
C2: 0.1u; C_0805_2012Metric_Pad1.15x1.40mm_HandSolder
C3, C4: 10u; C_0805_2012Metric_Pad1.15x1.40mm_HandSolder
D1, D2, D3, D4: LED; LED_D3.0mm_Clear
J1: Conn_01x06_Female; PinHeader_1x06_P2.54mm_Vertical
J2: Conn_01x02_Female; PinHeader_1x02_P2.54mm_Vertical
R1, R2, R3, R4: R; R_0805_2012Metric_Pad1.15x1.40mm_HandSolder
R5: 10k; R_0805_2012Metric_Pad1.15x1.40mm_HandSolder
U1: ESP32-WROOM-32
U2: AMS1117-3.3; SOT-223-3_TabPin2

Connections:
EN: C2.1, J1.3, R5.2, U1.3
GND: C1.2, C2.2, C3.2, C4.2, D1.1, D2.1, D3.1, D4.1, J1.6, J2.2, U1.1, U1.15, U1.38, U1.39, U2.1
GPIO0: J1.2, U1.25
LED: R1.1, U1.14
LED2: R2.1, U1.16
LED3: R3.1, U1.13
LED4: R4.1, U1.23
unnamed: C3.1, J2.1, U2.3
unnamed: D1.2, R1.2
unnamed: D2.2, R2.2
unnamed: D3.2, R3.2
unnamed: D4.2, R4.2
RX: J1.4, U1.34
TX: J1.5, U1.35
VCC: C1.1, C4.1, J1.1, R5.1, U1.2, U2.2

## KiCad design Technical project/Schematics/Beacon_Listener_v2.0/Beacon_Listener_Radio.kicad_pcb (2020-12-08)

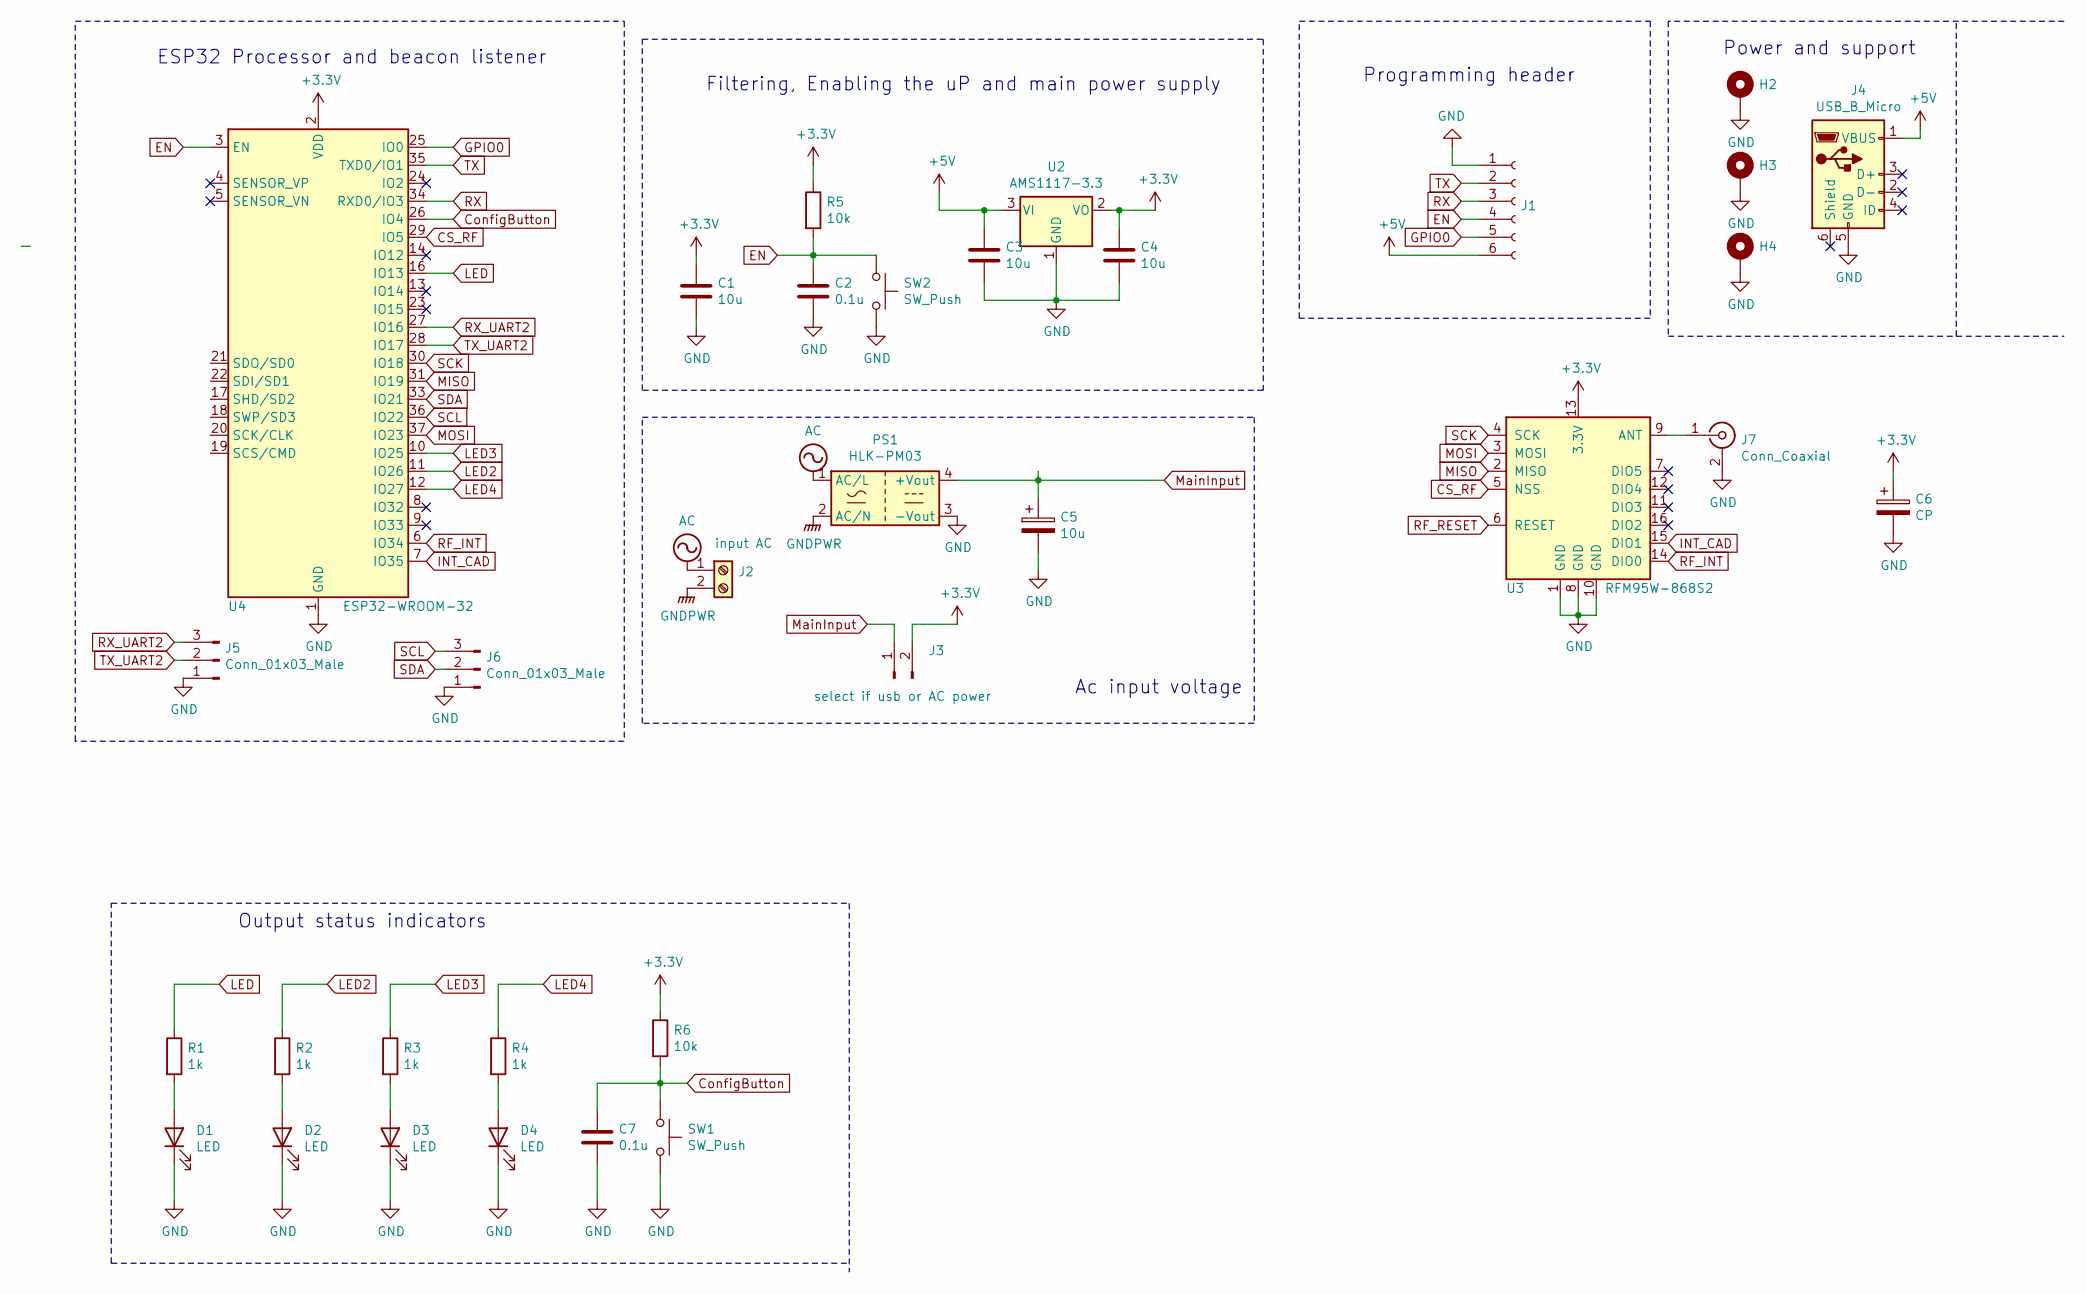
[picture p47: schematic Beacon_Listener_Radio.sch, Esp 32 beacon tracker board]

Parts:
C1, C3, C4: 10u; C_0805_2012Metric_Pad1.15x1.40mm_HandSolder
C2, C7: 0.1u; C_0805_2012Metric_Pad1.15x1.40mm_HandSolder
C5: 10u; CP_Elec_4x5.3
C6: CP; CP_EIA-3216-10_Kemet-I
D1, D2, D3, D4: LED; LED_0805_2012Metric
H2, H3, H4: MountingHole_Pad; MountingHole_3.2mm_M3_Pad_Via
J1: Conn_01x06_Female; PinHeader_1x06_P2.54mm_Vertical
J2: input AC; TerminalBlock_RND_205-00012_1x02_P5.00mm_Horizontal
J3: select if usb or AC power; PinHeader_1x02_P2.54mm_Vertical
J4: USB_B_Micro; USB_Mini-B_Lumberg_2486_01_Horizontal
J5, J6: Conn_01x03_Male; JST_PH_B3B-PH-K_1x03_P2.00mm_Vertical
J7: Conn_Coaxial; SMA_Amphenol_132134-10_Vertical
PS1: HLK-PM03; Converter_ACDC_HiLink_HLK-PMxx
R1, R2, R3, R4: 1k; R_0805_2012Metric_Pad1.15x1.40mm_HandSolder
R5, R6: 10k; R_0805_2012Metric_Pad1.15x1.40mm_HandSolder
SW1, SW2: SW_Push; SW_SPST_PTS810
U2: AMS1117-3.3; SOT-223-3_TabPin2
U3: RFM95W-868S2; HOPERF_RFM9XW_SMD
U4: ESP32-WROOM-32

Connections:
+3V3: C1.1, C4.1, C6.1, J3.2, R5.1, R6.1, U2.2 (VO), U3.13 (3.3V), U4.2 (VDD); also elsewhere on the board
+5V: C3.1, J1.6, J4.1 (VBUS), U2.3 (VI)
AC: J2.1, PS1.1 (AC/L)
CS_RF: U3.5 (NSS), U4.29 (IO5); also elsewhere on the board
ConfigButton: C7.1, R6.2, SW1.1, U4.26 (IO4); also elsewhere on the board
EN: C2.1, J1.4, R5.2, SW2.1, U4.3 (EN)
GND: C1.2, C2.2, C3.2, C4.2, C5.2, C6.2, C7.2, D1.1 (K), D2.1 (K), D3.1 (K), D4.1 (K), H2.1, H3.1, H4.1, J1.1, J4.5 (GND), J5.1, J6.1, J7.2 (Ext), PS1.3 (-Vout), SW1.2, SW2.2, U2.1 (GND), U3.1 (GND), U3.8 (GND), U3.10 (GND), U4.1 (GND), U4.15 (GND), U4.38 (GND), U4.39 (GND); also elsewhere on the board
GNDPWR: J2.2, PS1.2 (AC/N)
GPIO0: J1.5, U4.25 (IO0)
INT_CAD: U3.15 (DIO1), U4.7 (IO35); also elsewhere on the board
LED: R1.1, U4.16 (IO13)
LED2: R2.1, U4.11 (IO26)
LED3: R3.1, U4.10 (IO25)
LED4: R4.1, U4.12 (IO27)
MISO: U3.2 (MISO), U4.31 (IO19); also elsewhere on the board
MOSI: U3.3 (MOSI), U4.37 (IO23); also elsewhere on the board
MainInput: C5.1, J3.1, PS1.4 (+Vout)
unnamed: D1.2 (A), R1.2
unnamed: D2.2 (A), R2.2
unnamed: D3.2 (A), R3.2
unnamed: D4.2 (A), R4.2
unnamed 22: J7.1 (In), U3.9 (ANT); also elsewhere on the board
RF_INT: U3.14 (DIO0), U4.6 (IO34); also elsewhere on the board
RX: J1.3, U4.34 (RXD0/IO3)
RX_UART2: J5.3, U4.27 (IO16)
SCK: U3.4 (SCK), U4.30 (IO18); also elsewhere on the board
SCL: J6.3, U4.36 (IO22)
SDA: J6.2, U4.33 (IO21)
TX: J1.2, U4.35 (TXD0/IO1)
TX_UART2: J5.2, U4.28 (IO17)

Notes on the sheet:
ESP32 Processor and beacon listener
Filtering, Enabling the uP and main power supply
Output status indicators
Programming header
Ac input voltage
Power and support

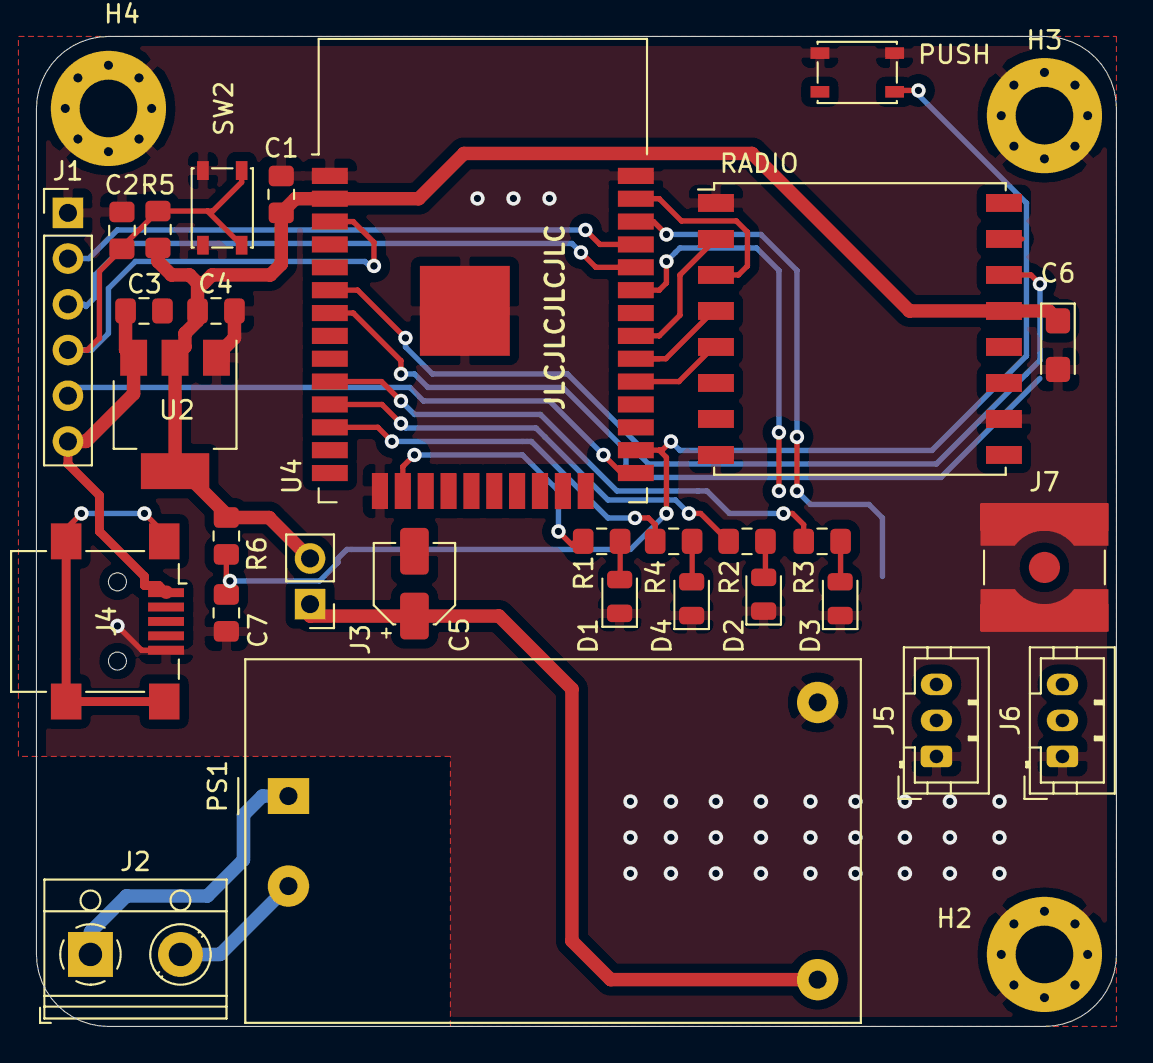
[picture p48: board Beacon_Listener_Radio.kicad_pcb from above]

Board: 2 copper layers, 60.0 x 55.0 mm, 33 parts (0 on the bottom side), 30 nets.

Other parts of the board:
PUSH: SW_Push; SW_SPST_PTS810
RADIO: RFM95W-868S2; HOPERF_RFM9XW_SMD

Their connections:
+3V3: RADIO.13; also elsewhere on the board
CS_RF: RADIO.5; also elsewhere on the board
ConfigButton: PUSH.1; also elsewhere on the board
GND: PUSH.2, RADIO.1, RADIO.8, RADIO.10; also elsewhere on the board
INT_CAD: RADIO.15; also elsewhere on the board
MISO: RADIO.2; also elsewhere on the board
MOSI: RADIO.3; also elsewhere on the board
unnamed 22: RADIO.9; also elsewhere on the board
RF_INT: RADIO.14; also elsewhere on the board
SCK: RADIO.4; also elsewhere on the board

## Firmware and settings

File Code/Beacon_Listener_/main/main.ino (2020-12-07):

#include "header.h"
#include "wifi_config.h"
#include "app_responses.h"
// #include <WiFi.h>
#include <BLEDevice.h>
#include <BLEUtils.h>
#include <BLEScan.h>
#include <BLEAdvertisedDevice.h>
#include <BLEAddress.h>
#include <BLEUUID.h>

// #include <PubSubClient.h>
// #include <ArduinoJson.h>

#define LED_GREEN 25
#define LED_RED 26
#define LED_ORANGE_UP 27
#define LED_ORANGE_DOWN 13

#define mqtt_port 1883
#define MQTT_USER "d"
#define MQTT_PASSWORD "d"
#define MQTT_SERIAL_PUBLISH_CH "master_beacon"
#define MQTT_SERIAL_RECEIVER_CH "master_beaconn"
#define DEBUG
#ifdef DEBUG
#define DPRINT(x) Serial.println(x)
#else
#define DPRINT(x)
#endif

int scanTime = 2; //In seconds
BLEScan *pBLEScan;
bool match;
unsigned long schedule = 0;
long timerMatch = 0;
long timerScan = 0;
#define uS_TO_S_FACTOR 1000000 /* Conversion factor for micro seconds to seconds */
#define TIME_TO_SLEEP 1        /* Time ESP32 will go to sleep (in seconds) */
RTC_DATA_ATTR int bootCount = 0;

void print_wakeup_reason()
{
  esp_sleep_wakeup_cause_t wakeup_reason;

  wakeup_reason = esp_sleep_get_wakeup_cause();

  switch (wakeup_reason)
  {
  case ESP_SLEEP_WAKEUP_EXT0:
    DPRINT("Wakeup caused by external signal using RTC_IO");
    break;
  case ESP_SLEEP_WAKEUP_EXT1:
    DPRINT("Wakeup caused by external signal using RTC_CNTL");
    break;
  case ESP_SLEEP_WAKEUP_TIMER:
    DPRINT("Wakeup caused by timer");
    break;
  case ESP_SLEEP_WAKEUP_TOUCHPAD:
    DPRINT("Wakeup caused by touchpad");
    break;
  case ESP_SLEEP_WAKEUP_ULP:
    DPRINT("Wakeup caused by ULP program");
    break;
  default:
    Serial.printf("Wakeup was not caused by deep sleep: %d\n", wakeup_reason);
    break;
  }
}

class MyAdvertisedDeviceCallbacks : public BLEAdvertisedDeviceCallbacks
{
  void onResult(BLEAdvertisedDevice advertisedDevice)
  {
    // Serial.printf("Advertised Device: %s ", advertisedDevice.toString().c_str());
    int rssi = advertisedDevice.getRSSI();
    // if (advertisedDevice.haveServiceUUID())
    // {
    //   // Serial.printf("Name -> %s", advertisedDevice.getServiceUUID().toString().c_str());
    // }
    //Serial.printf(", rssi -> %i \n", rssi); advertisedDevice.getName()
    const char *macAdress = advertisedDevice.getAddress().toString().c_str();
    //c4:64:e3:f9:35:b3 black
    //e6:13:a7:0b:4f:b2 white
    char *knownAdress = "c4:64:e3:f9:35:b3";
    char *knownAdress_2 = "e6:13:a7:0b:4f:b2";
    Serial.printf(" Adress: %s // RSSI: %d \n", macAdress, advertisedDevice.getRSSI());
    //Serial.printf("Searching for: %s \n", knownAdress);
    int val1 = 0;
    int val2 = 0;

    for (int i = 0; i < 10; i++)
    {
      if (knownAdress[i] == macAdress[i])
        val1++;
      if (knownAdress_2[i] == macAdress[i])
        val2++;
    }
    // if (val1 > 8 || val2 > 8)
    // {
      char snum[25];
      //I calculate the aproximate distance:
      double distance = 0.0012f * rssi * rssi - 0.0395f * (-rssi) + 0.1818;
      itoa(rssi, snum, 10);

      match = true;
      timerMatch = millis();
      digitalWrite(LED_ORANGE_UP, HIGH);
      digitalWrite(LED_ORANGE_DOWN, HIGH);

      const size_t capacity = JSON_ARRAY_SIZE(2) + 3 * JSON_OBJECT_SIZE(2);
      DynamicJsonBuffer jsonBuffer(capacity);
      JsonObject &root = jsonBuffer.createObject();
      root["esp"] = "A5";
      JsonArray &beacon = root.createNestedArray("beacon");

      JsonObject &beacon_0 = beacon.createNestedObject();
      beacon_0["uuid"] = macAdress;
      beacon_0["distance"] = rssi;

      if (strcmp(macAdress, "") != 0)
      {
        char JSONmessageBuffer[100];
        root.printTo(JSONmessageBuffer, sizeof(JSONmessageBuffer));
        clientMQTT.publish("master_beacon", JSONmessageBuffer);
        DPRINT("I post  \n");
      }
    // }
    // clientMQTT.publish("master_beacon", "test");
  }
};

void setup()
{
  Serial.begin(115200);
  //I initialize the reset pin to the wifi:
  pinMode(BUTTON_RESET, INPUT);
  Serial.println(ESP.getFlashChipSize());
  //Start and led red on
  pinMode(LED_RED, OUTPUT);
  digitalWrite(LED_RED, HIGH);
  //Connect to wifi or try it at least:
  auto_wifi_connect();
  //Connect to mqtt and publish
  pinMode(LED_GREEN, OUTPUT);
  digitalWrite(LED_GREEN, HIGH);
  init_mqtt();
  //Connected to broker and led green on
  pinMode(LED_ORANGE_UP, OUTPUT);
  digitalWrite(LED_ORANGE_UP, LOW);

  pinMode(LED_ORANGE_DOWN, OUTPUT);
  digitalWrite(LED_ORANGE_DOWN, HIGH);
  uint32_t repeat_ble = millis();
  uint32_t repeat_mqtt = millis();

  while (true)
  {
    //Handler timers to publish:
    if (millis()-repeat_mqtt >=13000)
    {
      digitalWrite(LED, HIGH);
      // uint32_t isrCount = 0, isrTime = 0;
      // // Read the interrupt count and time
      // portENTER_CRITICAL(&timerMux);
      // isrCount = isrCounter;
      // isrTime = lastIsrAt;
      // portEXIT_CRITICAL(&timerMux);
      // Serial.print("Counter ISR:");
      // Serial.println(isrCount);
      // Serial.println(sys.selector_auto);
      // if (isrCount % 21 == 0)
      // {
        // publish_counter++;
        // char json[100];
        // DynamicJsonBuffer jsonBuffer(32);
        // JsonObject &root = jsonBuffer.createObject();
        // root.set("publish", publish_counter);
        // root.set("heap", esp_get_free_heap_size());
        // root.set("heap_min", esp_get_minimum_free_heap_size());
        // root.set("uptime", isrTime);
        // root.printTo(json);
        // client.publish((String(sys.uuid_) + "/uptime").c_str(), (const uint8_t *)json, strlen(json), false);
        // Serial.println("Publish");
        Serial.println(esp_get_free_heap_size());
        LOGLN("mqtt task");
        // clientMQTT.publish("master_beacon", "{test:true}");
        repeat_mqtt = millis();
      
      
    }
    if (millis() - repeat_ble >= 10000)
    {
      BLEDevice::init("");
      BLEScan *pBLEScan;
      pBLEScan = BLEDevice::getScan(); //create new scan
      pBLEScan->setAdvertisedDeviceCallbacks(new MyAdvertisedDeviceCallbacks());
      pBLEScan->setActiveScan(true); //active scan uses more power, but get results faster
      pBLEScan->setInterval(100);
      pBLEScan->setWindow(99); // less or equal setInterval value
      digitalWrite(LED_ORANGE_UP, HIGH);
      BLEScanResults foundDevices = pBLEScan->start(scanTime, false);
      DPRINT("Devices found: ");
      DPRINT(foundDevices.getCount());
      pBLEScan->clearResults(); // delete results fromBLEScan buffer to release memory
      digitalWrite(LED_ORANGE_UP, LOW);
      esp_bt_controller_deinit();
      repeat_ble = millis();
    }
        reconnect();


  }
}

void loop()
{
}

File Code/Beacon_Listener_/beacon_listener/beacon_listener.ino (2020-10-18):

#include <BLEDevice.h>
#include <BLEUtils.h>
#include <BLEScan.h>
#include <BLEAdvertisedDevice.h>
#include <BLEAddress.h>
#include <BLEUUID.h>
#include <string>
#define LED_GREEN 15
#define LED_RED 13
#define LED_ORANGE_UP 12
#define LED_ORANGE_DOWN 14
// Update these with values suitable for your network.
#define mqtt_port 1883
#define MQTT_USER "d"
#define MQTT_PASSWORD "d"
#define MQTT_SERIAL_PUBLISH_CH "master_beacon"
#define MQTT_SERIAL_RECEIVER_CH "master_beaconn"
// #define DEBUG
#ifdef DEBUG
#define DPRINT(x) Serial.println(x)
#else
#define DPRINT(x)
#endif

int scanTime = 2; //In seconds
BLEScan *pBLEScan;
bool match;
unsigned long schedule = 0;
long timerMatch = 0;
long timerScan = 0;
#define uS_TO_S_FACTOR 1000000 /* Conversion factor for micro seconds to seconds */
#define TIME_TO_SLEEP 2        /* Time ESP32 will go to sleep (in seconds) */

class MyAdvertisedDeviceCallbacks : public BLEAdvertisedDeviceCallbacks
{
  void onResult(BLEAdvertisedDevice advertisedDevice)
  {
    int rssi = advertisedDevice.getRSSI();
    const char *macAdress = advertisedDevice.getAddress().toString().c_str();
    //c4:64:e3:f9:35:b3 black
    //e6:13:a7:0b:4f:b2 white
    // Serial.printf("Advertised Device: %s \n", advertisedDevice.toString().c_str());
    // Serial.printf("Adress: %s // RSSI: %d \n\n", macAdress, advertisedDevice.getRSSI());
    Serial.printf("Name -> %s\n", advertisedDevice.toString().c_str());

    if (advertisedDevice.haveManufacturerData())
    {
      Serial.println("yas");
      const char *data = advertisedDevice.getManufacturerData().c_str();
      Serial.println(advertisedDevice.getManufacturerData().length());
      for (int i = 0; i < 10; i++)
      {
        Serial.write(data[i]);
      }
      // Serial.println(advertisedDevice.getManufacturerData().c_str());
    }
    char *knownAdress = "71:a4:50:f9:8e:1b";

    int val = 0;

    for (int i = 0; i < 10; i++)
      if (knownAdress[i] == macAdress[i])
        val++;

    if (val > 8)
    {
      match = true;
      timerMatch = millis();
      digitalWrite(LED_ORANGE_UP, HIGH);
      digitalWrite(LED_ORANGE_DOWN, HIGH);
    }
  }
};

void setup()
{
  Serial.begin(115200);
  Serial.println(millis());
  esp_sleep_enable_timer_wakeup(TIME_TO_SLEEP * uS_TO_S_FACTOR);
  DPRINT("Setup ESP32 to sleep for every " + String(TIME_TO_SLEEP) + " Seconds");
  pinMode(12, OUTPUT);
  pinMode(13, OUTPUT);
  pinMode(14, OUTPUT);
  pinMode(15, OUTPUT);
  digitalWrite(12, HIGH);
  digitalWrite(13, HIGH);
  digitalWrite(14, HIGH);
  digitalWrite(15, HIGH);

  BLEDevice::init("");
  pBLEScan = BLEDevice::getScan(); //create new scan
  pBLEScan->setAdvertisedDeviceCallbacks(new MyAdvertisedDeviceCallbacks());
  pBLEScan->setActiveScan(true); //active scan uses more power, but get results faster
  pBLEScan->setInterval(100);
  pBLEScan->setWindow(99); // less or equal setInterval value
  timerScan = millis();
  schedule = millis();

  BLEScanResults foundDevices = pBLEScan->start(scanTime, false);
  DPRINT("Devices found: ");
  DPRINT(foundDevices.getCount());
  // pBLEScan->clearResults(); // delete results fromBLEScan buffer to release memory
  DPRINT("TO SLEEP ");
  Serial.println(millis());
  digitalWrite(LED_RED, LOW);
  esp_deep_sleep_start();
}

void loop()
{
}

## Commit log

2020-09-25 search for specific device and led on
2020-09-26 calculate the distance to the node and obtein the formula rssi-distance
    [calculator_distance_rssi.xlsx]
2020-10-03 send the correct data to the backend, rssi and uuid
    [BEACON_SEND_DATA.ino]
2020-10-10 plot rssi in a table in order to filter
2020-10-11 remove debug prints
2020-10-11 beacon is not nrf, is also the esp32
2020-10-12 almost 100mA and 650ms on sending a beacon msg
2020-10-17 apply a no uuid filter
    [calculator_distance_rssi.xlsx]
2020-10-24 antenna and better structured
2020-10-27 add schematics and gerbers
    [Beacon_Listener-B_Cu.gbr, Beacon_Listener-B_Mask.gbr, Beacon_Listener-B_Paste.gbr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]
2020-10-29 more pictures of the pcb and better mechanical anexo explained
2020-10-30 explaned all the justification memmory
    [TIR_VAN.xlsx]
2020-10-31 3/5 of the memmory
    [calculator_distance_rssi.xlsx]
2020-10-31 invoices and finish the designs
    [TIR_VAN.xlsx, TIR_VAN_presupuesto.xlsx]
2020-11-04 integration on the new board
2020-11-07 it doesn't recognise callback
    [main.ino]
2020-11-28 gantt van and tir
    [TIR_VAN_presupuesto.xlsx]
2020-12-05 BLE scanners and senders via ESPnow
    [calculator_distance_rssi.xlsx]
2020-12-05 new pcb and this time with radio lora inside
    [Beacon_Listener-B_Cu.gbr, Beacon_Listener-B_Mask.gbr, Beacon_Listener-B_Paste.gbr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]
2020-12-06 rf95 module
    [Beacon_Listener_Radio.kicad_pcb, Beacon_Listener_Radio.sch]
2020-12-08 trilateration 3 devices
2020-12-08 radio module include on the 2 version of pcb
    [Beacon_Listener_Radio.kicad_pcb, Beacon_Listener_Radio.sch]
2020-12-16 almost finish memmory
    [TIR_VAN_presupuesto.xlsx]
2020-12-19 anexo de diseño de hardware - portada y revisado
2020-12-19 formato de documentos y portadas
2020-12-19 finish formatting all elements
    [Beacon_Listener-B_Cu.gbr, Beacon_Listener-B_Mask.gbr, Beacon_Listener-B_Paste.gbr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]
2020-12-19 fallo con archivos
    [Beacon_Listener-B_Cu.gbr, Beacon_Listener-B_Mask.gbr, Beacon_Listener-B_Paste.gbr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]
2021-01-16 bibliografía
    [TIR_VAN_presupuesto.xlsx]
2021-01-20 power point add especifications
2021-01-23 more details on the memmory and power point
2021-01-26 end memmory, waiting to the powerpoint
2021-02-08 end the power point, show on monday
